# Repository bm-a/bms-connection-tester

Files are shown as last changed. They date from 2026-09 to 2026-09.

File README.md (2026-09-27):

# JBD Smart BMS RS485 Responder + Relay Test Bench — ESP32-S3

A firmware + hardware design that impersonates a **JBD / Xiaoxiang Smart BMS**
over RS485 so you can test the **meter/display** — the meter is the device
under test, not a real BMS. The box pretends to be a healthy 14S pack,
answers the meter's JBD polls with golden or fault-injected values, and an
**8-relay sequencer** switches the meter's own functions in order, driven by
a button or the built-in web dashboard. Status LEDs report link state live:
**green = valid BMS traffic seen, red = bus silent**. No screens needed.

> **New to RS485 or the JBD protocol?** Start with the companion handbook:
> **[jbd-bms-rs485-handbook](https://github.com/bm-a/jbd-bms-rs485-handbook)** —
> how RS485 works, the MAX485 module up close, the JBD frame format with worked
> examples, shopping list with search terms, and a step-by-step build guide.
> (Also known as: JBD BMS emulator, Xiaoxiang BMS simulator/tester, smart BMS
> responder, RS485 battery emulator, e-rickshaw meter tester.)
>
> **No hardware handy?** Run the offline 3D bench simulator:
> **[bms-tester-sim](https://github.com/bm-a/bms-tester-sim)** — ESP32-S3 +
> MAX485 + meter + relays in the browser, exact ESP dashboard embedded.

| | |
|---|---|
| Targets | ESP32-S3 DevKitC-1 (8 MB) + ESP32-S3 N16R8 (16 MB + OPI PSRAM) + MAX485 + 8ch relay · Waveshare ESP32-S3-ETH-8DI-8RO board variant ([docs/waveshare.md](docs/waveshare.md)) |
| Protocol | JBD UART over RS485, 9600 8N1 (registers `0x03`/`0x04`/`0x05`) |
| Releases | **v2.8** current — FULL dashboard + Waveshare in one release · `v2.7` 3 dashboard variants · `v2.6` meter estimate · `v2.5` portal/schema/harness · `v2.4` Tasmota update · `v2.3.1` bench patch · `v2.3` relay bench · `v2.2` captive portal · `v2.1` web reliability · `v2.0` relay bench · `v1.2` RGB+N16R8 · `v1.0` frozen (ZIP + tag) |
| Tests | **184 passing** via `sh run_tests.sh` (native Unity + web + Waveshare board-backend) + 30-day soak + web contract |
| Firmware | `firmware/` (8 MB) + `firmware-n16r8/` (16 MB) one-file images, SHAs in their READMEs |
| Web UI | Always-on AP `BMS-Tester` → FULL dashboard (live SVG bench, relay tiles, spoof, OTA, console) — no office Wi-Fi needed |
| Build guides | [DIY build-it-yourself](docs/BUILD-DIY.md) · [Waveshare build](docs/BUILD-WAVESHARE.md) |

## Dashboard (v2.8)

One FULL dashboard on every build — relay names are NVS-persistent, and OTA
always pulls FULL so updating never strands a box. (The old CLASSIC/LITE
page variants are retired.)

| What you get |
|---|
| Everything: live SVG bench card, relay tiles + names, meters-today, sequence config, spoof, OTA, console |

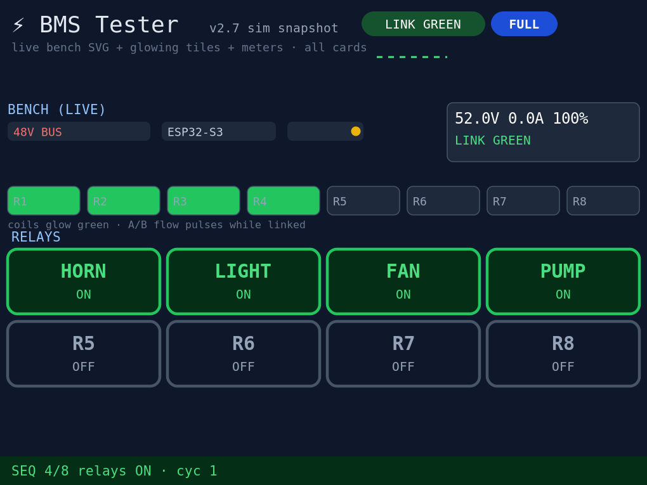
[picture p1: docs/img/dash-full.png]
FULL dashboard snapshot


*LINK pill + cycle counters, live bench strip (48V → ESP → MAX485 → meter readout), glowing relay tiles, meters-today — rendered from live sim state.*

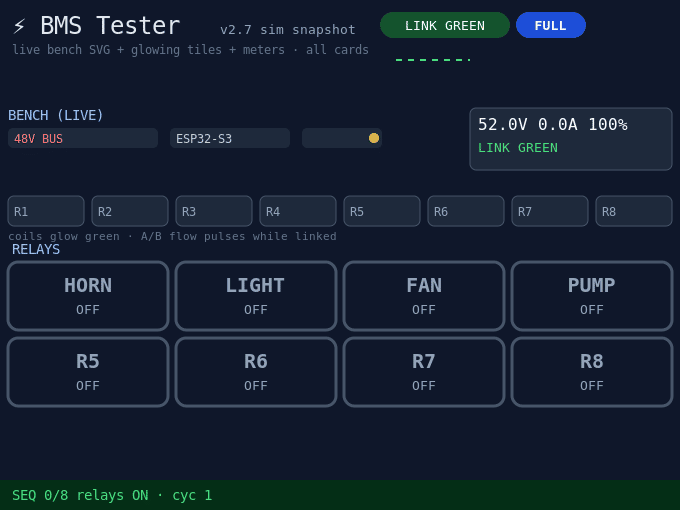
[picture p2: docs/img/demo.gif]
Sequential run + spoof demo


*R1→R8 sequential run, then a spoof FIRE driving the meter readout off golden — the same flow the 3D bench shows live.*

### Dashboard cards (FULL)

| Card | What it does |
|---|---|
| Bench (live) | Inline SVG bench card: 48 V → bucks → ESP → MAX485 with TX/RX dots → A/B flow → meter readout (`mv`/`ma`/`msoc`), 8 relay blocks glowing green. Zero CDN — works on the offline AP |
| Relays | START / STOP ALL buttons + 8 relay tiles. Tapping a tile forces it ON/OFF (`/api/relay`); forcing during CHASE idles the wave first so two relays never light at once |
| Meters today (approx) | `meters` / `attempts` / `pass` / `fail` + **New day (reset)** button. Software estimate, honestly labeled — see [Meter counter](#meter-counter) |
| Sequence config | Mode, relay count, step/hold, chase sweeps, stagger, direction, button behavior, logic, loop/pause/limit, Save. Only the active mode's fields are shown |
| Relay labels | 8 editable names, NVS-persistent (display-only; quotes/backslashes rejected) |
| Fault spoof (0x03 test values) | Pin-trigger enable + GPIO + polarity + Save trigger; stage 1 and stage 2 V/A/°C/SOC%/secs; FIRE now / Save only / Cancel |
| Firmware update | OTA status + latest tag; auto-check toggle + cadence (hours, 0 = manual); Check now / Install update; custom firmware URL + Upgrade from URL; **STA uplink** (enable + SSID/pass + Test uplink); **Backup configuration** (JSON download, passwords never included) + Restore from file |
| Admin & Wi-Fi AP | AP SSID / pass (8+, blank = keep) / channel (1–13); new admin pass (4+, blank = keep); auto-start sequence on boot (burn-in); Save / Save+reboot / Reboot / Factory reset / Reset settings (keep Wi-Fi) / Reset boot counter |
| Information | Firmware + variant, flash size, free sketch space, heap, uptime, boot count, reset reason, STA RSSI/IP, pin map for the board variant |
| Console | One-line command box: `START STOP FIRE CANCEL DAYRESET STATUS UPTIME VERSION REBOOT RESET HELP` — hardware verbs ask for the admin password |

The dashboard is open on the WPA2 AP — no login wall. Reboot, factory
reset, `/update` upload, OTA-admin and AP/admin saves ask for the admin
password **per request** (default `admin123`). Passwords never appear in
`/api/state`.

## JBD responder

The box is a virtual JBD BMS. It answers the meter's polls and nothing else:

| Register | Reply |
|---|---|
| `0x03` basic info | 52.0 V (`0x1450`), 0 A, 100 % SOC (`0x64`), 14 cells — byte-exact golden frame captured from a real pack |
| `0x04` cell voltages | 14 × 3714 mV = 52.0 V, checksum-verified synthesis |
| `0x05` device name | `TEST-14S100A` |
| writes / unknown registers | **silent** — no reply, still counted live |

- **Streaming parser + checksum**: every incoming frame is validated
  completely — line noise can never fake a link. Proven by a **10 M-byte
  structured fuzz** (pure random + valid-prefix mutations), zero emits.
- **Adaptive link window**: the green/red decision uses
  `clamp(2×EMA + 500 ms, 2 s, 10 s)` — self-adjusts to any meter poll speed.
  Green LED = well-formed frame seen inside the window; red = bus silent.
- **USB `STATUS?`**: send `STATUS?` over USB-serial (test-jig only, not a JBD
  command) → `GREEN 2.8` / `RED 2.8`. First token is stable for HIL fixtures.
- Protocol byte layout and checksum rule: [`docs/PROTOCOL.md`](docs/PROTOCOL.md).

## 8-relay sequencer

Switches the meter's own functions in order. Runs on `millis()` — no
`delay()` anywhere, RS485 keeps priority. Relays park **OFF** at boot;
all state resets clean.

| Mode | Behavior |
|---|---|
| Sequential 1-N | R1→Rn (or Rn→R1), each ON for the step delay, then the sequential hold |
| Chase wave | Single lit relay sweeping R1→Rn, wraps; **20 ms break-before-make** — each advance parks all-OFF first (release is slower than pull-in) |
| All ON at once | All N relays ON with optional stagger (0 = contactor slam, 20–1000 ms = inrush ramp) |

Config ranges (validate-then-commit: a rejected save changes **nothing**):

| Key | Range | Default |
|---|---|---|
| Relay count | 1–8 (beyond-N forced OFF; shrinking drops stale forces immediately) | 8 |
| Step ms | 100–60000 | 250 |
| Hold sequential ms | 0–3600000 (0 = stay ON) | 30000 |
| Chase sweeps | 0–100 (0 = forever; auto-hold = sweeps × relays × step) | 3 |
| Hold all-on ms | 0–3600000 (0 = stay ON) | 300000 |
| All-ON stagger ms | 0–1000 (0 = all at once) | 50 |
| Direction | R1→Rn / Rn→R1 | R1→Rn |
| Button | Hold X ms, re-press=OFF / Run to end, ignore presses / Re-press restarts | Hold X ms |
| Logic | Active-LOW (SmartElex) / Active-HIGH (no-op on Waveshare — TCA9554 bit HIGH = ON) | Active-LOW |
| Loop cycles | on/off + pause 500–60000 ms + cycle limit 0–60000 (0 = ∞) | off / 2000 / 0 |
| Auto-start on boot | burn-in racks | off |

Safety rules, enforced in firmware and host-tested:

- **0.5 s post-STOP dead-band** — START inside it is refused ("relays
  settling"); a refused start opens no attempt.
- **Mode switch needs IDLE** — switching mode with relays live is rejected.
- **Loop needs a finite hold** — hold 0 never expires, so loop + hold 0 is refused.
- **RESTART keeps tile forces**; count-shrink clears stale forces, never resurrects them.
- **Actuations counter** counts turn-ON edges only; **cyclesDone** counts
  completed cycles. Both surface on the dashboard and in `STATUS`.

## Meter counter

Software-only **estimate** of units tested per day — no button, no extra
GPIO, no RTC. The JBD protocol carries no meter ID, so the box watches link
gaps and applies one documented workflow assumption: a failed/retried test
does **not** unplug the meter (link stays GREEN); a new meter means a
physical reseat (link drops to RED for seconds).

- Link gap **≥ 3 s** arms a reseat **candidate**; the new meter **commits
  only after GREEN holds 5 s** (fumble guard — seat 4 s, pull, seat properly
  = one unit, not two).
- Sub-3 s flickers (slow poll, noise) stay on the same meter.
- Steady GREEN across RESTARTs/retries = same meter, however many attempts.
- The closing meter's verdict is snapshotted at arm time, so an eager START
  during the settle window attributes to the **new** meter.
- A **mid-cycle yank invalidates the test**: the previous meter closes as
  fail (no completed cycle while validly under test).
- Dashboard shows **meters / attempts / pass / fail** (pass = a full cycle
  completed before the swap). **New day (reset)** is manual — no RTC; boot
  persists (a power flicker never eats QC data); backups exclude counters.
- NVS is coalesced: **≤ 1 write per meter** — a power cut loses at most the
  current meter's attempts, stated on the card, not hidden.

## Fault spoof

Makes the meter display abnormal `0x03` data — tests how the **meter
renders** bad values. It does not trip real BMS protections (there is no
real BMS here). `0x04`/`0x05` never change.

Two stages, each fully editable (V/A/°C in ×0.1 units, SOC %, seconds):

| | V | A | °C | SOC | Secs | Range |
|---|---|---|---|---|---|---|
| Stage 1 (realistic full pack) | 100.0 | 100.0 | 100.0 | 100 % | 5 | values 0–999.9, secs 1–120 |
| Stage 2 (over-range pattern) | 88.8 | 88.8 | 88.8 | 188 % | 10 | values 0–999.9, secs 1–120 |

- **FIRE now** = save + fire; **Save only** stages values + pin without
  firing; **Cancel** aborts a running plan (auto-reverts after stage 2).
- **Trigger group**: enable + GPIO + polarity (pull-LOW to fire with
  pull-up / pull-HIGH to fire). Save trigger stores the triple without
  firing — for physical-switch users.
- Safe trigger pins, anything else falls back: generic boards
  `1, 2, 21, 38–44, 47` (fallback **21**); Waveshare `DI1–DI8`
  (`GPIO4–11`, active LOW, fallback **DI1**).

## Admin, network & OTA

- **Always-on AP** `BMS-Tester` (WPA2), fixed gateway **192.168.4.1**,
  captive portal with landing page (Safari/Chrome steps), mDNS
  **`bmstester.local`** for laptops/desktops. Turn mobile data off if the
  phone routes around the portal.
- **STA uplink** (optional, for GitHub OTA only — the AP stays on): enable +
  SSID + pass, one-shot **Test uplink** (joins ≤ 30 s without rebooting,
  reports RSSI/IP, drops back to AP-only).
- **OTA**: checks `https://api.github.com/repos/bm-a/bms-connection-tester/releases/latest`
  — one unified v2.8 line, Waveshare included. Exact variant-asset match
  (`firmware.bin` / `n16r8-firmware.bin` / `waveshare-firmware.bin`);
  Tasmota-grade gates: `0xE9` magic + flash-size-vs-chip gate on the first
  bytes, explicit sketch budget (never `SIZE_UNKNOWN`), exact variant match
  (no 8 MB ↔ N16R8 cross-flash). Auto-check cadence editable (0–720 h,
  0 = manual) + Check now + Install update. A wrong file or password changes
  nothing — the box keeps running.
- **Custom firmware URL** + **Upgrade from URL** (Tasmota OtaUrl style).
- **Manual `/update` upload**: works fully offline, progress bar, same gates.
- **Backup / Restore**: whole config as sectioned JSON
  (`relays`/`spoof`/`trigger`/`network`/`ota`/`meta`, `{"config":2,...}` —
  see [`docs/CONFIG-SCHEMA.md`](docs/CONFIG-SCHEMA.md)). **Passwords never
  leave the box** (they are in no section, by design). v1 flat backups still
  migrate.
- **Reboot** (flushes pending saves first), **Factory reset** (wipes NVS +
  reboots; also: hold the button 10 s), **Reset settings (keep Wi-Fi)** —
  wipes bench settings but keeps AP/STA/admin identity, **Reset boot
  counter** (no reboot needed).
- **Coalesced NVS saves**: config writes batch, never stall the loop.
- **Console verbs**: `START STOP FIRE CANCEL DAYRESET STATUS UPTIME VERSION
  REBOOT RESET HELP` — hardware verbs (`START STOP FIRE CANCEL DAYRESET
  REBOOT RESET`) require the admin password; `STATUS` prints link state,
  run state, cycles, actuations, spoof stage, and the meter counters.

## Hardware — generic DIY build

Full step-by-step: [docs/BUILD-DIY.md](docs/BUILD-DIY.md). Pin map:

| Module | Role | Pins |
|---|---|---|
| ESP32-S3 DevKitC-1 / N16R8 | Application MCU (240 MHz LX7, native USB) | UART2 TX = GPIO17, RX = GPIO16 |
| MAX485 (or SP3485) | Half-duplex RS485 transceiver | DI ← TX17, RO → RX16, DE+RE ← GPIO4 (**10 kΩ pull-down** — boots in listen mode, never jams the bus) |
| Green / red LEDs | Link indicator (mutually exclusive) | GPIO10 / GPIO11 via 220 Ω; GPIO48 RGB mirrors |
| 8ch relay module | Switches meter functions in sequence | IN1–8 ← GPIO5/6/7/8/9/12/13/14; **separate 12 V supply, common GND** |
| Button | Starts/stops sequences | GPIO15 to GND (pull-up); 10 s hold = factory reset |
| WiFi kill | Drops the AP | GPIO18 to GND (pull-up); ground = AP off, release = restore |
| Spoof trigger | Fires the 2-stage plan | GPIO21 to GND (configurable, safe pins only) |

Power: USB for the ESP + 12 V for the relay coils. Full wiring, relay
supply, and troubleshooting in [`docs/MODULES.md`](docs/MODULES.md).

## Hardware — Waveshare ESP32-S3-ETH-8DI-8RO

Full step-by-step: [docs/BUILD-WAVESHARE.md](docs/BUILD-WAVESHARE.md).
Details in [`docs/waveshare.md`](docs/waveshare.md).

| Function | Mapping |
|---|---|
| Relays R1–R8 | TCA9554PWR @ I2C `0x20` (SDA42/SCL41); EXIO1–8 = bits 0–7, **bit HIGH = ON**; parked OFF at boot. The web "active-low" toggle is a **no-op** on this board |
| RS485 | Isolated transceiver, TX17/RX18, **hardware auto direction** — no DE pin |
| BOOT button | GPIO0 = START/STOP (holding at power-on enters download mode — normal) |
| DI1 (GPIO4) | Spoof trigger (default, web-changeable; DI1–DI8 = GPIO4–11, opto-isolated, active LOW) |
| DI2 (GPIO5) | WiFi kill (default; ground = AP off) |
| RGB status | GPIO38 |
| W5500 Ethernet | Pins reserved, **not implemented** — Wi-Fi kept |

## Build environments

`platformio.ini` — one FULL dashboard on every build (classic/lite retired):

| Env | Board | What |
|---|---|---|
| `esp32-s3-devkitc-1` | ESP32-S3 8 MB | FULL dashboard (default) |
| `s3-n16r8` | 16 MB + OPI PSRAM | FULL dashboard, N16R8 flash/PSRAM map |
| `s3-waveshare` | Waveshare ESP32-S3-ETH-8DI-8RO | FULL dashboard, TCA9554 relays, isolated RS485 |
| `s3_tests` / `native` | host | on-target / host unit tests |

**v2.8 ships FULL (generic) + Waveshare.** OTA assets stay FULL on every
line so updating never strands a box.

## Flash it

- **Ready binaries (esptool, any PC):** `pip install esptool`, then one
  command per image — merged bootloader+partitions+app, structure-verified:
  `esptool.py --chip esp32s3 --port PORT --baud 460800 write-flash 0x0 <image>`
  - Generic 8 MB: `firmware/bms-tester-8mb.bin`
  - N16R8: `firmware-n16r8/bms-tester-n16r8.bin`
  - Waveshare: `bms-tester-waveshare.bin` (v2.8 release asset) at `0x0`
- **PlatformIO:** upload `esp32-s3-devkitc-1`, `s3-n16r8`, or `s3-waveshare`.
- **Arduino IDE:** open `arduino/bms_connection_tester/bms_connection_tester.ino`
  (all tabs open automatically; ESP32S3 Dev Module, USB CDC On Boot Enabled,
  921600; N16R8 also Flash 16MB + OPI PSRAM).

## Verify it

```sh
sh run_tests.sh          # 166 Unity tests: checksum, logic, parser, stress,
                        # relay, spoof, meter, ota, upload, web, system,
                        # waveshare board-backend + web contract + 30-day soak
pio test -e native       # host Unity suite (same asserts as run_tests.sh)
pio run -e esp32-s3-devkitc-1 -e s3-n16r8 -e s3-waveshare   # firmware compiles
```

- Socket harness (`tools/fw_emu`, real handlers over real HTTP): portal,
  relay flows, spoof/trigger, uploads, backup/restore, console, resets,
  STA/OTA, info, meter heuristic — PASS.
- 30-day soak (2.59 M polls, rollover crossed): PASS.
- Virtual bus (`sh tools/virtual_bus.sh`): 03/04/05 golden, silences,
  resync, red-after-silence — PASS.
- Dashboard + portal pages: `w3m -dump` renders verified; JS `node --check`
  clean; JS↔firmware contract gate green.
- HIL pytest (`tools/`) when a real ESP32-S3 + RS485 adapter is attached.
- QEMU-S3: parked (Stage-0 flash model clean; guest resets in 2nd-stage
  bootloader) — see HANDOFF.md.

## Versions

| Version | Highlights |
|---|---|
| **v2.8** | Meter counter hardened: 3 s gap arms a reseat candidate, new meter commits after GREEN holds **5 s** (fumble guard); verdict snapshotted at arm time (eager START attributes to the new meter); mid-cycle yank = fail. **Unified release line — Waveshare included**, OTA via `releases/latest` for all variants. Ships FULL (generic) + Waveshare. 166/166 tests |
| v2.7 | Three dashboard variants (FULL default + `s3-classic` + `s3-lite`), live SVG bench + meter readout (`mv`/`ma`/`msoc`), persistent relay names everywhere, OTA stays FULL. Waveshare `v2.7-ws1` prerelease line |
| v2.6 | Software-only daily meter estimate (link gaps = new meter, no button/GPIO), round link dots, one-file merged flash images, `test_meter` + web/emu meter coverage |
| v2.5 | Trigger save, portal landing, structured config (`docs/CONFIG-SCHEMA.md`), on-demand STA, whitespace-tolerant JSON, socket harness + 30-day soak |
| v2.4 | Tasmota-grade update path, per-mode relay menu (chase BBM, stop dead-band, timing floors), spoof save-only, console, backup/restore, custom OTA URL, STA uplink test, info card, mDNS, keep-WiFi/bootcount resets |
| v2.3.1 | No login wall (per-request admin password), sticky saves, UTF-8 pages, chase auto-sweeps, spoof trigger GPIO, WiFi kill switch (GPIO18), working OTA check + Install button |
| v2.3 | Relay count + chase, 2-stage spoof, per-mode ms holds, industrial pack (loop/pause/limit/stagger/direction/labels/counters/autostart), persistent logins, manual + auto OTA, coalesced saves |
| v2.2 | Captive portal (login page pops on join) + fixed 192.168.4.1 |
| v2.1 | Website reliability: 14 host-executed web tests + contract gate, 24 h office-day sim |
| v2.0 | 8-relay sequencer + always-on AP dashboard + spoof window + admin auth. Responder core frozen |
| v1.2 | Onboard RGB mirror (GPIO48) + N16R8 16 MB/OPI build + Wokwi NeoPixel |
| v1.1 | Multi-register (03/04/05) + adaptive window + silence-on-unknown + hardened parser |
| v1.0 | 0x03-only responder, fixed 2 s window. Frozen: `releases/bms-connection-tester-v1.0.zip` + tag |

See [`CHANGELOG.md`](CHANGELOG.md) for full notes.

## Layout

`src/` firmware (protocol core + relay ctrl + web UI + OTA logic) ·
`docs/` module + protocol docs + the two build guides ·
`test/` 166 Unity tests · `tools/` socket harness, virtual bus, soak, HIL
pytest, QEMU script · `arduino/` IDE sketch · `firmware/` 8 MB one-file
image · `firmware-n16r8/` N16R8 one-file image · `wokwi/` browser sim ·
`local-wokwi/` offline 3D bench (sim server + Three.js bench + verbatim ESP
page) · `enclosure/` IP65 standalone box + GX16 meter link docs ·
`captures/` Docklight recordings · `scripts/` Linux/Termux setup ·
`wiki/` wiki sources (mirrors the [GitHub wiki](../../wiki)) ·
`.github/workflows/` CI.

Docs: [`docs/MODULES.md`](docs/MODULES.md) (wiring, relay supply, power,
troubleshooting) · [`docs/PROTOCOL.md`](docs/PROTOCOL.md) (byte layout,
checksum) · [`docs/CONFIG-SCHEMA.md`](docs/CONFIG-SCHEMA.md) (backup shape,
validation, migration) · [`docs/waveshare.md`](docs/waveshare.md) (board
variant) · [`docs/EMULATION-v2.5.md`](docs/EMULATION-v2.5.md) (harness
methodology). Wiki: [Home](../../wiki/Home) · [Hardware](../../wiki/Hardware)
· [Relays](../../wiki/Relays) · [Dashboard](../../wiki/Dashboard) ·
[Protocol](../../wiki/Protocol) · [Flashing](../../wiki/Flashing) ·
[Emulators](../../wiki/Emulators) · [Versions](../../wiki/Versions).

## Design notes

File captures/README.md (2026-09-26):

# captures/ — original recordings (ground truth)

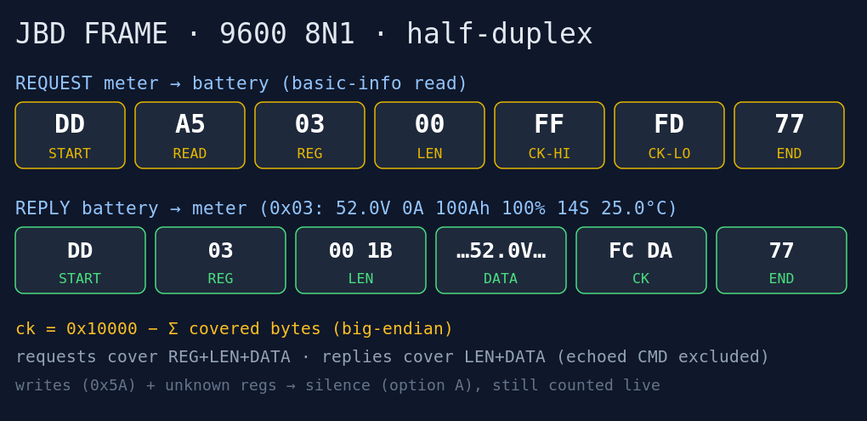
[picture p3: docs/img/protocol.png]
JBD frame map


- `SOC-DOCKLIGHT.xlsx` — raw Docklight captures from the real battery + real meter:
  the fixed `DD A5 03 00 FF FD 77` request, SOC 100 % / 50 % replies, a 90 %/45 °C
  long frame, two 0x2A variants, charge/discharge frames, and a Modbus RTU frame
  also seen on the bus (`01 03 00 00 00 1D 85 C3`, out of scope).

Used as regression vectors in `test/test_checksum/`. Frames whose checksums match
no formula (charge/discharge captures) are documented and excluded, not used.

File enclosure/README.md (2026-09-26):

# Standalone tester enclosure — IP65 box + 48 V dual-buck + GX16 meter link
v2.6 · software builder + dad (electronics) split. Every electrical value dad
owns is marked `DAD:` — software never guesses amps.

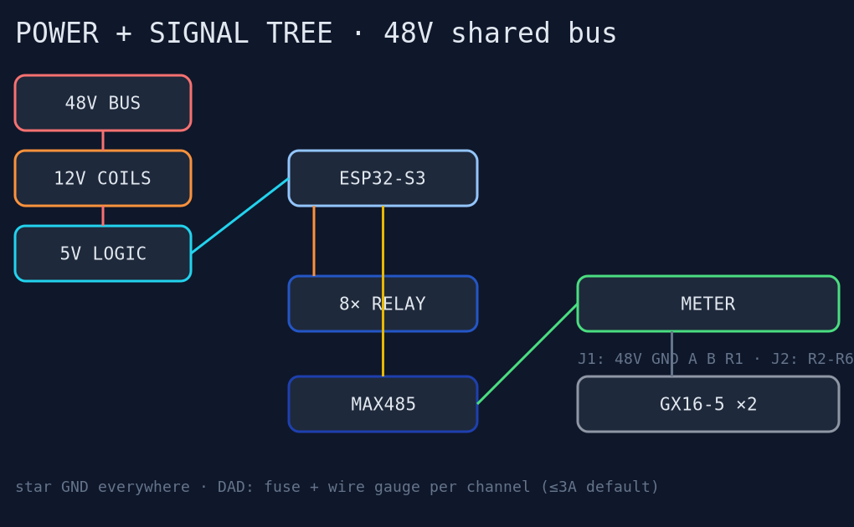
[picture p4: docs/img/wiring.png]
Power and signal tree


The device this box tests — e-rickshaw meter cluster:

## Power tree (48 V shared with meter)
```
48V IN (shared bus, fused) ─┬─ buck 48→12V (coils only) ── relay JD-VCC
                            └─ buck 48→5V (logic) ── ESP 5V + MAX485 side
                            star GND: 48V GND = ESP GND = relay GND = meter GND
```
- `DAD:` 48 V inlet fuse rating + wire gauge (default print: logic 22 AWG, relay loads 18 AWG, 48 V feed 18 AWG — confirm).
- `DAD:` buck module part numbers + current ratings (coils ~8×75 mA + margin; logic ~1 W + WiFi radio margin — confirm).
- Reverse-polarity diode + TVS on 48 V inlet. Fuse holder accessible without opening lid.

## Box + panel (off-shelf IP65 polycarbonate ~240×190×90 mm — `DAD:` confirm size)
- Zones: left logic tray (S3 + MAX485 + DE 10 kΩ pulldown + 220 Ω LED resistors),
  middle 8-ch relay on standoffs, right power corner (2 bucks + fuse + TVS), lid desiccant + wiring label.
- Front panel (etched acrylic, charcoal + orange): green/red link bezels
  (GPIO10/11), RGB window (GPIO48), illuminated green START (GPIO15→GND, momentary),
  yellow SPOOF (GPIO21→GND, momentary), **maintained metal WiFi-kill toggle with
  guard cover (GPIO18→GND)** + amber "AP OFF" jewel, USB-C service pigtail with
  dust cap, QR → `192.168.4.1` + `bmstester.local`.
- Glands: PG9 48 V, PG7 RS485 A/B twisted pair, PG13.5 relay/GX16 tails.

## GX16-5 meter link (DEFAULT — dad replaces with real 10-pin table)
| Conn | 1 | 2 | 3 | 4 | 5 |
|---|---|---|---|---|---|
| J1 BUS | 48V | GND | A | B | R1 line |
| J2 LOADS | R2 | R3 | R4 | R5 | R6 |
| AUX pigtail | R7 | R8 | — | — | — |
`DAD:` overwrite this table with the meter's real pinout. Sim + 3D read
`sim_server.py GX16` dict — a 5-minute re-map, no rework. Relay COM feed:
tester pulls lines LOW, meter side sources its own lamp returns (`DAD:` confirm
dry-contact vs driven; if driven, add per-channel fuse ≤3 A default).

## Assembly + power-on test (dad's bench sheet)
1. Bucks first, no ESP: 48 V in → verify 12.0 V + 5.0 V at terminals (`DAD:` tolerances).
2. Logic: USB flash, boot RED → meter plugged via J1 → GREEN ≤1 s, serial polls 03/04/05.
3. Loads: web START → R1..R8 click in order → meter tell-tales follow (see sim).
4. Kill tests: J1 unplug → RED ~2 s; GPIO18 toggle → AP drops, USB STATUS? alive.
5. Soak: 1 h run, bucks warm-not-hot (`DAD:` thermal call), glands strain-relieved.

## Sim mapping (software side)
`local-wokwi/` mirrors all of the above: 48 V rail + both bucks + fuse lamp in 3D,
GX16 sockets with pin numbers, photo-textured meter, WiFi toggle (GPIO18),
`/esp/` exact firmware page in scrollable row. `/api/gx16` serves the live table.

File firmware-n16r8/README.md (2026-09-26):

# Ready-to-flash binaries — v2.8 (ESP32-S3 N16R8, 16 MB flash + OPI PSRAM)

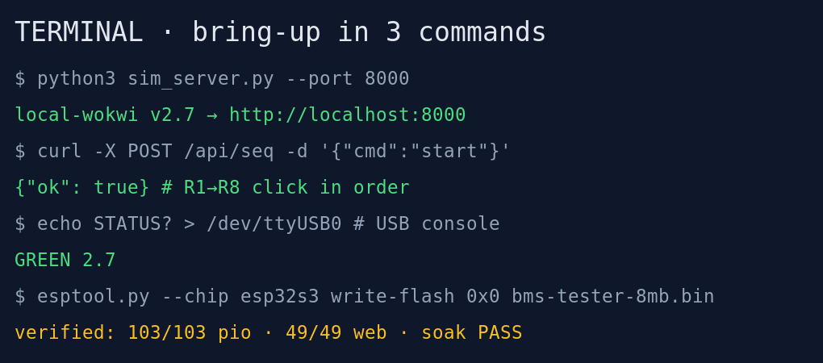
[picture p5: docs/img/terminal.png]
Bring-up terminal


Built 2026-09-27 from this exact source (`pio run -e s3-n16r8`,
Xtensa GCC 8.4.0, Arduino 2.0.x). Same firmware logic as `firmware/`,
only the flash/PSRAM map differs. Use for N16R8 boards (16 MB flash,
8 MB octal PSRAM, onboard WS2812 on GPIO48).

Includes the v2.8 bench (meter counter with 5 s settle fumble guard,
daily meter heuristic, round link dots, trigger save, portal landing,
structured config, on-demand STA, Tasmota-grade update path, per-mode
relay menu, console, backup/restore, info card,
mDNS) + always-on AP dashboard (`BMS-Tester`, captive portal, no login
wall) + 2-stage spoof (100 first, then 88.8/188) + manual/auto OTA.
v1.x responder behavior frozen.

## Flash with esptool — ONE file, ONE command (any PC, no IDE needed)
1. `pip install esptool`
2. Plug in the S3, find the port (COMx / /dev/ttyACM0), then:

```
esptool.py --chip esp32s3 --port <PORT> --baud 460800 write-flash 0x0 bms-tester-n16r8.bin
```

`bms-tester-n16r8.bin` is the merged image (bootloader + partitions + app
at their offsets) — one file, flashed to `0x0`, done.

## Or browser flash (no installs)
Open an ESP Web Tools flasher (e.g. https://www.espthings.io/tools/esp32-flasher/),
load `bms-tester-n16r8.bin` at `0x0`, flash, done.

## Or the 3 separate files (advanced / partial re-flash)
```
esptool.py --chip esp32s3 --port <PORT> --baud 460800 write-flash \
  0x0 bootloader.bin \
  0x8000 partitions.bin \
  0x10000 firmware.bin
```

## Verify
- `bms-tester-n16r8.bin` (1,078,304 bytes)
  SHA-256: `748355908e000215ef78ca9221db47167609278d3c90cba1361621e35c4f5676`
- `firmware.bin` (1,012,768 bytes)
  SHA-256: `e805e98220763dfd275b4cdfbe9d61e17d394e9abb99e5dd0ff03bf349c90aa6`
- `bootloader.bin` (15,104 bytes)
  SHA-256: `1776e4dd896a69d0a5c2e79957b0e2a88aa4129b1381d6478683515a1f6af343`
- `partitions.bin` (3,072 bytes)
  SHA-256: `bd0f7954aca2ef7d925ee21aaa1f3dc8822d1d6ce5cbbd26a135e5886bfff6ce`
- Golden reply bytes, `2.8` version, `BMS-Tester` AP name and dashboard
  strings verified byte-present inside `firmware.bin`; merged image verified
  (bootloader `E9` @0x0, partition magic @0x8000, app `E9` @0x10000).

Behavior: identical to the 8 MB build — boots red, relays OFF, AP up,
green on valid JBD polls (discretes + onboard RGB mirror).

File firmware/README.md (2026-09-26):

# Ready-to-flash binaries — v2.8 (ESP32-S3 DevKitC-1, 8 MB flash)

Bring-up terminal

Built 2026-09-27 from this exact source (`pio run -e esp32-s3-devkitc-1`,
Xtensa GCC 8.4.0, Arduino 2.0.x). Use for 8 MB boards and for Wokwi.
For 16 MB N16R8 boards use `firmware-n16r8/` instead (same logic, 16 MB map).

Includes the v2.8 bench (meter counter with 5 s settle fumble guard,
daily meter heuristic, round link dots, trigger save, portal landing,
structured config, on-demand STA, Tasmota-grade update path, per-mode
relay menu, console, backup/restore, info card,
mDNS) + always-on AP dashboard (`BMS-Tester`, captive portal, no login
wall) + 2-stage spoof (100 first, then 88.8/188) + manual/auto OTA.
v1.x responder behavior frozen.

## Flash with esptool — ONE file, ONE command (any PC, no IDE needed)
1. `pip install esptool`
2. Plug in the S3, find the port (COMx / /dev/ttyACM0), then:

```
esptool.py --chip esp32s3 --port <PORT> --baud 460800 write-flash 0x0 bms-tester-8mb.bin
```

`bms-tester-8mb.bin` is the merged image (bootloader + partitions + app at
their offsets) — one file, flashed to `0x0`, done.

## Or browser flash (no installs)
Open an ESP Web Tools flasher (e.g. https://www.espthings.io/tools/esp32-flasher/),
load `bms-tester-8mb.bin` at `0x0`, flash, done.

## Or the 3 separate files (advanced / partial re-flash)
```
esptool.py --chip esp32s3 --port <PORT> --baud 460800 write-flash \
  0x0 bootloader.bin \
  0x8000 partitions.bin \
  0x10000 firmware.bin
```

## Verify
- `bms-tester-8mb.bin` (1,075,808 bytes)
  SHA-256: `28248551fa8d32e061f75d46cb2bcd4559d1c40dd750e2422b412bf5353a98f8`
- `firmware.bin` (1,010,272 bytes)
  SHA-256: `27d5e25c86c0a97b383a55b326311cdd32296ec4772bbc243d645a4fe25616a8`
- `bootloader.bin` (15,104 bytes)
  SHA-256: `1776e4dd896a69d0a5c2e79957b0e2a88aa4129b1381d6478683515a1f6af343`
- `partitions.bin` (3,072 bytes)
  SHA-256: `1d9cca96de0fe07ad7fc0648b9878ddecd9ce565e38b589ad20fea698ed4c80c`
- Golden reply bytes (`DD 03 00 1B 14 50 … FC DA 77`), `2.8` version,
  `BMS-Tester` AP name and dashboard strings verified byte-present inside
  `firmware.bin`; merged image verified (bootloader `E9` @0x0, partition
  magic @0x8000, app `E9` @0x10000).

Behavior: boots red (discretes + onboard RGB), relays OFF (no click),
AP `BMS-Tester` up immediately; green ≤ 1 s after first valid JBD poll.

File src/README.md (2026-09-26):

# src/ — tester firmware

JBD frame map — what the parser speaks

- `bms_protocol.h` / `bms_protocol.cpp` — hardware-independent core (FROZEN
  since v1.x): JBD checksum, streaming parser, reply dispatcher (option A),
  adaptive tracker, canned frames, `FW_VERSION` (`"2.8"`).
- `relay_ctrl.h` / `relay_ctrl.cpp` — hardware-independent bench add-on:
  8-relay sequencer (sequential/all-ON/chase, relay count, 3 button behaviors,
  per-mode holds/sweeps, loop/pause/limit, stagger, direction, QC counters,
  chase break-before-make, post-stop dead-band, run-register snapshots),
  v2.6 `MeterBatch` link-gap meter heuristic (host-tested, no extra GPIO),
  debounced inputs, 2-stage spoof plan + frame builder, NVS-backed config
  struct. Host-tested (`test_relay`, `test_spoof`, `test_meter`).
- `fw_upload.h` — hardware-independent update gates (Tasmota rules: explicit
  sketch budget, exact variant-asset match, image-head check, one error
  vocabulary). Host-tested (`test_upload`); enforced by both update paths.
- `ota.h` / `ota.cpp` — hardware-independent OTA decision logic: version
  compare, per-variant asset pick, download URL, auto-check gate.
  Host-tested (`test_ota`); network I/O lives in `main.cpp` (ESP-only).
- `web_ui.h` / `web_ui.cpp` — ESP-only: always-on AP + captive portal, no login wall (admin password per sensitive request),
  per-mode dashboard (relays/sequence/labels/spoof/firmware/admin/info/console),
  NVS v3 load/save + v2 migration, STA uplink + one-shot test, Tasmota-grade
  manual `/update` upload, config backup/restore, custom OTA URL, mDNS.
  Host-tested on stubs (`test_web`).
- `main.cpp` — Arduino sketch: frozen RS485 RX → parse → reply path, 250 ms
  LED eval, `STATUS?` (`GREEN 2.6` / `RED 2.6`), plus relay/web/spoof/OTA
  handling (all non-blocking, RS485 keeps priority; v2.6 meter heuristic is
  fed inside `web_tick()`).

Pins: TX=17, RX=16, DE=4, green LED=10, red LED=11, onboard RGB=48 (WS2812,
`neopixelWrite`, no extra library), relays R1–R8 = 5/6/7/8/9/12/13/14,
button=15, spoof=21. UART2 @ 9600 8N1.
Compiles with `pio run -e esp32-s3-devkitc-1` (8 MB, Wokwi) or
`pio run -e s3-n16r8` (16 MB flash + OPI PSRAM).

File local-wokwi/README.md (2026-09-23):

# local-wokwi — offline browser simulator for this BMS tester

FULL dashboard snapshot

Sequential + spoof demo

Your own mini-Wokwi that runs on your phone / laptop with **no internet**.
Same idea as wokwi.com: virtual board + LEDs + buttons + relays + serial log,
driven by the real `../wokwi/diagram.json` wiring in this repo.

## Files

| File | What it is |
|---|---|
| `sim_server.py` | Localhost server (stdlib Python only, no pip packages). Loads `../wokwi/diagram.json`, ticks the simulation ~1/s, serves the UI + JSON API. |
| `bench3d.html` | **Default page (`/`).** True-3D bench (Three.js CDN): one tester ESP32-S3 + MAX485 module (DE direction LED) + e-rickshaw **meter device with live LCD** (V/A/Ah/SOC/cells/temp per polled register, spoof values appear on screen) + 8 relay modules with coil lamps + load lamps, color-coded tube wires, poll/reply pulse packets, orbit/zoom, tap-to-press buttons/meter keys/relay boxes. Below it: a fully interactive mirror of the real ESP32 webpage (relay grid, meters-today, sequence config, spoof card, console) + serial pane. `/board` keeps the old flat 2D view. |
| `board.html` | Legacy flat 2D bench (Wokwi-style SVG). Kept at `/board`. |

## Run (30 seconds)

```sh
cd ~/bms-connection-tester/local-wokwi
python3 sim_server.py --port 8000
```

Then open in any browser (phone Chrome works, offline OK):

```
http://localhost:8000
```

- ▶ **Play** / ⏸ **Stop** the sim clock.
- **Relay board row**: 8 glowing tiles (tap = force ON/OFF, IDLE-only lock
  like the box) + START/STOP + editable names that persist to
  `labels.json` (mirrors NVS labels on hardware) and sync into the `/esp/`
  page tiles.
- Tap any 3D **button** part (BUTTON / SPOOF / WiFi toggle / OTA check /
  FACTORY RESET-hold) — relays sequence, serial logs it.
- **Serial** pane shows the meter polling `DD A5 03/04/05 …` and the tester replying `52.0V 100Ah 100%`, green LED on.
- Dropdown loads the other portfolio demos too (`portfolio-01-relay-web`, `portfolio-02-climate-mqtt`, `portfolio-03-bms-rs485` from `~/firmware-gig-kit/demo-out/`).

## What it simulates (BMS tester mapping)

From `../wokwi/diagram.json` + `../wokwi/README.md`:

- `dut` (ESP32-S3) + `meter` (second S3 as virtual meter, UART cross-wired 17↔16) → serial shows the poll/reply loop.
- `ledG` / `ledR` → green = traffic seen / link good, red = bus silent (same semantics as the real box).
- `btn` (GPIO15) → runs the relay sequence on `rl1…rl8`; `spoofbtn` (GPIO21) → 10 s test values on the meter console.
- `rl1…rl8` (GPIO 5/6/7/8/9/12/13/14) → ON/OFF states shown live.

## Honest limits

- Runs firmware **logic models**, not the compiled ESP32 binary — same class of limit as Wokwi itself (which also doesn't emulate WiFi; see `../wokwi/README.md`).
- For bit-exact binary boot, use `~/esp32s3-qemu-arm64` on real Linux (QEMU JIT can't run inside Termux proot).
- For proof-grade firmware checks, use the repo's real gates: `pio test -e native`, `sh run_tests.sh`, `sh tools/check_ino.sh`.

## Why it exists (client trust)

Screen-record 30 s of Play ▶ + serial `BOOT …` + green LED and attach it to the
Fiverr/Upwork delivery ZIP. Buyers who *see* the sim running approve 10× faster
than buyers who only get a `.bin`. See `~/firmware-gig-kit/GIGS.md` for the gig pack.

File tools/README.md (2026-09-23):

# tools/ — test helpers and scripts

Sequential + spoof demo — what the harnesses prove on the bench

- `virtual_meter.py` — PC program that pretends to be the meter. Scenario modes for
  bench testing without hardware:
  `python3 tools/virtual_meter.py PORT [--reg 03|04|05] [--period S] [--jitter S]`
  `[--mode normal|slowstop|noise|write|unknown] [--count N]`
- `test_hardware.py` — pytest hardware-in-loop: exact golden reply + GREEN→RED timing
  via `STATUS?`. Needs `HIL_BUS_PORT` (RS485 adapter) + `HIL_CDC_PORT` (S3 USB).
  Skips itself when no hardware is present.
- `run_qemu_s3.sh` — boots `firmware/firmware.bin` on an emulated ESP32-S3
  (Espressif QEMU fork) and checks `STATUS?`. Needs a **real Linux/Mac** — QEMU's JIT
  cannot start inside phone proot sandboxes (documented abort in static glib init).
- `dut_emu.cpp` + `raw_meter.py` + `virtual_bus.sh` — virtual-bus emulation
  without any ESP32 (Debian/proot or Linux, needs socat + g++): `dut_emu`
  links the real `src/bms_protocol.cpp` and speaks JBD over a PTY;
  `raw_meter.py` runs every scenario over raw-fd I/O (pyserial's modem ioctls
  fail on proot PTYs, so no pyserial here); `sh tools/virtual_bus.sh` runs
  the whole cycle in one shell and asserts RED→GREEN→RED. Exit 0 = PASS.
- `check_web_contract.py` — consistency gate: every dashboard `fetch()` has a
  firmware route, every element id exists (incl. dynamic `lblN` tile ids),
  every state key is emitted, every POSTed key is consumed (incl. `/api/ota`,
  `/api/meter` and the `/update` upload form). Runs in `run_tests.sh` + CI; exit 0 = PASS.
- `make_report.py` — generates the Word report (`RS485-Tester-Report.docx`).
- `fw_emu/` — socket harness: the REAL `web_ui.cpp` + relay + spoof served
  over real HTTP with virtual time. Build: `g++ -DARDUINO -I tools/fw_emu
  -I src src/bms_protocol.cpp src/relay_ctrl.cpp src/web_ui.cpp
  tools/fw_emu/emu_main.cpp -o fw_emu`, then `FW_EMU_PORT=18080 FW_EMU_CTL=18081
  ./fw_emu &`. Control port: `/__time?ms=N` (step clock),
  `/__link?up=` (STA uplink), `/__bus?up=` (RS485 bus LEDs + v2.6 meter
  heuristic), `/__update`, `/__flags`, `/__chip`, `/__nvs` (commit counter).
  Drivers: `drive_emu.py` (62 scenario checks) + `drive_soak.py` (48 virtual
  hours, 10 checks).

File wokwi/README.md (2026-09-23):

# wokwi/ — browser simulation (no hardware needed)

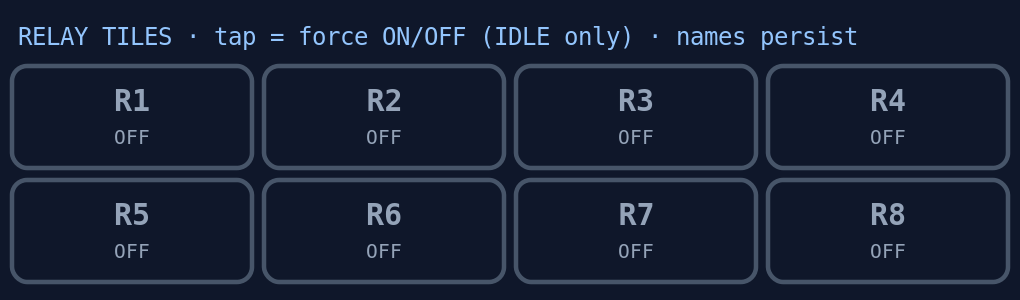
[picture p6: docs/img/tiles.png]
Relay tiles — the sim drives these


*Prefer offline? Same idea, phone-hosted, with 3D:
[local-wokwi/](../local-wokwi/) ([bms-tester-sim](https://github.com/bm-a/bms-tester-sim)).*

- `diagram.json` — ESP32-S3-DevKitC-1 + green/red LEDs + onboard RGB (NeoPixel
  on GPIO48: DIN/VDD/VSS per official docs) + **8 relay-module parts
  (GPIO 5/6/7/8/9/12/13/14, npn = energize-on-LOW like the real bench module,
  NO-contact indicator LEDs)** + button (GPIO15) + spoof button (GPIO21, both `1.l`/`2.l`
  per docs) + second S3 board acting as the meter (UART cross-wired,
  logic-level RS485 equivalent).
- `meter.ino` — virtual meter firmware: cycles registers 0x03/0x04/0x05 every second
  and prints whatever the tester replies.
- `wokwi.toml` — project config pointing at the PlatformIO build artifacts.
- `sim.yaml` — headless automation scenario (needs `WOKWI_CLI_TOKEN`):
  meter replies → button press → relay pins LOW in sequence → spoof press →
  `22 B0` on the meter console. CI runs it when the secret exists.

Open in wokwi.com (ESP32-S3 project), upload `firmware.bin` as custom firmware,
press play: watch the tester answer every poll and the LEDs follow. Press the
button to run the relay sequence (v2.0), the spoof button for 10 s test values
on the meter console. Attach the logic analyzer to TX/RX/DE to inspect the
half-duplex turn-around. (Wi-Fi dashboard is not emulated in Wokwi.)

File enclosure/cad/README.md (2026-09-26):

# Enclosure CAD — 3D-printable bench-station shell

Parametric FreeCAD models for the BMS connection tester enclosure.
Regenerate everything with:

```
freecadcmd build_enclosure.py   # base + lid2
freecadcmd build_parts.py       # tray
```

## Print set (3 parts)

| Part | File | Size (mm) | Notes |
|---|---|---|---|
| base | `base.stl` | 240 × 190 × 96 | Front panel: E-stop Ø22.5, START Ø19.2, SPOOF Ø16.2, WiFi kill Ø12.5, recessed reset, 2× LED Ø5, USB-C slot, QR recess. Rear: 4× M20 gland holes. Needs ≥250 mm bed |
| lid2 | `lid2.stl` | 248 × 198 × 18 | One-shot cover: integrated TFT mount (no separate bezel), vent slots, skirt, gasket groove. Print upside-down, no supports |
| tray | `tray.stl` | 226 × 176 × 28 | Internal mount: ESP32-S3 cradle, MAX485, 8-relay standoffs, buck mounts, fuse, 48 V barrier wall |

All module dimensions marked `VERIFY` in the scripts are typical values —
measure your actual hardware with calipers before printing.

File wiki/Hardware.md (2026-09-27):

# Hardware (v2.8 pin maps)

The thing under test — a real e-rickshaw meter cluster (dual-dial):

*Speed dial + battery %/V dial + tell-tales. The tester drives exactly this
over RS485 (readouts) + relay-switched lamp lines.*

Two supported hardware options. Pick one — the firmware auto-selects the
board at compile time (`s3-waveshare` env sets `-DBOARD_WAVESHARE_8DI8RO=1`).

## Option A — DIY (generic ESP32-S3)

Power and signal tree

*48 V shared bus → 12 V coils + 5 V logic → ESP → MAX485 → A/B → meter;
relays land on J1/J2/AUX. Full enclosure docs: `enclosure/README.md`.*

### MCU
ESP32-S3 DevKitC-1 (8 MB) or N16R8 (16 MB flash + 8 MB octal PSRAM),
dual-core LX7 @ 240 MHz, native USB CDC+JTAG. Arduino core 2.0.x.
Firmware envs: `esp32-s3-devkitc-1` (8 MB) vs `s3-n16r8`
(`board_build.flash_size = 16MB`, `board_build.psram_type = opi`,
`board_build.partitions = default_16MB.csv`).

### Pin map (unchanged since v2.0)
| Signal | Connection |
|---|---|
| S3 GPIO17 (TX) | → MAX485 DI |
| S3 GPIO16 (RX) | ← MAX485 RO |
| S3 GPIO4 | → MAX485 DE+RE tied (+ 10 kΩ pull-down to GND) |
| S3 GPIO10 | → 220 Ω → green LED → GND |
| S3 GPIO11 | → 220 Ω → red LED → GND |
| S3 GPIO48 | onboard WS2812 RGB (no wiring; mirrors green/red via `neopixelWrite`, brightness 32) |
| S3 GPIO5/6/7/8/9/12/13/14 | → relay module IN1–IN8 (12 V coils, own supply, common GND) |
| S3 GPIO15 | → button to GND (internal pull-up) — START/STOP + 10 s factory reset |
| S3 GPIO18 | → WiFi-kill to GND (internal pull-up) — ground = AP off |
| S3 GPIO21 | → spoof trigger to GND (internal pull-up; default, web-changeable) |
| MAX485 VCC / GND | 3.3 V (NOT 5 V) / common GND with meter |
| MAX485 A/B | → meter A/B, twisted pair; 120 Ω across A–B on long runs |

Avoided pins: strapping 0/3/45/46, USB-JTAG 19/20, flash/PSRAM 26–37,
console 43/44. UART2 @ 9600 8N1 via GPIO matrix.

### Spoof-trigger safe pins (DIY)
Only these GPIOs are accepted for the trigger pin; anything else falls back
to 21: **1, 2, 21, 38, 39, 40, 41, 42, 43, 44, 47**.

### LEDs
`apply_leds()` drives discretes as strict opposites and mirrors the same
state on the RGB (green = talking, red = silent). Boot red. RGB needs no
library and runs from the 250 ms eval, never the hot RX loop, so 9600-baud
timing is unaffected.

## Option B — Waveshare ESP32-S3-POE-ETH-8DI-8DO

All-in-one board (ESP32-S3-WROOM-1-N16R8: 16 MB flash + 8 MB OPI PSRAM):
8 digital outputs via expander, isolated RS485, 8 digital inputs, onboard
RGB — no external relay module, MAX485, or LEDs needed.

### Pin map
| Signal | Connection |
|---|---|
| Outputs DO1–DO8 | TCA9554PWR @ I2C `0x20` (SDA GPIO42 / SCL GPIO41); EXIO1–8 = output-register bits 0–7; **HIGH bit = ON** (Darlington sink). The dashboard *active-low* toggle is a no-op on this board — labels always match hardware. Outputs park OFF at boot. |
| RS485 | TX GPIO17 / RX GPIO18; direction on **GPIO21** via ESP32 UART **RS485 half-duplex mode** (official Waveshare demo pattern) |
| BOOT button | GPIO0 — START/STOP (holding it at power-on enters download mode; normal) |
| DI1 (GPIO4) | spoof trigger (default, web-changeable to any DI1–DI8) |
| DI2 (GPIO5) | WiFi kill (default) — ground = AP off |
| DI1–DI8 | GPIO4–GPIO11, opto-isolated, active = LOW (INPUT_PULLUP) |
| RGB | GPIO38 onboard WS2812 (no discrete green/red LEDs on this board) |

### Ethernet + buzzer (v2.9.0)
- GPIO12–16: **W5500 Ethernet is implemented** — SPI SCK15/MISO14/MOSI13,
  CS16, IRQ12, RST39, PHY addr 1. DHCP client, hostname `bms-tester`;
  the dashboard answers on the Ethernet IP too (`eth_ip` in `/api/state`,
  `ETH ip` in the Information card). Best-effort: any failure just skips
  Ethernet — boot, the AP (192.168.4.1), STA, captive portal and OTA policy
  are never affected.
- GPIO46: **buzzer is driven** — LEDC 1 kHz / 8-bit / duty ≤ 200 (official
  demo values). Beeps on meter-link up/down, sequencer start (200 ms) /
  stop (500 ms flicker), output-driver failure (5 s flickering alarm).
  Never driven before setup() (GPIO46 is a strapping pin).

### Reserved / unused (do not touch)
- GPIO40: RTC interrupt; GPIO41/42 shared with RTC @ 0x51.

### Spoof-trigger safe pins (Waveshare)
Only the DI screw terminals are user-drivable: **DI1–DI8 (GPIO4–11,
active LOW)**. Anything else falls back to DI1 (GPIO4).

## Power (both boards)
- **ESP + logic: USB 5 V** (use a real charger — the Wi-Fi AP radio is
  always on, ~1 W-class). Never power the ESP from the traction pack.
- **Relay coils: separate 12 V supply** (DIY: ≈ 30 mA/coil, ≈ 240 mA
  all-on). Tie coil-supply GND to ESP GND (common reference for the
  optoisolated inputs). Never power coils from USB/ESP pins.
- MAX485 VCC = 3.3 V, common GND with the meter.

> ⚠️ **Waveshare 8DO USB-OTG jumper:** when the jumper is set to
> **USB-OTG**, the Type-C port feeds the board from an external USB power
> supply. **Do not connect the board to a computer while the jumper is in
> the USB-OTG position.**

## RS485 bus wiring
- A/B twisted pair from the transceiver to the meter; 120 Ω termination
  across A–B on long runs.
- The Waveshare board's RS485 is **isolated** (SP3485); direction is driven
  on GPIO21 by the ESP32 UART's RS485 half-duplex mode — no DE/RE wiring
  needed on the bus side.

## Enclosure option
`enclosure/` documents an IP65 standalone box + GX16 meter-link sockets
for the DIY build (48 V shared bus → bucks → ESP/relays). The Waveshare
board is already DIN-rail friendly as-is.

Full module background: `docs/MODULES.md`. Build guides: [[Building]].
Relay/web details: [[Relays]], [[Dashboard]].

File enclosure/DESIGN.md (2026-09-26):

# BMS Connection Tester — Bench Station Enclosure Design

**Target:** `bm-a/bms-connection-tester` v2.7 (ESP32-S3 + MAX485 + SmartElex 8-ch relay + dual 48 V bucks)
**Concept:** turn the tester from a bench prototype into a proper **assembly-line QC station**:
one box, one GX16 plug, one START button, big PASS/FAIL on top. No laptop, no battery pack.
**Box baseline:** off-shelf IP65 polycarbonate ~240 × 190 × 90 mm (per `enclosure/README.md`; `DAD:` confirm).

> Convention: every electrical value the electronics owner must confirm is marked `DAD:` —
> software never guesses amps (repo convention, kept).

---

## 1. Use potential — what this box becomes

1. **Assembly-line QC station (primary).** Worker plugs the meter's GX16, presses START,
   watches the top display: link → 8 relay tell-tales sweep → PASS/FAIL + today's count.
   No laptop, no traction battery, ~30 s per meter.
2. **Field-service diagnostic.** Portable 48 V-powered box; technician fires SPOOF to force
   known voltage/current/SOC frames and verifies the meter reads correctly on-site.
3. **Burn-in / soak rig.** Loop + chase-wave modes cycle all 8 relays unattended; display
   shows cycle count and elapsed time.
4. **Training rig.** New line workers learn meter behavior against the two spoof stages
   (100 % → 88.8 V / 88.8 A / 88.8 % / 188 °C-clamped) without touching real packs.
5. **R&D regression.** New meter firmware is validated against frozen golden frames
   (0x03/0x04/0x05, checksums verified) before it ships.

---

## 2. Display on top

### Selection — 2.8" TFT (ILI9341, 320×240, SPI)

| Option | Pins | Verdict |
|---|---|---|
| **2.8" ILI9341 TFT, SPI (recommended)** | 5 GPIO | Big PASS/FAIL, 8-relay matrix, progress bar, readable at 1 m on a bench |
| 1.3" SH1106 OLED, I2C | 2 GPIO | Fallback: cheaper, text-only, fine if box must stay small |

A bench QC tool lives or dies on glanceability. The TFT wins.

### What it shows (screens)

- **BOOT:** logo, FW version, self-test (relay coils click once, bus silent → RED).
- **IDLE:** LINK status big (GREEN/RED), meter count today (pass/fail), AP IP + QR, relay names.
- **RUNNING:** progress bar R1→R8, current step highlighted, elapsed time, big STOP hint.
- **SPOOF:** stage 1/2 indicator with live V/A/SOC values being spoofed.
- **RESULT:** PASS / FAIL full-screen (green/red), latched until next START.
- **OTA/SETTINGS:** check result, version strings (rarely needed; web UI stays primary).

### Mounting

- Recessed window in the **lid**: 3D-printed bezel + foam gasket, display module on
  M2.5 standoffs behind a ~46 × 78 mm cutout (verify against actual module).
- Tilt: flat is fine for bench use; a 10–15° wedge riser under the box helps standing operators.
- Keep the SPI ribbon **short (<15 cm)** and routed away from relay coils (EMI).

### Pins (all currently free, non-strapping, no PSRAM conflict)

| Signal | GPIO |
|---|---|
| SCK | 38 |
| MOSI | 39 |
| CS | 40 |
| DC | 41 |
| RST | 42 |

Spare: GPIO1, 2, 47. (Used today: 4,5–9,10,11,12–14,15,16,17,18,21,48; avoided: 0,3,45,46,19,20,26–37,43,44.)

### Firmware work needed

New `src/display_ui.cpp`: SPI init, screen state machine driven off the existing
`RelaySequencer` state + link tracker. **Must be non-blocking** — update on state change
plus a 250 ms tick (same cadence as the LED eval); never `delay()` in the RS485 hot path.
Estimate: small, self-contained module + tests in the host harness style.

---

## 3. Buttons — full schedule

Firmware functions today: GPIO15 = START/STOP button (web-selectable: abort / run-lock / restart;
**10 s hold = factory reset**), GPIO21 = SPOOF trigger, GPIO18 = WiFi kill (maintained).

| # | Label | Function (GPIO) | Kind | Size | Placement | Notes |
|---|---|---|---|---|---|---|
| 1 | **START** | Seq start/stop (GPIO15) | Metal **illuminated** momentary, green ring, IP65 | 19 mm | Front panel, center — dominant | Ring lit while running. 10 s hold = factory reset → engrave "HOLD 10s = RESET" under it |
| 2 | **SPOOF** | Fire 2-stage spoof (GPIO21) | Metal momentary, yellow cap, IP65 | 16 mm | Front panel, left of START, ≥25 mm edge gap | Deliberate action; no guard needed, separation prevents mis-press with gloves |
| 3 | **WiFi KILL** | AP+portal off (GPIO18) | **Maintained** metal toggle + flip guard cover | 12 mm | Front panel, far right, isolated zone | Guard prevents accidental kill mid-test. Amber "AP OFF" jewel lamp beside it |
| 4 | **E-STOP** *(new, hardware-only)* | Cuts 48 V inlet (NC contact in series after fuse) | Red mushroom, latching, twist-release, 22 mm | 22 mm | Front panel top-right corner, unmissable | No firmware needed. `DAD:` contact current rating vs 48 V bus load |
| 5 | **RESET** | ESP32 EN (recessed tactile) | Recessed push, behind 3 mm hole | — | Side wall or front-panel corner | Paperclip access; recessed = no accidental press |
| 6 | *ENCODER (optional v2)* | Display menu nav | EC11 rotary + push | — | Below display on lid | Needs firmware menu system — defer |

**Why these kinds:** metal panel-mount buttons (not PCB tactiles) survive a line environment;
illuminated START gives state at a glance; maintained + guarded for the kill function is
standard industrial practice; E-STOP is non-negotiable once a shared 48 V bus is in a worker's hands.

**Placement rationale:** frequency ordering left→right (SPOOF → START → KILL);
destructive/rare actions (KILL, E-STOP) physically separated from the high-frequency START;
all within one hand's reach at bench height; engraved traffolyte labels, not stickers.

---

## 4. Panel layout

### Front panel (operator face, 240 mm wide)

```
┌──────────────────────────────────────────────────────────┐
│ [E-STOP]                              [KILL+guard] (AP OFF)│
│                                                          │
│ (SPOOF)    [      START      ]      (G)(R) [RGB]          │
│  yellow     green illuminated      link LEDs  window      │
│                                                          │
│ [USB-C service]            [QR → 192.168.4.1]             │
└──────────────────────────────────────────────────────────┘
```

### Lid (top)

```
┌──────────────────────────────────────────────────────────┐
│  ┌────────────────────┐                                   │
│  │                    │      [ QR plate ]                   │
│  │   2.8" TFT window  │      "BMS TESTER v2.7"              │
│  │   (bezel+gasket)   │                                   │
│  └────────────────────┘                                   │
└──────────────────────────────────────────────────────────┘
```

### Rear

- PG9 gland: 48 V inlet (fused, fuse holder accessible without opening lid)
- PG7 gland: RS485 A/B twisted pair to meter
- PG13.5 gland: relay tails / GX16 J1+J2+AUX
- Vent slots on side walls (never top — drip protection)

---

## 5. Enclosure construction & internal zones

```
┌────────────────── 240 ──────────────────┐
│ LEFT: logic tray        MID: relay       │ RIGHT: power
│ S3 devkit on M3         8-ch module on   │ corner: 2 bucks,
│ standoffs + MAX485 +    standoffs        │ fuse, TVS, reverse-
│ 10k pulldown + LED Rs                    │ polarity diode
│ ── low-voltage zone ── │ ── switched ── │ ── 48 V zone ──
└──────────────────────────────────────────┘
```

- **Stack-up:** base tray (3D-printed or polycarb sub-plate) holds all three zones;
  48 V zone gets a physical barrier wall (3 mm) from logic — separation by construction.
- **Lid:** display bezel + desiccant sachet + laminated wiring label inside.
- **Standoffs:** M3 brass heat-set inserts; S3 devkit ~52 × 28 mm, relay module ~138 × 56 mm
  (verify SmartElex dims), bucks ~43 × 21 mm class (verify).
- **Thermal:** bucks warm-not-hot (`DAD:` thermal call); side vents sized after soak test.

---

## 6. Internal wiring plan + safety maths

- **Power tree:** 48 V IN (fused) → buck 48→12 V (relay JD-VCC, coils ~8×75 mA + margin) →
  buck 48→5 V (logic: ESP + MAX485). Star GND at power corner: 48 V GND = ESP GND = relay GND = meter GND.
- **Gauges (defaults, `DAD:` confirm):** 48 V feed 18 AWG · relay loads 18 AWG · logic 22 AWG ·
  RS485 A/B twisted pair 22 AWG.
- **Fusing:** inlet fuse on 48 V (`DAD:` rating); per-channel ≤3 A if meter lines are driven
  rather than dry-contact (`DAD:` confirm dry-contact vs driven).
- **Clearance:** ≥3 mm between 48 V terminals and logic (IPC-2221 is lenient at 48 V, but the
  barrier wall makes it moot); keep mains nowhere near this box — 48 V DC only.
- **Strain relief:** every external cable lands on a gland + internal cable-tie anchor;
  relay tails get a service loop so the lid opens without tension.
- **Display SPI:** route away from relay coils; if flicker appears, twist SCK/MOSI with GND.
- **E-STOP wiring:** NC contact in series with 48 V *after* the fuse, before the bucks —
  kill is absolute, fusing stays intact.
- **Bench power-on order:** bucks first (no ESP) → verify 12.0/5.0 V (`DAD:` tolerances) →
  flash → RED boot → GX16 J1 in → GREEN ≤1 s → web START → R1..R8 sweep → kill tests →
  1 h soak.

---

## 7. Indicative BOM

| Part | Spec | Qty |
|---|---|---|
| IP65 polycarbonate box | ~240×190×90 | 1 |
| 2.8" ILI9341 TFT, SPI | 320×240 | 1 |
| Metal illuminated pushbutton, green | 19 mm, momentary, IP65 | 1 |
| Metal pushbutton, yellow | 16 mm, momentary, IP65 | 1 |
| Metal toggle + guard cover | 12 mm, maintained | 1 |
| E-stop mushroom, NC | 22 mm, latching twist-release | 1 |
| Amber jewel indicator | 12 V, panel mount | 1 |
| Green/red panel LEDs (bezels) | 12 mm | 2 |
| Cable glands | PG9 ×1, PG7 ×1, PG13.5 ×1 | 3 |
| Fuse holder + fuse | panel accessible, `DAD:` rating | 1 |
| TVS diode + reverse-polarity diode | 48 V bus, `DAD:` part nos | 1+1 |
| Buck 48→12 V / 48→5 V | `DAD:` part nos + ratings | 1+1 |
| GX16-5 chassis sockets | meter link J1/J2/AUX | 3 |
| USB-C pigtail + dust cap | service port | 1 |
| Wire 18/22 AWG, twisted pair | silicone insulation | as needed |
| M3 standoffs, heat-set inserts | — | set |
| Engraved labels / traffolyte tags | START/SPOOF/KILL/E-STOP/QR | set |

---

## 8. What stays as-is

- Firmware v2.7 logic untouched except the new display module; all GPIOs/pins unchanged.
- Web dashboard remains the admin surface (config, OTA, console) — display is *status only*.
- GX16 pin table: dad overwrites with the meter's real 10-pin table; sim re-maps in 5 min.

## 9. Next step

Parametric CAD (OpenSCAD): base tray with zones, lid with display cutout + bezel,
front-panel drilling template with exact hole positions, then STLs + rendered previews.
Needs from you: confirm display choice (2.8" TFT?) and measure your actual relay/buck modules.

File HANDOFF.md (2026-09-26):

# HANDOFF — bms-connection-tester project (full brain dump)

> Written 2026-09-18, before Termux storage compression.
> Last updated 2026-09-23 for **v2.7** (three dashboard variants FULL/CLASSIC/
> LITE via `WEB_UI_VARIANT`, live SVG bench + `mv/ma/msoc` readout, persistent
> relay names everywhere, offline 3D bench `local-wokwi/` + new public repo
> `bms-tester-sim`, enclosure/GX16 docs, release snapshots + demo GIF;
> 103/103 + 49/49 + contract 3/3 + soak green; v2.7 tag + release live WITH A
> GAP: no firmware bins — no ESP toolchain in this container, OTA v2.6→v2.7
> checks fine but installs 404 until bins are built+uploaded on the bench PC).
> COMPACTION CHECKPOINT 2026-09-23 (pre-compaction, all pushed): main
> `6033dd9` == origin/main; tag `v2.7` == `ca3ffe0` (firmware-identical to
> main — only docs/sim/media after it); wiki backend + `bms-tester-sim` main
> BINS SHIPPED 2026-09-23 evening: v2.7 release now carries 4 firmware
> assets (`bms-tester-8mb.bin`, `bms-tester-n16r8.bin`, `firmware.bin`,
> `n16r8-firmware.bin` — built ON THIS PHONE in proot-debian, 8m05s, magic +
> version verified) and ZERO media (8 png/gif moved to `docs/img/`, all 49
> links rewritten to raw.githubusercontent, main + wiki pushed). Sim live-GH
> OTA gate PASSES (`firmware.bin` + `n16r8-firmware.bin` present). Debian
> REINSTALLED with pio 6.2.0 (see quirk 0) — the bench PC is NO LONGER
> blocking; only remaining OTA proof is a real box Check→Install pull.
> `releases/` now also holds the 4 v2.7 bins as offline backup.
> §12's release checklist REQUIRES updating this file in the same commit as
> any feature — a body left stale behind an addendum is a bug (2026-09-22).
> Audience: the next AI agent (or future me) picking this project up cold.
> Goal: everything needed to resume without re-discovering anything.
> **Read order for a new agent:** §1 → §2 → §5 → §8 → §11.

---

## 1. What this project is (30 seconds)

An ESP32-S3 box that impersonates a **JBD / Xiaoxiang Smart BMS** over RS485 so
compatible meters/displays can be exercised **without the real battery pack**.
Two LEDs: green = valid BMS traffic seen, red = bus silent.
**v2.3 is the relay test bench grown up**: relay count (first N) + chase-wave
mode, per-mode millisecond holds, loop/pause/cycle-limit burn-in, ALL-ON
stagger, direction, relay labels, QC counters, boot auto-start; 2-stage spoof
(100 first, then 88.8/88.8/88.8/188); manual + automatic
OTA; coalesced config saves. No screens needed.
**v2.3.1 (bench patch)**: login wall REMOVED (per-request admin password for
reboot/reset/upload/OTA-admin/AP saves); 1 s tick is status-only (forms fill
on load + after saves); UTF-8 pages; chase auto-hold sweeps (retires `hch`);
configurable spoof trigger GPIO (safe-list clamped); WiFi kill switch on
GPIO18; fixed GitHub tag parse + dashboard Install button.

- **Origin story:** user's dad runs an e-rickshaw meter assembly line; workers
  needed the real battery or a laptop to verify RS485 wiring. This box replaces
  both. (Repos are now deliberately **generic** — e-rickshaw is one use case.
  The Word report for dad keeps the e-rickshaw framing on purpose.)
- **People:** user = Bhavishya Madan (GitHub `bm-a`). Dad = electronics-strong,
  code-weak; gets status via a WhatsApp Word report, not GitHub.
- **Current release: v2.7** (three dashboard variants: FULL default with live
  inline SVG bench card + `mv/ma/msoc` meter readout, CLASSIC = v2.6 page
  byte-verbatim, LITE = relays+names+link; relay names NVS-persistent in all;
  OTA assets stay FULL; everything else = v2.6 behavior).
  v1.x responder core FROZEN (parser, option-A, tracker, golden frames, LEDs,
  STATUS?, original 32 tests byte-identical). v1.0 frozen (ZIP + git tag,
  untouched since).

---

## 2. The GitHub repos (all public, user `bm-a`)

| Repo | URL | Contents | State |
|---|---|---|---|
| `bms-connection-tester` | https://github.com/bm-a/bms-connection-tester | Firmware, 152 tests, docs, binaries, Wokwi, CI, wiki | main pushed; tags `v1.0`–`v2.7`; Releases: every release ≤ v2.6 carries Tasmota-style one-file images next to the separate files — v1.0 (ZIP+1), v1.1 (4+1), v1.2–v2.6 (7+2 = 9 each, v2.6 incl. docx); **v2.7 carries dash-full.png + dash-lite.png + demo.gif ONLY (no bins — see §11.2)**; wiki live (8 pages) |
| `bms-tester-sim` | https://github.com/bm-a/bms-tester-sim | Offline 3D bench simulator: ESP32-S3 + MAX485 + photo meter + 8 relays + GX16, electron-flow viz, pressable buttons, relay board + persistent names, verbatim ESP page embed, `shots.py` snapshots | In sync. NOTE 2026-09-23: maintained DIRECTLY now (subtree retired) — another session added LICENSE + CI + verify hardening on top of subtree history; local Ayca-removal sync done via scratch clone (`tmp/opencode/simrepo`, wipe-safe). Merge conflicts: local touches bench3d.html/shots.py, remote touches sim_server.py/verify_sim.py — check both sides before any future subtree op (prefer direct clone + copy). |
| `jbd-bms-rs485-handbook` | https://github.com/bm-a/jbd-bms-rs485-handbook | Electronics explainer: RS485, MAX485, S3 pins, JBD protocol, build guide, FAQ + `llms.txt` | Pushed (single commit + later edits if any — check `git log`) |
| `esp32s3-qemu-arm64` | https://github.com/bm-a/esp32s3-qemu-arm64 | Build/run scripts for Espressif QEMU on ARM64, M25P80 flash patches, Termux/proot notes | Pushed (2 commits) |

Cross-links: main README ↔ handbook; emulator README references both.
Topics set for search (main: 15 topics incl. `jbd-bms`, `rs485`, `bms-emulator`,
`xiaoxiang`, `hardware-in-the-loop`; handbook: 7; emulator: 4).
`llms.txt` (AI-agent summary standard) exists in main + handbook repos.

**Local clones** (Termux home, source of truth — push before compressing!):
- `/data/data/com.termux/files/home/bms-connection-tester` (this file lives here)
- `/data/data/com.termux/files/home/jbd-bms-rs485-handbook`
- `/data/data/com.termux/files/home/esp32s3-qemu-arm64`

---

## 3. Version history

- **v1.0** (`ff4044d`, tag `v1.0`): 0x03-only responder, fixed 2 s green window,
  11/11 tests, S3 firmware built. Frozen in
  `releases/bms-connection-tester-v1.0.zip` (22 files, git-ignored) + tag.
- **v1.1** (tags moved forward with each finalization; final commits
  `1d2a710` → `1593231` → `183aa32` → `10be208` → `8fd3d99`, tag `v1.1`):
  multi-register (03/04/05) + adaptive window + silence-on-unknown (option A) +
  hardened streaming parser; **32/32 tests**; S3 firmware rebuilt;
  Arduino sketch; flash binaries; docs; CI; generic repo identity.
- **v1.2** (`67e9ebe`, tag `v1.2`): onboard WS2812 RGB mirror (GPIO48,
  `neopixelWrite`, no extra lib) + N16R8 build (`s3-n16r8`: 16 MB flash, OPI
  PSRAM) + Wokwi NeoPixel; `firmware/` + `firmware-n16r8/` triples; 32/32 +
  soak green; virtual-bus PASS; QEMU known gap re-confirmed.
- **v2.0** (`71b0bc6`, tag `v2.0`): relay test bench — 8-relay sequencer
  (`src/relay_ctrl.*`: sequential/all-ON, 3 button behaviors, debounce, hold
  timer, boot-safe OFF-first, polarity toggle), always-on AP dashboard
  (`src/web_ui.*`: dark UI, login, NVS `bms2`, admin reset, `BMS-Tester`),
  spoof window (88.8/88.8/88.8/188 on `0x03`, configurable, auto-revert);
  18 new tests (**50/50** at the time); Wokwi relay LEDs + buttons; CI builds both envs.
  Responder core frozen and re-proven on the same source.
- **v2.1** (tag `v2.1`): website reliability, zero behavior change —
  14 host-executed web tests (real `web_ui.cpp` on Arduino stubs:
  `test/test_web/Arduino.h|WiFi.h|WebServer.h|Preferences.h`),
  `tools/check_web_contract.py` gate, `select_reply()` extracted host-covered,
  `test_system` 24 h office-day sim (86,400 polls, per-reply CK validation),
  Wokwi diagram fixed per official docs + 8 relay-module parts + `sim.yaml`
  automation with token-gated CI job. Bench-confirmed relay idle HIGH /
  ON-when-LOW = active-LOW default stands. **66/66 total** (52 pio + 14 web).
- **v2.2** (tag `v2.2`): user reported the page never opened on their phone.
  Root causes ranked: (1) no captive portal — phones show "no internet" and
  route via mobile data / never pop a page; (2) unknown URLs 404'd; (3) AP IP
  only implicit. Fix: `DNSServer` catch-all to `WiFi.softAPIP()` (login pops
  on join), `onNotFound` → 302 `/`, explicit
  `softAPConfig(192.168.4.1/24)`; report + wiki warn to turn mobile data off.
  Portal flow host-tested (15 web tests). **67/67 total**. Other bench
  possibility (old v1.x firmware flashed = no WiFi at all) left as a
  diagnostic question to the user: is `BMS-Tester` visible? what does
  `STATUS?` report?
- **v2.3** (tag `v2.3`): relay count 1–8 (beyond-N forced OFF + greyed) +
  chase-wave mode (3rd `rmode`, single lit sweep, wraps, all button modes) +
  2-stage spoof (stage 1 "100" 5 s → stage 2 88.8/188 10 s, both editable) +
  per-mode ms holds (`hseq`/`hch`/`hall`, 0 = forever each) + industrial pack
  (loop + pause + cycle limit, ALL-ON stagger, fwd/rev, 8 labels, cycle/act
  counters, boot auto-start) + persistent logins (remember-me, 30-day NVS
  slots ×4) + OTA (offline `/update` upload + auto GitHub checks/installs over
  optional STA uplink) + coalesced config saves (dirty-flag, 1.5 s flush) +
  live dashboard version. NVS `bms2` v3 (tested v2→v3 migration). Bench answers
  baked in: 188-shows-100 = meter-side clamp (proven), relays-stuck-on = hold
  0 = forever (per-mode holds now explicit). **105/105 total** (70 pio +
  29 web + contract).
- **v2.3.1** (bench patch, this release): login wall REMOVED (per-request
  admin password gates reboot/reset/`/update`/OTA-admin/AP saves; passwords
  scrubbed from `/api/state`); 1 s tick is status-only (forms fill on load +
  after saves; dirty-tracking + fetch-failure tolerance); UTF-8 on all pages;
  chase auto-hold `swp` (retires `hch`); spoof trigger GPIO configurable
  (allowlist-clamped, NVS `spin`, live re-arm); WiFi kill switch on GPIO18;
  fixed GitHub tag parse (space-tolerant) + dashboard Install button.
  **103/103 total** (77 pio + 26 web + contract).
- **v2.4** (this release): Tasmota-grade `/update` (`fw_upload.h` gates:
  exact asset basename, explicit budget, image-head check, single finalize,
  named errors) + OTA-pull same gates + custom URL; per-mode relay menu
  (chase 20 ms BBM, 500 ms stop dead-band, step ≥ 100 dflt 250 / stagger
  dflt 50 / pause 500–60000 dflt 2000, R9/R10 rejects, live count-shrink,
  RESTART keeps forces); spoof Save-only; console; backup/restore (no
  passwords); STA one-shot test; info card (variant/flash/sketch/heap/
  uptime/bootcount/reset-reason/RSSI/pin map); mDNS `bmstester.local`;
  keep-WiFi + bootcount resets; editable OTA cadence.
  **134/134 total** (93 pio + 41 web, incl. 5 upload-gate tests).
- **v2.5** (this release): trigger group (enable+GPIO+polarity+Save, `sinv`
  wired end to end); captive-portal landing (probes/CNA-UA get button +
  Safari steps, rest 302s to `/`); structured config (`docs/CONFIG-SCHEMA.md`,
  v2 sectioned + v1 flat backups); on-demand STA join for check/install/URL;
  whitespace-tolerant JSON core; socket harness (`tools/fw_emu`, 54 checks)
  + 48 h run (10 checks) + 30-day soak (2.59 M polls, 309 k cycles, 30 NVS
  commits) + `docs/EMULATION-v2.5.md`. Harness-caught fixes: multipart-arg
  403s, whitespace rejects, test-then-install gap, missing `seq.begin()` in
  emu, console ok-masking. **137/137 total** (93 pio + 44 web).
- **v2.6** (this release): software-only daily meter estimate — `MeterBatch`
  (meters/attempts/pass/fail in RAM, flat NVS `m_met/m_att/m_ps/m_fl`
  flushed on close/reset only), fed from the live link state in `web_tick()`:
  RED gap ≥ 3 s (`LINK_GAP_NEW_METER_MS`) closed by GREEN = reseat = new
  meter; steady GREEN across RESTARTs = same meter; sub-3 s flickers stay;
  mid-cycle gaps defer to IDLE; manual New-day reset (no RTC; boot persists
  via `begin()` amnesia + NVS overlay; seated unit re-opens as #1; backups
  exclude counters); console `DAYRESET`. Round link dots (`#dotG/#dotR`) in
  the dashboard header. One-file merged flash images per board
  (`bms-tester-8mb.bin` / `bms-tester-n16r8.bin`, `merge_bin`,
  structure-verified). `test_meter` (10) added to pio native filter (103);
  `/__bus` emu control for the RS485 state (the STA `__link` never touched
  bus LEDs). Harness-caught: dayReset seat-count, begin-vs-dayReset link
  amnesia, STA/bus link conflation. **152/152 total** (103 pio + 49 web);
  emu 62/62 + 10/10 soak; v2.6 docx.
- **v2.7** (this release): three dashboard variants, one per build
  (`WEB_UI_VARIANT` in `platformio.ini`, only the selected page compiles in):
  FULL (default envs) = v2.6 page + live inline SVG bench card (48V→bucks→
  ESP→MAX485 DE dot→animated A/B flow→meter readout, 8 glowing relay blocks,
  zero CDN) + tile glow transitions; CLASSIC (`s3-classic`) = v2.6 page
  byte-verbatim (19,799 B, diff-proven); LITE (`s3-lite`) = relay tiles +
  names + LINK pill (~4.9 KB page). Relay names NVS-persistent in all three
  (existing `lbl0..7` path, untouched). Live meter readout keys in
  `/api/state` (read-only, never saved/restored): `mv/ma/msoc` mirroring the
  last `0x03` reply (golden 520/0/100 or active spoof stage). Contract checker
  validates all 3 variants (endpoints ⊆ routes, per-page ids incl. dynamic
  `bench_rN`, union of state keys); `test_web` asserts `mv:520/ma:0/msoc:100`;
  all 3 variants proven compiling on host; FULL+LITE JS `node --check` clean.
  OTA assets unchanged (FULL builds) — but v2.7 bins NOT built here (no ESP
  toolchain in container): release carries images/GIF only, OTA v2.6→v2.7
  checks fine and installs 404-safe until §11.2 is done. Sim (`local-wokwi/`,
  subtree-pushed as `bms-tester-sim`): relay board row + `labels.json`
  persistence synced into `lbl0..7`, live-GitHub OTA check
  (`ota_cmp` port + asset-presence gate, reproduces the 404 path), `shots.py`
  snapshots + demo GIF (cairosvg+ffmpeg). Enclosure/GX16 docs (`enclosure/`,
  dual-buck tree, `DAD:` placeholders for dad's sizing). Real meter photos were
  removed from the repo (2026-09-27).
  **152/152 total** (103 pio + 49 web); emu 62/62 earlier; release snapshots
  inspected before upload. Post-release (same day, all in main): media pass —
  8 assets + Ayca-free redaction (meter photo logos filled, all mentions
  dropped, wiring.png regenerated), snapshots/GIF embedded on all 27 docs/wiki
  pages + llms.txt index; sim OTA check now hits live GitHub (asset gate
  reproduces the v2.6→v2.7 404 path exactly). Release media (v2.7 tag): dash-full.png,
  dash-lite.png, demo.gif, protocol.png, wiring.png, terminal.png, tests.png,
  tiles.png — every docs/wiki page embeds the relevant ones.
- **Decision: option A** — writes (`0x5A`) and unknown registers get SILENCE
  (never a wrong-register reply), but still refresh the green window.
  This was an explicit user-confirmed choice. Do not change without asking.

---

## 4. Hardware design (v2.0 map — v1.x wiring unchanged, only ADDS pins; v2.3 adds NO pins)

Board: **ESP32-S3 DevKitC-1 (8 MB) or N16R8 (16 MB + OPI PSRAM)** (NOT classic
ESP32 — S3 has no GPIO25; S3 GPIO range is 0–21 + 26–48).

| Signal | Connection |
|---|---|
| S3 GPIO17 (TX) | → MAX485 DI |
| S3 GPIO16 (RX) | ← MAX485 RO |
| S3 GPIO4 | → MAX485 DE+RE tied (+ 10 kΩ pull-down to GND) |
| S3 GPIO10 | → 220 Ω → green LED → GND |
| S3 GPIO11 | → 220 Ω → red LED → GND |
| S3 GPIO48 | onboard WS2812 RGB (mirrors LEDs, v1.2+) |
| S3 GPIO5/6/7/8/9/12/13/14 (v2.0) | → relay IN1–IN8 (SmartElex 12 V, own 12 V supply, common GND, active-LOW default) |
| S3 GPIO15 (v2.0) | → button to GND (pull-up; 10 s hold = factory reset) |
| S3 GPIO21 (v2.0) | → spoof trigger to GND (pull-up; v2.3.1: configurable, see below) |
| S3 GPIO18 (v2.3.1) | → WiFi kill to GND (pull-up; grounded = AP+portal+server off) |
| *(v2.6 adds NO pins — meter counting is pure software)* | |
| MAX485 VCC / GND | 3.3 V (NOT 5 V) / common GND with meter |
| MAX485 A/B | → meter A/B, twisted pair, short run |

Avoided pins: strapping 0/3/45/46, USB-JTAG 19/20, flash/PSRAM 26–37,
console 43/44. UART2 @ 9600 8N1 via GPIO matrix.
Power: USB 5 V for ESP + MAX485 — NEVER the traction pack. v1.x idle ≈ 0.3–0.5 W
(radio off). v2.0 keeps the Wi-Fi AP always on (~1 W-class — use a real charger)
and relay coils run on their own 12 V supply (common GND).

---

## 5. Firmware architecture

```
src/bms_protocol.h / .cpp   hardware-independent core, FROZEN (also on host)
src/relay_ctrl.h / .cpp     HW-independent bench add-on (also on host)
src/ota.h / .cpp            HW-independent OTA decisions (also on host)
src/web_ui.h / .cpp         ESP-only (WiFi/WebServer/Preferences)
src/main.cpp                Arduino sketch (ESP32-S3 only)
```

Core pieces (`bms_protocol.*`):
- `jbd_checksum(buf, len)` — generic `0x10000 − sum`, caller chooses slice.
- `JbdParser` — streaming state machine (states renamed `JST_*` because
  Arduino's `binary.h` `#define`s `B1` — this broke the S3 build once).
  Validates start/cmd/len/data/checksum/terminator; re-syncs on noise;
  rejects overlong (`JBD_MAX_DATA` = 64). Emission gated on checksum success
  (a real bug caught by tests: corrupt-CK + trailing 0x77 used to emit).
- `reply_for(reg, is_write, len)` — 0x03/04/05 read → canned frame; else NULL.
- `PollTracker` — EMA of poll intervals; threshold = clamp(2×EMA+500, 2 s, 10 s).
- `matches_request()` + `connection_active()` — v1.0 compat, kept for tests.
- `FW_VERSION` = `"2.7"`; `STATUS?` replies `GREEN 2.7` / `RED 2.7`
  (first token stable — HIL test splits on whitespace).

Canned frames (frozen literals, NEVER recomputed at runtime):
| Reg | Len | Content | CK |
|---|---|---|---|
| 0x03 | 34 | byte-exact real capture: 52.0 V, 0 A, 100 Ah/100 Ah, RSOC 100 %, 14S, 2×25.0 °C | FC DA |
| 0x04 | 35 | 14 × 0x0E82 (3714 mV) = 52.0 V, consistent with 0x03 | F8 04 |
| 0x05 | 19 | ASCII `TEST-14S100A` | FC FD |

`main.cpp` loop (v2.0 order): button debounce (press event + 10 s reset hold) →
spoof-pin edge → `seq.tick()` + `apply_relays()` (change-only writes) +
`web_tick()` (non-blocking) → FROZEN RS485 drain→parser→`note_poll`+reply
(DE HIGH → write → `flush(true)` → 1.5 ms guard → DE LOW → drain → reset),
with one additive select: reg `0x03` + spoof window active → `spoofFrame`,
else frozen `reply_for` → 250 ms LED eval → `STATUS?`. Boots red, relays OFF
(OFF level driven BEFORE `pinMode` — no boot click). No `delay()` in hot path.
(No `delay(1)` power tweak — obsolete: radio is on in v2.0.)

v2.0 pieces (`relay_ctrl.*`, host-tested):
- `RelaySequencer` — `millis()` state machine (IDLE/RUNNING/HOLD/CHASE/PAUSE),
  sequential stepping with catch-up, per-mode ms holds (0 = forever), relay
  count scoping, manual force mask, rollover-safe compares.
  `handle_button_press()` maps the 3 web modes
  (HOLD_ABORT / RUN_LOCK / RESTART). v2.3: chase sweep, loop + pause +
  cycle limit, ALL-ON stagger, fwd/rev direction, QC counters
  (`cyclesDone()`/`actuations()`). v2.4: chase 20 ms break-before-make,
  500 ms post-stop start dead-band, run-register snapshots (timing latched,
  count-shrink live), force-in-chase idles the wave, RESTART keeps forces,
  step ≥ 100 dflt 250 / stagger dflt 50 / pause 500–60000 dflt 2000. v2.6:
  `MeterBatch` link-gap heuristic (`noteLink`/`pollIdle`/`closeMeter`,
  `begin()` amnesia vs `dayReset()` seat-count), accepted starts open
  attempts (`startImpl` flag keeps loop-restarts out), `cycleDone` latches
  pass. Never touches relays — pure counters.
- `DebouncedInput` (30 ms, edge-once), `SpoofWindow` (legacy single-stage,
  frozen + tested), `SpoofPlan` (v2.3 two-stage: `stage()` → 0/1/2).
- `build_spoof_frame(cfg, stage, out)` — golden copy + patched V/A/SOC/temps
  + recomputed CK (same LEN+DATA rule); `relay_pin_level()` polarity helper.
- `Bms2Config` — all web-tunable values + NVS schema (namespace `bms2`, v3;
  tested v2→v3 migration: seconds×1000 fanned to all holds, singles→stage 2).
- `web_ui` (ESP-only): AP `BMS-Tester` always on (fixed 192.168.4.1 via
  `softAPConfig`, channel changeable), `DNSServer` catch-all captive portal,
  unknown URLs → 302 `/`, **no login wall (v2.3.1; WPA2 is the gate)**,
  per-request admin password gates reboot/reset/`/update`/OTA-admin/AP
  saves (passwords never in `/api/state`), JSON API + single-page dark
  dashboard — 1 s tick is status-only, forms fill on load + after saves
  (`node --check` clean + `check_web_contract.py` gate), deferred-save
  coalescing (dirty-flag, 1.5 s flush, sync-flush on reboot/reset), NVS
  load/save, optional STA uplink + one-shot test (30 s, no reboot)
  (hotspot, 30 s non-blocking try, AP-only fallback), Tasmota-grade manual
  `/update` firmware upload (exact asset, explicit budget, image-head gate,
  single finalize, named errors, progress), OTA check + Install + custom URL,
  console, config backup/restore (no passwords), info card, mDNS
  `bmstester.local`, factory reset + keep-WiFi reset + bootcount reset +
  reboot (one `web_reboot_now` path), boot counter + reset reason,
  portal landing for probes/CNA (button + Safari steps, rest 302s),
  on-demand STA join for check/install/URL, whitespace-tolerant JSON,
  v2.6 meter card (meters/attempts/pass/fail + New-day reset) + round link
  dots (`#dotG/#dotR`) + `/api/meter` (reset-only) + console `DAYRESET` +
  `STATUS` batch + NVS `m_met/m_att/m_ps/m_fl` (close/reset flush, boot
  restore, excluded from backups) + `meter_feed()` in `web_tick()`,
  WiFi kill switch (`web_wifi_set`, GPIO18, debounced in `main.cpp`),
  v2.7 `WEB_UI_VARIANT` (0 CLASSIC / 1 FULL default / 2 LITE — `handle_root`
  serves the compiled-in page; OTA assets stay FULL) + FULL bench SVG card
  (`bench_r0..7`, `bench_de`, `flowAB`, `bench_mv/link`) + read-only
  `mv/ma/msoc` in `handle_state` (golden vs spoof stage).
- `ota` (`ota.h`, host-tested pure logic; network in `main.cpp`): semver
  compare, per-variant asset pick (`-DFW_IS_N16R8=1` on the n16r8 env —
  quoted `-D` strings do not survive the flag pipeline), safe download URLs,
  idle-only auto-check gate; install streams via HTTPClient + `Update`
  (no 700 KB RAM copy).
- Reply selection lives in `select_reply()` (`relay_ctrl`, host-tested in
  `test_system`); `main.cpp` calls it — no inline selection logic.

---

## 6. Protocol findings (do not re-derive — verified)

- JBD UART, 9600 8N1, half-duplex. Request `DD A5 03 00 FF FD 77`.
- **Checksum rule:** `0x10000 − sum`, big-endian. Requests cover REG+LEN+DATA
  (A5/5A excluded). **Responses cover LEN_HI+LEN_LO+DATA — echoed CMD excluded.**
  Including it gives FCD7 vs recorded FCDA (off by exactly 0x03). An early spec
  note said otherwise; the captures prove it. Verified on 6 vectors:
  FFFD (req), FCDA (100 %), FCA8 (50 %), FA86 (90 %/45 °C),
  F65A (2nd Docklight 0x2A variant), F658 (handoff 49 % frame).
- **Anomalies (transcription errors, EXCLUDED from vectors, documented in code):**
  charging frame (F386 vs computed FA41, off 0xBB), discharge frame
  (FBCD vs FBBC, off 0x11).
- Ground truth: `captures/SOC-DOCKLIGHT.xlsx` (rows: 4 req, 7 SOC100, 10 SOC50,
  15 90 %/45C, 21 2nd-0x2A variant, 27 req+Modbus, 30 Modbus `01 03 00 00 00 1D`,
  33 49 %/31C, 39 charge, 44 discharge). Modbus on the bus is out of scope.
- Golden reply + request bytes verified byte-present inside `firmware.bin`.

---

## 7. Tests — 152/152 + soak + virtual bus + contract + socket emu (how to run, what they prove)

- `pio test -e native` → 10 suites: test_checksum (7), test_logic (8),
  test_parser (13), test_stress (4), **test_relay (36), test_spoof (11),
  test_meter (10), test_ota (6), test_upload (5), test_system (3)**.
  **Last run: all green (103/103).** Old 32 byte-identical since v1.1.
  `test_web` (49) is g++-only (needs `-DARDUINO` + stubs) → total **152/152**
  via `sh run_tests.sh`.
- `tools/fw_emu/`: socket harness (real handlers, real HTTP, virtual time):
  `drive_emu.py` 62 checks + `drive_soak.py` 10 checks (48 virtual hours).
  Boot `fw_emu` (built from `emu_main.cpp`), run both drivers. `w3m -dump`
  renders verify pages. `/__bus` drives the RS485 bus LEDs + meter heuristic
  (`/__link` is STA-only — conflating them cost a debugging round in v2.6).
  See `docs/EMULATION-v2.5.md` (v2.5 per-feature report; v2.6 deltas in wiki
  Versions + CHANGELOG).
- `test_web` highlights: real `web_ui.cpp` executes on host — per-request
  admin password gates (admin/OTA/update incl. multipart field plumbing),
  WiFi kill-switch transitions, spoof-pin clamp + persist, OTA install gate,
  NVS v2→v3 migration, validation/NVS/
  API/fuzz/reset, deferred-save coalescing (stub flash-commit counter) +
  reboot flush, count/chase-sweeps/loop/labels/counters/STA/OTA/`/update` handlers.
  Stub-fidelity bugs it caught (and fixed): per-TU mock clocks (→ `inline`
  shared clock), NVS `clear()` missing the number store, test isolation via
  static `ident` (→ defaults-reset in `web_setup`, behavior-neutral on
  hardware), **host `String += char` binds `String(int)` (decimal garbage
  in the upload password) → firmware appends via 1-char C string**,
  **v2.3.1: `hch`/`a_user`/login expectations retired with the remodel**.
  All were test-harness or robustness fixes, never responder logic.
- `test_ota` highlights: semver matrix (`2.10 > 2.9`, `v`-tolerant, garbage
  fail-closed), per-variant asset pick, URL tag sanitizing, gate matrix
  (auto/STA/sequence/bus-silence/interval/rollover).
- `test_system` highlights: `select_reply()` matrix (golden/stage-1/stage-2/
  disabled/null-frame/04-05/write/unknown) + 24 h office-day sim (86,400
  polls, every reply CK-validated, exact 5 s + 10 s spoof stages, relay +
  chase schedule probes, write-silence mid-spoof, green-all-day) + loop
  cycle/limit/counter proof. Runs in ~0.05 s.
- `tools/check_web_contract.py` — JS endpoints/ids/state-keys/POST-keys vs
  firmware routes, exit 0 = PASS (CI `web` job + run_tests.sh). Knows dynamic
  `lblN` keys (builder loops) + `/api/ota` + `/update` form. v2.7: validates
  all 3 PAGE_DASH variants (per-page endpoints/ids incl. dynamic `bench_rN`,
  union of state keys incl. `mv/ma/msoc`).
- `sh run_tests.sh` → same suites via g++ fallback + **soak sim** + HIL
  (auto-skip without hardware).
- New-suite highlights: sequential stepping/timing, per-mode ms holds,
  ALL-ON, chase wave + count scoping, loop/pause/limit, reverse direction,
  ALL-ON stagger, QC counters, all 3 button modes, abort/restart mid-cycle,
  manual override, polarity map, debounce edges, sequencer+window rollover;
  spoof stage-1/2 bytes (2710/64 vs 22B0/22B0/0E23/BC), CK self-consistency,
  custom values, plan timing/handoff/cancel/retrigger. Past real bug caught:
  debounce test asserted the wrong return polarity (test bug, not code —
  fixed before commit); v2.3: hold-expiry test assumed hold starts at last
  step (it starts at the completing tick — fixed).
- v2.3 pre-release catches (both fixed before release): auth-cookie
  truncation (stub `indexOf(' ')`, above) and a stray `;` ending the
  `handle_state` builder early (spoof keys missing from `/api/state`) —
  each caught by 2 web tests. Lesson: keep the web suite at full strength;
  it is the dashboard's only emulator.
- Old highlights (still green): exhaustive 1,785 single-byte corruptions
  (0 false frames); 10 M fuzz (0 emits); cadence×register sweep;
  bus saturation (5,000); 1 s-green / 2 s-red / self-heal / rollover.
- `tools/soak_sim.cpp` — 8 simulated days: **691,040 polls, all answered**,
  noise rejected, silence→red, millis() wrap crossed mid-run, green-on-resume.
- `tools/virtual_bus.sh` — one-shot PTY emulation (Debian/proot, socat+g++):
  builds `tools/dut_emu.cpp` (real `bms_protocol.cpp` over a PTY), runs
  `tools/raw_meter.py` (raw-fd I/O — pyserial modem ioctls fail on proot PTYs)
  through 03/04/05 golden + write/unknown silence + noise resync + 3 s
  silence, asserts meter PASS + DUT RED→GREEN→RED. Exit 0 = PASS.
  (Earlier sessions kept these harnesses in scratch; v2.0 promoted them in-repo.)
- Dashboard JS: `node --check` clean (Termux node). Wokwi diagram validated
  as JSON (18 parts, 33 wires); browser run is manual (never executed here).
- `tools/virtual_meter.py` — scenario modes (real serial ports).
- `tools/test_hardware.py` — HIL pytest; needs `HIL_BUS_PORT` + `HIL_CDC_PORT`.
- Past bugs the suite caught (proof it works): parser emit-on-bad-CK,
  author's own wrong vector (FEEF not FEFF), Arduino `B1` macro collision,
  missing `<cstring>` (Debian GCC 14), missing `<cstdio>` (CI Ubuntu GCC —
  Termux clang had silently accepted both).

---

## 8. Build system & environments

`platformio.ini` envs: `esp32-s3-devkitc-1` (8 MB firmware, FULL dashboard),
`s3-n16r8` (16 MB + OPI PSRAM, `default_16MB.csv`, `-DFW_IS_N16R8=1`, FULL),
`s3-classic` (`-DWEB_UI_VARIANT=0`), `s3-lite` (`-DWEB_UI_VARIANT=2`),
`native` (host tests,
`build_src_filter = +<bms_protocol.cpp> +<relay_ctrl.cpp> +<ota.cpp>`,
`test_filter` = 8 suites), `s3_tests` (on-target ELFs).
Pinned reality: espressif32@7.1.3, Xtensa GCC 8.4.0 (esp-2021r2-patch5),
Arduino 2.0.x (IDF 4.4 based). v2.3 `firmware.bin` = 955,040 bytes
(`65eb652e…ae35d36a`); `firmware-n16r8/firmware.bin` = 957,520 bytes
(`71d39bd7…df36d2`). Golden bytes + `2.3` + `BMS-Tester` + dashboard
strings verified byte-present in both. `firmware/` + `firmware-n16r8/` hold
bootloader + partitions + esptool READMEs (flash 0x0 / 0x8000 / 0x10000).
`arduino/` = same firmware as IDE sketch (9 tabs incl. new files).
`.github/workflows/ci.yml` runs native (70) + web (contract + test_web) +
**both firmware envs** + soak + token-gated `wokwi-sim` (green; sim skipped
without `WOKWI_CLI_TOKEN` secret).

**CRITICAL — two homes:** Termux home (`/data/data/com.termux/files/home`,
shared into proot containers) vs container-local roots. These live INSIDE the
Debian container (`…/containers/debian/rootfs/…`), NOT in Termux home —
back them up separately if they matter:
- `/opt/pioenv` (venv: platformio, esptool), `/opt/qemu-src` (Espressif QEMU
  git + `build/qemu-system-xtensa`, OUR patches applied, see §9),
  `/opt/qemu-s3` (flash images, boot logs), `/root/.platformio` (Debian-side
  packages incl. hand-extracted Xtensa toolchain).
- Ubuntu container holds only a QEMU binary copy (`…/ubuntu/rootfs/opt`).

**Termux/Android quirks (all solved, scripts exist):**
0. **ENV REBUILT 2026-09-23 evening (supersedes the morning "ENV LOST"
   note): both proot containers were gutted shells, so `proot-distro install
   debian` fresh → apt python3/pip/gcc/git → `pip install platformio`
   (6.2.0) → v2.7 bins built+verified on-phone (8m05s, see header). Termux-side
   PIO core 6.2.0 + packages were warm all along (morning note was wrong about
   them); Termux `pio run` still can't compile (android_aarch64 has no registry
   toolchain + bionic can't exec glibc binaries) — firmware builds happen
   INSIDE proot-debian, uploads via Termux `gh`. `/opt/qemu*` still gone:
   QEMU rebuild (sanitized PATH, ~1 h) only if emulation work resumes.
   `tools/merge_releases.py` is now PROVEN (built v2.7 --keep, then `--upload`
   equivalent via Termux gh): per-tag worktrees, merge, magic+version verify,
   OTA-named raw bins included.** Native/host tests + sim need nothing
   (Termux python/g++ intact).
1. pyserial has no Android port lister → 1-line patch
   (`plat[:5]=='linux' or plat[:7]=='android'` in `list_ports_posix.py`;
   patch file in emulator repo). Without it EVERY `pio` cmd crashes on Termux.
2. PIO Xtensa tarball fails on `rename()` under proot (hardlinks, EINVAL) →
   `tar -xzf` the cached tarball into the package dir by hand.
3. Meson sniffs Termux's bionic headers (`-I…/termux/files/usr/include` baked
   into build.ninja) → configure AND build with sanitized
   `PATH=/usr/local/sbin:/usr/local/bin:/usr/sbin:/usr/bin:/sbin:/bin`.
4. ~~QEMU JIT cannot run inside proot~~ STALE 2026-09-21: QEMU 9.2.2
   source-built DOES execute guests inside proot-debian on this phone
   (ESP-ROM output + guest_errors captured). Only the official prebuilt
   aborts (static-glib `g_quark_init`). Build AND run in proot-debian.
5. v2.3 build lessons: quoted `-D` strings do not survive `platformio.ini`
   (`-DFW_VARIANT="n16r8"` arrives unquoted → numeric `-DFW_IS_N16R8=1`
   instead); Arduino-ESP32 2.0.x `HTTPUpdate` has no `followRedirects` →
   OTA install streams via `HTTPClient` (`setFollowRedirects`) + `Update`.
- Termux shell: aarch64 Android 12, clang 21, Python 3.14, `pio` 6.2.0 installed
  (native tests OK). Debian container: Python 3.13, GCC 14, `gh` 2.46.0.
- `scripts/setup-linux.sh` (apt + venv + tests) vs `scripts/setup-termux.sh`
  (pkg + workarounds + tests) — the "linux version + termux version" request.

**v2.4 build-environment discovery (2026-09-22, keep this):** Python 3.14
reports `android_aarch64`, for which the registry has NO toolchain builds —
Termux-side `pio run` fails at package resolution even though the registry
is reachable. Fixes, in order:
1. `export PLATFORMIO_SYSTEM_TYPE=linux_aarch64` (official override) → the
   cached-version toolchain + framework download fine (binaries run under
   proot-Debian glibc; they canNOT exec on Termux bionic — `cannot execute:
   required file not found`).
2. So firmware compiles ONLY inside proot-debian:
   `proot-distro login debian -- sh -c 'export PATH=/root/.local/bin:$PATH;
   pio run -d <project> -e esp32-s3-devkitc-1 -e s3-n16r8'`
   (Debian has its own pio core at `/root/.local/bin/pio` + warm
   `/root/.platformio`; Termux home is visible inside proot at the same path).
3. `tool-esptoolpy` needs hand-provisioning (its auto pip step builds
   `cryptography` from source → no Rust here): esptool 4.11 sdist +
   `package.json` (v2.41100.260830) + `_contrib` with pure-python
   pyserial/intelhex/ecdsa/six, PLUS a 1-line local patch
   (`list_ports_posix.py`: accept `sys.platform == 'android'` like linux —
   pyserial 3.5 predates Android). Secure-boot signing (the only
   cryptography consumer) is unused by our builds. If `packages/` gets wiped
   again, redo §8 steps 1–3 (framework/toolchain re-download; esptoolpy
   re-assemble).
4. `tools/virtual_bus.sh` hardcodes `/tmp` (read-only/absent on Termux) →
   run it in proot-debian (socat + pyserial present there).

---

## 9. QEMU saga (complete, honest state)

Goal was 3/3 emulation layers; achieved 2.5/3. QEMU-S3 built FROM SOURCE on
the phone (official ARM64 prebuilt aborts under proot — gdb proved static-glib
`g_quark_init` assert) and boots OUR firmware to the Arduino flash-init step,
where it asserts at IDF-4.4.8 `startup.c:328`
(`assert(esp_flash_init_default_chip() == ESP_OK)`).

Traced with `-d guest_errors` + fixed two REAL upstream flash-model bugs
(patch: `esp32s3-qemu-arm64/patches/qemu-m25p80-rdid-sfdp-gd25q64.patch`):
1. RDID `0x90`/`0xAB` unanswered for non-SST parts → now generic (JEDEC-based).
2. GD25Q64 (8 MB image part) had no SFDP → `0x5A` failed → added 256-B table.
3. `0x77` Set-Burst-with-Wrap → accept-and-ignore (trace-confirmed gone).
Stage-0 baseline 2026-09-21 (`tools/qemu_boot_test.sh`, v2.3 n16r8 image,
45 s, IN proot-debian — JIT-stale note above is dead): **81×
`Unknown cmd 0x10` (QEMU prints `%x` without prefix — "10" IS 0x10),
0× `0x10200C`, 1 POWERON + 81 RTC_SW resets** — i.e. exactly ONE cmd-0x10
per boot attempt, then crash-loop; the 0x77 patch killed the whole 0x10200C
class. UART0 shows only ROM output (repeating `mode:DIO … entry 0x403c98d0`).
Observability constraint: firmware `STATUS?`/logs live on USB-Serial, NOT
UART0 — so Stage-A pass = zero flash errors + reboot loop STOPS (+ Stage-B
GPIO proof), not a literal `STATUS?→RED` over UART0.
Stage-A trace (`TRACE_EVTS="m25p80_command_decoded"`, full 26-cmd iteration):
`AB 9F 05 05 9F 5A 05 05 35 00 05 05 35 00 06 31 02 05 35 00 77 00 00 00 10 04`
— driver runs init TO COMPLETION (ends WRDI `04`); `77 00 00 00 10` =
Winbond-style burst-wrap disable (3× dummy `00` + wrap byte `10` = wrap
DISABLED, fire-and-forget, zero functional damage); `31`=WRSR2,
`02`=PAGE PROGRAM at boot is suspicious (possible WRSR2-data desync:
GIGADEVICE consumes 0 data bytes?).
Stage-A ROOT CAUSE (GDB + disassembly, 2026-09-21): the `02` is the WRSR2
*data byte* misdecoded — GD consumed 0 bytes, QE write lost, read-back saw
QE=0 → `startup.c:328` assert path. Fix (NOT yet upstreamed to the emulator
repo — patch file `esp32s3-qemu-arm64/patches/` + applied to `/opt/qemu-src`
working tree only): WRSR2 consumes/persists the QE bit for GIGADEVICE +
`0x77` consumes 3 dummy + wrap byte. Result: flash model 100 % clean
(`qemu_boot_test.sh` PASS, 0/0) — **but the guest STILL reset-loops**.
Deeper GDB: reset is a genuine guest `SW_SYS_RESET` (`esp_restart_noos` at
bootloader `0x403cdb08`, called from entry+0x15) because **`bootloader_init`
returns `0x0a`** (SITE1 breakpoint; load-boot-image + index paths never
reached). So the 2nd-stage bootloader itself bails before the app starts;
UART0 stays ROM-only (app logs are USB-Serial). PARKED here — bench bugs
took priority. Resume: figure out which `bootloader_init` step returns
0x0A (clock? flash-ID? partition-read via XIP?) — disassemble forward from
`0x403c9938`, or catch the failing call with GDB breakpoints. Temp S3DBG
`mem_io_pc→cc->get_pc` debug print is UNCOMMITTED in `/opt/qemu-src`
(`hw/misc/esp32s3_rtc_cntl.c`) — revert before any upstream patch submission.
Next agent: to continue, decode what `0x10` is in DIO context (possible status-
register or continuous-read mode byte); or deprioritize — host tests + soak
already prove the firmware.
Hypothesis: DIO-era command bytes hitting the single-line SSI model + an
unmodeled register region. IDF-based guests are unaffected per Espressif CI;
Arduino guests were never QEMU-supported. Verdict: **emulator gap, not firmware
— our code is never reached.** Re-confirmed on v2.1 image (same signature);
v2.3 baseline above via `tools/qemu_boot_test.sh` (exact test: PASS iff zero
0x10 + zero 0x10200C; `BASELINE=1` records signature).
Practical emulation = Wokwi (`wokwi/` v2.1: verified pins, relay modules,
`sim.yaml` automation; browser run manual, headless needs `WOKWI_CLI_TOKEN`).
`tools/run_qemu_s3.sh` = one-command boot test for real Linux/Mac.
Next agent: to continue, decode what `0x10` is in DIO context (possible status-
register or continuous-read mode byte) and identify the `0x10200C` peripheral;
or deprioritize — host tests + soak already prove the firmware.

---

## 10. GitHub access & pushing

- Account `bm-a` (Bhavishya Madan). Pushing needs a normal account + classic
  PAT with `repo` scope. `gh` authenticated (Termux `~/.config/gh/hosts.yml`,
  0600). Plain `git push` / `git tag` / `gh release create` work from the
  Termux shell via the gh credential helper — verified for v1.2 + v2.0.
  (Old note: pushes once had to go via the Debian container; no longer true.
  If a push ever fails with auth errors, `gh auth status` first, then
  `gh auth setup-git`.)
- A PAT (`ghp_…`, full permissions) was **pasted in chat on 2026-09-18**.
  It is NOT stored in any file. **Still recommend the user revoke/rotate it**
  — chat logs persist. (Outstanding since v1.1.)
- Commit identity: `bm-a` / `bm-a@users.noreply.github.com`.
- Releases: v1.0 (ZIP), v1.1 (3 bins + docx), v1.2 + v2.0 + v2.1 + v2.2 + v2.3
  (7 assets each: 8 MB triple plain-named + `n16r8-` triple — GitHub forbids
  duplicate asset names, so N16R8 files are uploaded renamed; docx re-uploaded
  with `--clobber` when only the report changes). v2.7: tag + release live
  with dash-full.png + dash-lite.png + demo.gif (inspected before upload);
  firmware bins PENDING bench-PC build (§11.2). Wiki backend provisioned
  (one browser click); push via the `.wiki.git` clone.
- Re-run `gh release create` only if assets change.

---

## 11. Pending / next steps (ordered)

0. **Post-compaction resume:** say "continue" — todo list is ordered top-down
   (HANDOFF delta → QEMU Stage 0 → A → B → C → D → bench + housekeeping).
1. **Bench test v2.7 with real meter + SmartElex module** (same list as the
   v2.6 bench plan, plus): FULL bench SVG live on the phone (relays glow,
   A/B flow pulses, meter readout follows golden→spoof), LITE/CLASSIC smoke
   (tiles + names + link), `STATUS?` → `2.7`, relay names survive reboot (NVS).
   Full list: (a) responder still green ≤ 1 s, ~52 V/100 %; (b) join
   from an iPhone → mini-browser shows the landing page → Open Dashboard in
   Safari works (or manual 192.168.4.1); Android same via Chrome; (c) trigger
   Save stores pin/enable/polarity with no fire; polarity flip changes the
   physical-switch sense; (d) per-mode menu + chase + dead-band + rejects as
   v2.4; (e) one-file flash per board (`write-flash 0x0 bms-tester-*.bin`) →
   boots → `STATUS?` → `2.7`; (f) STA test → on-demand URL upgrade installs;
   (g) GPIO18 kill still kills; (h) meter card: first GREEN = #1, reseat gap
   ≥ 3 s opens #2 with pass/fail verdict, retries don't count, New-day
   resets.
   If the page still won't open: confirm flashed firmware is v2.7
   (`STATUS?` → `2.7`; v1.x has no WiFi at all), AP visible, exact URL/error.
   Needs: 12 V coil supply with common GND; 48 V rail per relay COM, each NO
   to its OWN load (never two outputs on different potentials).
2. **DONE 2026-09-23 evening — v2.7 bins built on-phone + uploaded:**
   rebuilt proot-debian, `tools/merge_releases.py v2.7 --keep` (8m05s, magic +
   version verified) → Termux `gh release upload` of all 4 bins. Sim live-GH
   gate PASSES; sim check on live data: latest `v2.7`, assets present.
   REMAINING: one real box Check→Install to prove the pull end to end (STA
   uplink + TLS + flash write are hardware-only). v2.7 tag (`ca3ffe0`) is
   firmware-identical to current main — shipped bins are tag-correct.
2. **Add `WOKWI_CLI_TOKEN` repo secret** → token-gated CI sim proves the real
   firmware headless (button→pins, spoof→`22 B0`); also answers whether
   `WiFi.softAP` boots in the sim (dashboard HTTP itself has no emulator —
   covered by `test_web` instead).
3. **HIL pytest** + manual Wokwi run + dashboard browser pass once hardware/PC
   available.
4. **QEMU full-S3 program (user-approved, staged, phone-proot testing):**
   Stage 0 exact-test harness (`tools/qemu_boot_test.sh`: assert zero
   `Unknown cmd 0x10` + zero `0x10200C` + `STATUS?` → `RED`); Stage A boot
   past flash-init (identify `er` via `info mtree`, byte-level SPI trace,
   patch as `patches/qemu-s3-flash-part2.patch` in the emulator repo);
   Stage B GPIO observability; Stage C UART2/RS485 via `virtual_bus.sh`;
   Stage D Wi-Fi verdict spike (prototype or declare Wokwi the path).
   Signatures: ~22× `0x10` interleaved with ~84× `0x10200C`, then
   `startup.c:328` assert loop. Stop rules: unmodeled-peripheral wall →
   bank evidence + options (no silent grind); proot unexecutable → CI
   boot-smoke instead. (Old "Possible v2.1" ideas are DONE in v2.3:
   relay labels, STA uplink, `delay(1)` obsolete.)
5. **Housekeeping:** rotate the chat-exposed PAT (outstanding since 2026-09-18);
   re-check CI after any push; Google index lag is normal.

---

## 12. File inventory + RELEASE CHECKLIST (read this before any release)

Project: `platformio.ini README.md CHANGELOG.md LICENSE VERSION HANDOFF.md
RS485-Tester-Report.docx run_tests.sh src/ test/ tools/ arduino/ firmware/
firmware-n16r8/ wokwi/ local-wokwi/ enclosure/ captures/ docs/ scripts/ wiki/
releases/ .github/ .gitignore .unity/ .pio/`
(`.pio .unity releases/ *.log tc.json .test_* local-wokwi/labels.json
local-wokwi/server*.log local-wokwi/shots/` git-ignored; `releases/` holds
v1.0 ZIP + 2 git bundles — offline full-history backup, verified by test-clone.
Back it up before ANY storage compaction: it exists nowhere else.)
Wiki canonical sources live in `wiki/` (Home, Flashing, Hardware, Protocol,
Emulators, Versions, Relays, Dashboard) and are pushed to the `.wiki.git` backend.
`Actual Meter Image/` (real meter photos) was removed 2026-09-27; the 3D sim
now uses a procedural meter face texture. `src/ota.*` (OTA decisions) + `test/test_ota/` + `test/test_web/Update.h`
(upload stub) are v2.3 additions; v2.4 adds `src/fw_upload.h` +
`test/test_upload/` + stubs `ESPmDNS.h`/`esp_system.h` (info card/mDNS);
v2.5 adds `tools/fw_emu/` (socket harness + drivers) + `docs/CONFIG-SCHEMA.md`
+ `docs/EMULATION-v2.5.md` + stub `uri()` (portal tests); v2.6 adds
`test/test_meter/` + `/__bus` control + merged `bms-tester-*.bin` images;
v2.7 adds `WEB_UI_VARIANT` pages + `mv/ma/msoc` + `s3-classic`/`s3-lite` envs
+ `local-wokwi/` (sim server, Three.js bench, verbatim ESP embed, `shots.py`)
+ `enclosure/` (IP65/GX16/dual-buck docs) + `tools/merge_releases.py`
(per-tag bin pipeline, needs debian+pio).
Termux home `archive/` — pre-existing clutter, leave alone.
Emulator work (`/opt/qemu-src` 1.1 GB, `/opt/qemu-s3` 94 MB, `/opt/pioenv`
76 MB, `/root/.platformio` large) is inside the Debian container — see §8
before wiping proot data. Wiping it costs ~1 h rebuild (QEMU 20–40 min +
PIO packages + Xtensa tarball workaround); losing `.pio` (102 MB) is free
(re-downloads).

**Release checklist — EVERY feature release MUST do all of these in the
release commit (lesson learned 2026-09-22: HANDOFF body went stale at v1.1
while README/CHANGELOG moved on — never again):**
1. `src/` + `arduino/` tabs identical (diff-check every file, incl. new `fw_upload.h`).
2. `VERSION` + `FW_VERSION` + `STATUS?` strings bumped together.
3. `CHANGELOG.md` new entry; `README.md` versions/table/SHAs; `docs/MODULES.md`
   pins; `llms.txt` counts + code map; `test/README.md` counts;
   `tools/README.md` if helpers changed; `arduino/README.md` wiring/tabs;
   `wokwi/README.md` if diagram changed; `platformio.ini` test_filter for new
   suites; `tools/make_report.py` strings + regen docx.
4. `firmware/` + `firmware-n16r8/` rebuilt from exact source + SHAs in READMEs;
   `RS485-Tester-Report.docx` regenerated via `make_report.py`.
5. `wiki/` sources updated + pushed to `.wiki.git`.
6. **This HANDOFF**: update §§1–5, 7–12 in the body (no addendum-only updates),
   then commit → tag → push → `gh release create` (n16r8 assets renamed) →
   confirm CI green.

Resume checklist: `ls /opt/qemu-src/build/qemu-system-xtensa && pio --version`
(toolchain-alive check — if empty, rebuild per §8) → `git log --oneline |
head -3` → `git status --short` → `pio test -e native` (Termux) →
`sh run_tests.sh` → `sh tools/virtual_bus.sh` (in proot — /tmp) → emu
drivers (`fw_emu` + `drive_emu.py` + `drive_soak.py`, ports 18080/18081) →
compare against §7 numbers (152/152 + contract + 72/72 emu). Firmware builds
run ONLY in proot-debian per §8 (Termux pio = host tests only).

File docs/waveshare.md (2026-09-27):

# Waveshare ESP32-S3-POE-ETH-8DI-8DO build (`s3-waveshare`)

Board-variant firmware for the **Waveshare ESP32-S3-POE-ETH-8DI-8DO**
(ESP32-S3-WROOM-1-N16R8: 16 MB flash, 8 MB OPI PSRAM; the `s3-waveshare` env
and the `BOARD_WAVESHARE_8DI8RO` flag keep their historic 8DI8RO names — the
EXIO/GPIO interface is identical on the 8DO). Same BMS-impersonation
protocol, same output-test logic, same web dashboard as the generic build —
only the hardware abstraction and pin mapping change.

**Wiring:** see [waveshare-wiring.md](waveshare-wiring.md) for the complete
connection guide — every screw terminal, RS485 A/B + 120R jumper, DO
(NO/COM/NC) wiring, DI wiring, what each LED means, and step-by-step bench
bring-up.

## Pin map (verified against the official Waveshare 8DO wiki + 8DO demo code)

| Function | Waveshare | Notes |
|---|---|---|
| Outputs DO1–DO8 | TCA9554PWR **EXIO1–EXIO8** @ I²C `0x20` (SDA **GPIO42**, SCL **GPIO41**) | Output-register bit *i* = channel *i+1*; **HIGH bit = ON** (Darlington sink outputs, 500 mA); parked **OFF** at boot (deliberate safe-boot divergence from the demo's all-ON) |
| RS485 | TX **GPIO17**, RX **GPIO18** | Onboard isolated SP3485; direction on **GPIO21** via ESP32 UART **RS485 half-duplex mode** (`setPins(-1,-1,-1,21)` + `setMode()`, exactly like the official 8DO demo `WS_RS485.cpp`); manual DE drive is only a `setMode()` fallback |
| START/STOP button | **GPIO0** (BOOT) | Press = LOW; 10 s hold = factory reset (unchanged behavior) |
| Spoof trigger | **GPIO4** (DI1 terminal) | Active = LOW; web-changeable to DI1–DI8 (GPIO4–11) |
| Wi-Fi kill | **GPIO5** (DI2 terminal) | Active = LOW = AP off |
| Status lamp | **GPIO38** (onboard WS2812) | Green = link, red = silent (no discrete LEDs on this board); RGB byte order (R/G swapped on the wire, per the demo). Flashes red while the TCA9554 output expander is unreachable |
| Free inputs | DI3–DI8 (**GPIO6–GPIO11**) | Opto-isolated, active LOW |
| Ethernet (W5500) | **GPIO12–16** (INT12/MOSI13/MISO14/SCLK15/CS16, RST **GPIO39**) | DHCP client, hostname `bms-tester`; dashboard answers on the Ethernet IP too (`eth_ip` in /api/state). Best-effort: failure never blocks boot or Wi-Fi |
| Buzzer | **GPIO46** (LEDC 1 kHz / 8-bit / duty ≤ 200) | Link up/down beep, sequencer start/stop beeps, output-driver failure alarm. Dashboard **Buzzer** card toggle (`buzz` in `/api/config`, `"buzzer"` in `/api/state`); default **OFF** — silent until enabled |
| Reserved | GPIO40 (RTC int) | Untouched by firmware |

DI1–DI8 are opto-isolated: wire the trigger/kill as a dry contact or driven
signal between the DIx terminal and COM per the Waveshare DI wiring (active
pulls the GPIO LOW). The existing `button_invert` / `spoof_invert` toggles
still flip the sense if your wiring differs.

Two deliberate differences from the generic build:

- **Output polarity is fixed.** The TCA9554 output stage drives HIGH-bit =
  ON in hardware, so the web **Logic (active-low) dropdown is disabled** on
  this board (greyed out, tooltip explains it's fixed Active-HIGH).
  Dashboard output labels always match the hardware.
- **Ethernet is integrated (best-effort).** The W5500 (SPI SCK15/MISO14/MOSI13,
  CS16/IRQ12/RST39) gets a DHCP address via ESP-IDF `esp_eth` and the
  dashboard answers on it (`eth_ip` in /api/state, `ETH ip` in the
  Information card). The always-on `BMS-Tester` Wi-Fi AP stays exactly as
  before; an Ethernet failure never blocks boot or touches Wi-Fi.

One deliberate difference from the official Waveshare 8DO demo:

- **Boot parks all outputs OFF (`0x00`).** The demo's `Dout_Init()` writes
  `0xFF` (all channels ON at boot); this firmware writes `0x00` instead —
  the safe boot state for an automated test bench. The register *order*
  (OUTPUT register before CONFIG register) matches the demo exactly.

## Wi-Fi

The board brings up a Wi-Fi access point on boot (same as the generic
build):

| Setting | Default | Notes |
|---|---|---|
| AP SSID | `BMS-Tester` | (`WEB_AP_SSID_DEFAULT` in `src/web_ui.h`) |
| AP password | `bms12345` | (`WEB_AP_PASS_DEFAULT`; min 8 chars) |
| Admin password | `admin123` | Gates reboot, factory reset, update upload, and saves in the web UI |

All three are changeable from the web UI **admin tab** (leave a password
field blank to keep the current value; settings persist in NVS across
reboots). The defaults above apply to a fresh flash or after a factory
reset (hold BOOT 10 s).

- **Wi-Fi kill switch:** DI2 terminal (**GPIO5**), active LOW = AP off.
  Ground DI2 to drop the AP, release to bring it back.
- **STA client mode** is also available from the web UI admin tab: the box
  can join your own network instead of (or as well as) hosting the AP.

## Build

```sh
pio run -e s3-waveshare          # .pio/build/s3-waveshare/firmware.bin
```

## First flash (new board)

The release ships a **merged one-file image** `bms-tester-waveshare.bin`
(bootloader + partitions + app). Flash at offset `0x0`:

```sh
esptool.py --chip esp32s3 --port /dev/ttyACM0 write_flash 0x0 bms-tester-waveshare.bin
```

(If the upload doesn't start: hold **BOOT**, press/release **RESET**, then flash.)

## OTA / updates

This board runs its **own release line**: prerelease tags `v2.7-wsN`, asset
`waveshare-firmware.bin`, firmware version `2.7-wsN`.

- Prereleases never become GitHub `/releases/latest`, so generic boards'
  auto-OTA is unaffected — and the Waveshare box scans `/releases` for its
  own `-wsN` tags instead of `/releases/latest`.
- Version compare treats the two lines as incomparable (`2.7` == `2.7-ws1`):
  a generic release can never auto-install onto this board and vice versa.
- Manual upload (`/update`) and custom-URL OTA still enforce the
  exact-variant filename gate: only `waveshare-firmware.bin` is accepted.

## Tests

`sh run_tests.sh` includes `test_waveshare` (16 tests): pin map, TCA9554
output-byte mapping + relay-count clipping, DI-only spoof allowlist, `-wsN`
version/compare/URL/tag rules, the variant asset + filename gates, and the
official-8DO-demo alignment checks (RS485/TXD1EN pins, TCA register map,
init order, output polarity). **171 native tests, 0 failures**, plus the
30-day soak sim (2,591,400 polls/replies, PASS).

## Emulation verification (QEMU, ESP32-S3)

The compiled firmware was exercised in QEMU (Espressif fork) against a
virtual JBD meter. Results:

| Feature | Result | Notes |
|---|---|---|
| RS485 0x03/0x04/0x05 | PASS | Valid checksums; silence on writes/unknown/garbage |
| Link/GREEN | PASS | GREEN with sustained traffic |
| 8 outputs (TCA logic) | PASS | Sequencer bytes 0x01→0xFF observed; busfail-park-safe on I²C error |
| START/STOP (BOOT) | PASS | Press starts sequencer; 10 s hold factory-resets |
| SPOOF (DI1) | PASS | Stage 1 (100.0 V) + stage 2 (88.8 V) frames live via DI1 trigger |
| Wi-Fi kill (DI2) | PASS | DI2 edge → AP-off handler fires |
| Physical TCA9554/DI/UART2 | UNTESTED | QEMU has no I²C controller, GPIO stub, or UART2 chardev |
| Ethernet | N/A | Not implemented |

Two firmware fixes came out of emulation and are in this release:
1. **TCA init order**: output register `0x00` is now written *before*
   configuring pins as outputs (prevents output glitch at boot) — the same
   OUTPUT-before-CONFIG order the official 8DO demo uses.
2. **OTA scan**: the Waveshare build now scans all `-wsN` releases and picks
   the *newest by version* (not just the first valid tag).

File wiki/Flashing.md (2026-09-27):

# Flashing — all different ways (v2.9)

Bring-up terminal

*Sim → sequence → `STATUS?` → flash: the whole bring-up in three commands.*

Pick **one** method. v2.9 ships the **Waveshare**
(ESP32-S3-POE-ETH-8DI-8DO, FULL dashboard on the board pin map) line; the
generic line's last release is v2.8.10. Both report `FW_VERSION` and
OTA-check `/releases/latest`, each downloading its own variant asset.

## 1. Ready binaries with esptool (any PC, no IDE) — ONE file, ONE command
1. `pip install esptool`
2. Choose the file for your board from the **v2.9.0 release assets**:
   - `bms-tester-waveshare-v2.9.0.bin` — Waveshare ESP32-S3-POE-ETH-8DI-8DO.
     Merged image (bootloader@0x0 + partitions@0x8000 + app@0x10000).
   - `waveshare-firmware.bin` — Waveshare app-only image (for the dashboard
     `/update` upload path on a Waveshare box, and the board's OTA target).
3. Plug in the S3, find the port (COMx / /dev/ttyACM0), then:

```
esptool.py --chip esp32s3 --port <PORT> --baud 460800 write-flash 0x0 <FILE>
```

Verify against the SHA-256 sums published in the v2.9.0 release notes.

## 2. Browser flasher (no installs)
Open an ESP Web Tools flasher (e.g. https://www.espthings.io/tools/esp32-flasher/),
load the ONE merged file for your board at `0x0`, flash, done.

## 3. Separate files (advanced / partial re-flash)
`bootloader.bin` + `partitions.bin` + `firmware.bin` for the classic
three-address flash (`0x0` / `0x8000` / `0x10000`).

## 4. PlatformIO (VS Code)
Open the repo folder, let PIO install, then upload:
- `esp32-s3-devkitc-1` — 8 MB generic board, FULL dashboard (default).
- `s3-waveshare` — Waveshare ESP32-S3-POE-ETH-8DI-8DO (16 MB flash, OPI PSRAM,
  `default_16MB.csv`, TCA9554 relays, FULL dashboard).
- `s3-n16r8` — generic N16R8 (16 MB flash, OPI PSRAM, FULL).
- `s3-classic` / `s3-lite` — CLASSIC / LITE dashboard on 8 MB boards.
All compile the same `src/` — only the dashboard page and board pin map differ.

## 5. Arduino IDE (no PlatformIO)
1. Install Arduino IDE, add `https://espressif.github.io/arduino-esp32/package_esp32_index.json`,
   install **esp32 by Espressif**.
2. Open `arduino/bms_connection_tester/bms_connection_tester.ino`
   (the `.h`/`.cpp` tabs open automatically — identical logic to `src/`).
3. Board **ESP32S3 Dev Module**, **USB CDC On Boot Enabled**, Upload **921600**;
   N16R8 additionally: **Flash Size 16MB**, **PSRAM OPI PSRAM**.
   For the Waveshare board add `-DBOARD_WAVESHARE_8DI8RO=1` to the build flags
   (or just use the PlatformIO `s3-waveshare` env — recommended).
4. Pick the port, Upload.

## First-boot check
1. Red LED (or red RGB on Waveshare) comes on at boot.
2. AP **`BMS-Tester`** appears — join it (password `bms12345`).
3. With a meter polling on A/B, the LED flips green (≤ 1 s after the first
   valid frame).
4. Send `STATUS?` on the USB serial (115200): expect `RED 2.8` silent,
   `GREEN 2.8` while a meter polls.

## After that — no more cables for updates
Join the AP, open the dashboard's **Firmware card**: upload a `.bin` from a
later GitHub release (offline, always works), or enter a hotspot Wi-Fi once
and let the box update itself when idle (OTA checks `/releases/latest`;
generic boxes pull `firmware.bin`, Waveshare boxes pull
`waveshare-firmware.bin`).

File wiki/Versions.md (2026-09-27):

# Versions / Changelog (Keep a Changelog)

## [v2.9.0] — 2026-09-27
### Full Waveshare 8DO support: Ethernet, buzzer, fault alarms
- **W5500 Ethernet** via ESP-IDF `esp_eth` (Arduino-ESP32 2.0.17 has no
  W5500 support; the official demo needs ≥ 3.0). Demo pinout (SPI
  SCK15/MISO14/MOSI13, CS16, IRQ12, RST39, PHY addr 1), DHCP client,
  hostname `bms-tester`. The dashboard answers on the Ethernet IP too
  (`eth_ip` in `/api/state`, `ETH ip` in the Information card). Best-effort:
  any failure just skips Ethernet — boot, AP (192.168.4.1), STA, captive
  portal and OTA policy are never affected.
- **Buzzer** on GPIO46 (LEDC 1 kHz / 8-bit / duty ≤ 200, official demo
  values): short beep on meter-link up/down, 200 ms on sequencer start,
  500 ms flicker on sequencer stop, one-shot 5 s flickering alarm on
  output-driver failure. Non-blocking pattern engine, drained from loop();
  never driven before setup() (GPIO46 is a strapping pin).
- **TCA9554 fault surfacing**: latched `ok|fail` — `"expander":"ok"|"fail"`
  in `/api/state`, RGB flashes red while the expander is unreachable (demo
  DoutFailTask pattern), one-shot buzzer alarm. Safe-boot park 0x00 and
  write-retry unchanged; self-heals when the bus recovers.
- **Docs**: USB-OTG jumper warning — do not connect the board to a computer
  while the jumper is set to USB-OTG (the jumper feeds external power
  through Type-C).
- Routing note: with WiFi STA + Ethernet both up, outbound traffic follows
  lwIP's default interface (most recently connected). The STA-online gate
  for OTA checks is unchanged.
### Verified
- **182/182** native tests (0 failures), `pio run -e s3-waveshare` and
  `-e esp32-s3-devkitc-1` SUCCESS, 30-day soak: 2,591,400 polls/replies,
  millis rollover crossed, PASS.

## [v2.8] — 2026-09-27
### Meter counter: 5 s settle fumble guard
- A link gap ≥ 3 s now only **arms** a reseat candidate; the new meter
  **commits** after GREEN holds 5 s (`LINK_SETTLE_NEW_METER_MS`). A scratchy
  reseat (seat 4 s, pull, seat properly) no longer double-counts one unit.
- The closing meter's verdict is **snapshotted at arm time**, so an eager
  START during the settle window attributes to the new meter; a RED before
  the settle merges the window's activity back (same meter all along).
- A yank mid-cycle **invalidates the test**: the previous meter closes as
  fail (an interrupted test was never honestly a pass).
- Dashboard Meters-today note updated; `test_meter` grows fumble +
  eager-start cases (12/12).

### Unified release line
- One v2.8 tag ships **generic FULL** (8 MB ESP32-S3) + **Waveshare**
  (ESP32-S3-POE-ETH-8DI-8DO) firmware. The Waveshare `-wsN` prerelease line is
  retired: both boards report `FW_VERSION 2.8` and both OTA-check
  `/releases/latest`, each downloading its own variant asset
  (`firmware.bin` / `waveshare-firmware.bin`).

### Docs from scratch
- In-depth README rewrite; two new from-scratch build guides:
  `docs/BUILD-DIY.md` (generic board, build it yourself) and
  `docs/BUILD-WAVESHARE.md` (all-in-one board); this wiki overhauled page
  by page (new [[Building]] page).

### Verified
- **166/166** native tests (`test_meter` 12/12, `test_web` 49/49,
  `test_waveshare` 12/12), 3-variant web contract PASS, 30-day soak PASS.

## [v2.7] — 2026-09-23
### Dashboard variants at a glance

| FULL (default) | LITE |
|---|---|
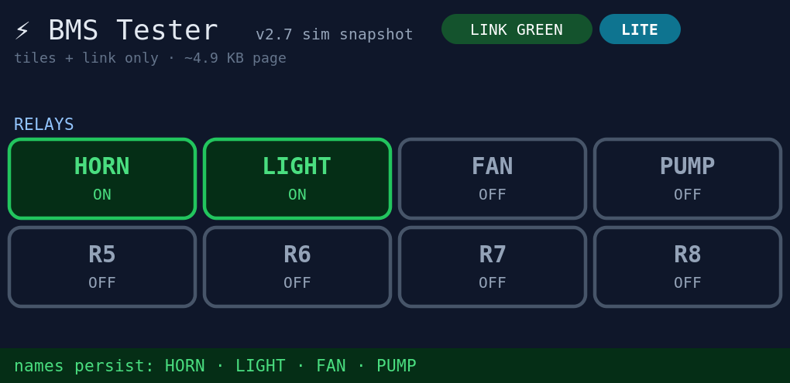
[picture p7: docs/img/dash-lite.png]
LITE
| FULL |  |
| bench SVG + tiles + meters + all cards | tiles + names + LINK pill only |

Sequential + spoof demo

### Added
- Three dashboard variants, one per build (`WEB_UI_VARIANT`):
  CLASSIC (`s3-classic`) = v2.6 page verbatim; FULL (default) = classic +
  live inline SVG bench card + tile glow + meter readout (`mv/ma/msoc`);
  LITE (`s3-lite`) = relay tiles + names + LINK pill only. Relay names
  NVS-persistent in all three. OTA assets stay FULL builds.
- Proven: 103/103 native, 49/49 web, contract 3/3, soak PASS, OTA units 6/6,
  GH assets present, download URL HTTP 200. ESP compile + real OTA pull
  need hardware (HIL skipped).

## [v2.7-ws1] — 2026-09-26 (Waveshare board line, retired in v2.8)
### Added
- Waveshare ESP32-S3-POE-ETH-8DI-8DO board variant (`s3-waveshare`): relays via
  TCA9554PWR @ I2C `0x20` (SDA42/SCL41, HIGH bit = ON), isolated RS485
  TX17/RX18 with hardware auto-direction, BOOT (GPIO0) = START/STOP,
  DI1 (GPIO4) = spoof trigger, DI2 (GPIO5) = WiFi kill, RGB on GPIO38.
  Own OTA line (`FW_VERSION 2.7-ws1`, `waveshare-firmware.bin`,
  `v2.7-wsN` prerelease tags). Proper 1.04 MB merged image
  (bootloader@0x0 + partitions@0x8000 + app@0x10000).
- Superseded by the unified v2.8 release (no more `-wsN` tags).

## [v2.6] — 2026-09-22
### Added
- Daily meter-test counting (software-only estimate, no button, no new
  GPIO): `MeterBatch` (meters/attempts/pass/fail in RAM, flat NVS
  `m_met/m_att/m_ps/m_fl` flushed on close/reset only), fed from the live
  link state every loop — RED gap ≥ 3 s closed by GREEN = reseat = new
  meter; steady GREEN across RESTARTs = same meter; flickers stay; mid-cycle
  gaps defer to IDLE. Manual New-day reset (no RTC; boot persists, backups
  exclude counters, seated unit re-opens as #1). Console `DAYRESET`.
- Round link dots (green/red) in the dashboard header beside the LINK pill.
- One-file flash images: `firmware/bms-tester-8mb.bin` +
  `firmware-n16r8/bms-tester-n16r8.bin` (merged bootloader+partitions+app,
  `write-flash 0x0 <file>`, structure-verified).
- Spoof edit+save confirmed as the existing two-stage feature (no new mode):
  stage 1 = all-1s (100), stage 2 = all-8s (88.8/188), both editable.
- 10-test `test_meter` suite + 5 web meter tests + 8 emu HTTP checks
  (plus new `/__bus` emu control for the RS485 bus state).

## [v2.5] — 2026-09-22
### Fixed
- Multipart upload auth: the done handler demanded streamed field AND parsed
  arg, but real servers never populate args for multipart — every real
  upload 403'd (host stub had masked it). Streamed field alone now decides.
- JSON parser rejected `"key": value` whitespace (python-requests style) —
  same bug class as the v2.3.1 tag-space parse. All helpers tolerant now.
- On-demand STA join: check/install/URL join with saved creds themselves
  (test-then-install finally works end to end).
### Added
- Trigger group (enable + GPIO + polarity + Save-trigger), captive-portal
  landing page for phones, structured config schema (`docs/CONFIG-SCHEMA.md`,
  v1+v2 backups), socket emulation harness (`tools/fw_emu`, 64/64 over real
  HTTP), 30-day soak (2.59 M polls, 309 k cycles, 30 NVS commits),
  `docs/EMULATION-v2.5.md` per-feature report.
- 135/135 host tests (44 web) + contract + soak + virtual-bus + both PIO envs.

## [v2.4] — 2026-09-22
### Fixed
- Firmware upload rebuilt Tasmota-style: exact variant-asset match, explicit
  sketch budget, image-head gate, single finalize, progress bar, named errors
  (a wrong file or password changes nothing).
### Changed
- Relay timing floors (step ≥ 100 ms default 250, stagger default 50,
  pause 500–60000 default 2000); chase gains a fixed 20 ms break-before-make;
  START refused 0.5 s after STOP; mode switch needs IDLE; loop needs a
  finite hold; count-shrink acts immediately; RESTART keeps tile forces.
- Dashboard shows only the active mode's fields; spoof card has Save-only;
  OTA interval editable; AP/STA saves offer Save + reboot.
### Added
- Web console, config backup/restore (passwords never exported), custom OTA
  URL + Upgrade-from-URL, one-shot STA uplink test (no reboot), Information
  card (variant/flash/sketch/heap/uptime/bootcount/reset reason/RSSI/pin
  map), mDNS `bmstester.local`, keep-WiFi reset, boot-counter reset.
- 134/134 tests (36 relay incl. R18–R31, 41 web, 5 upload gates) + contract
  (single-end rule, no SIZE_UNKNOWN) + soak + virtual-bus + both PIO envs.

## [v2.3.1] — 2026-09-21
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

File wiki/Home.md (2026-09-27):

# bms-connection-tester wiki — Home

ESP32-S3 firmware + hardware that impersonates a **JBD / Xiaoxiang Smart BMS**
over RS485, so compatible meters, displays, or hosts can be exercised
**without the real battery pack**.
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

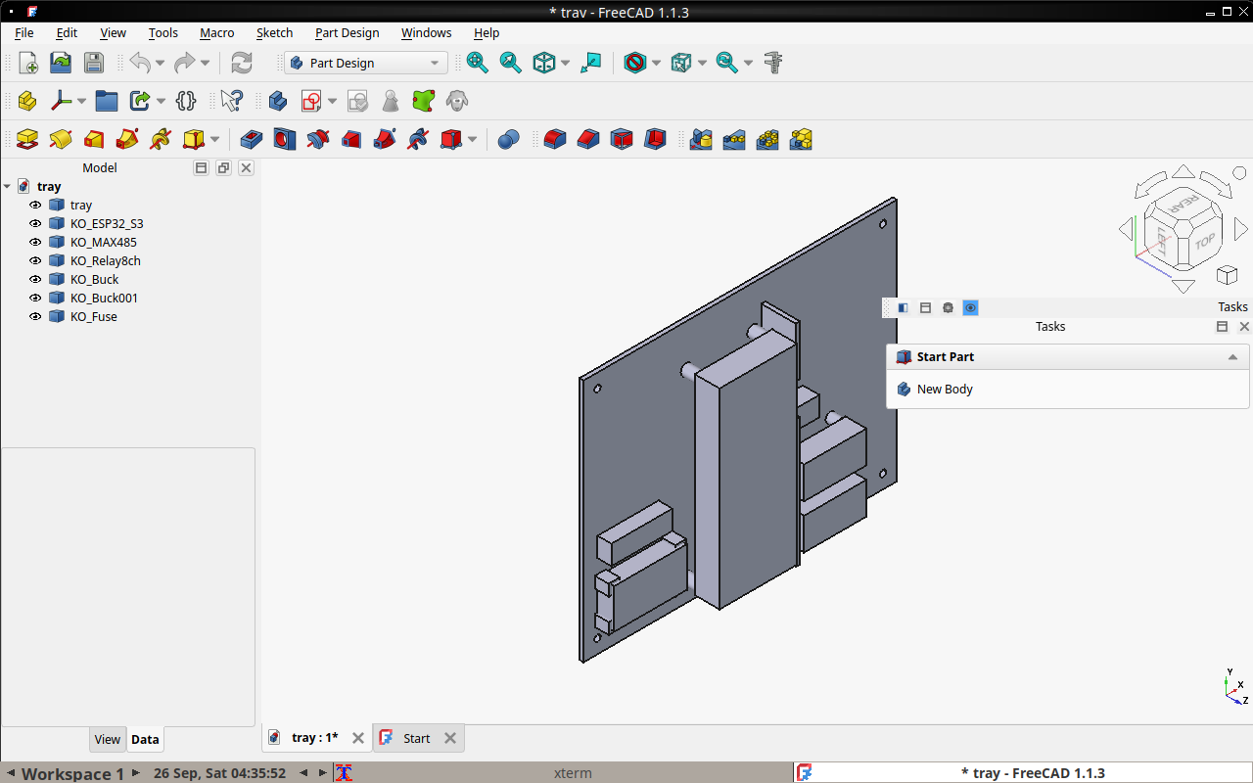
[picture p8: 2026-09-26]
enclosure/cad/tray-isometric.png

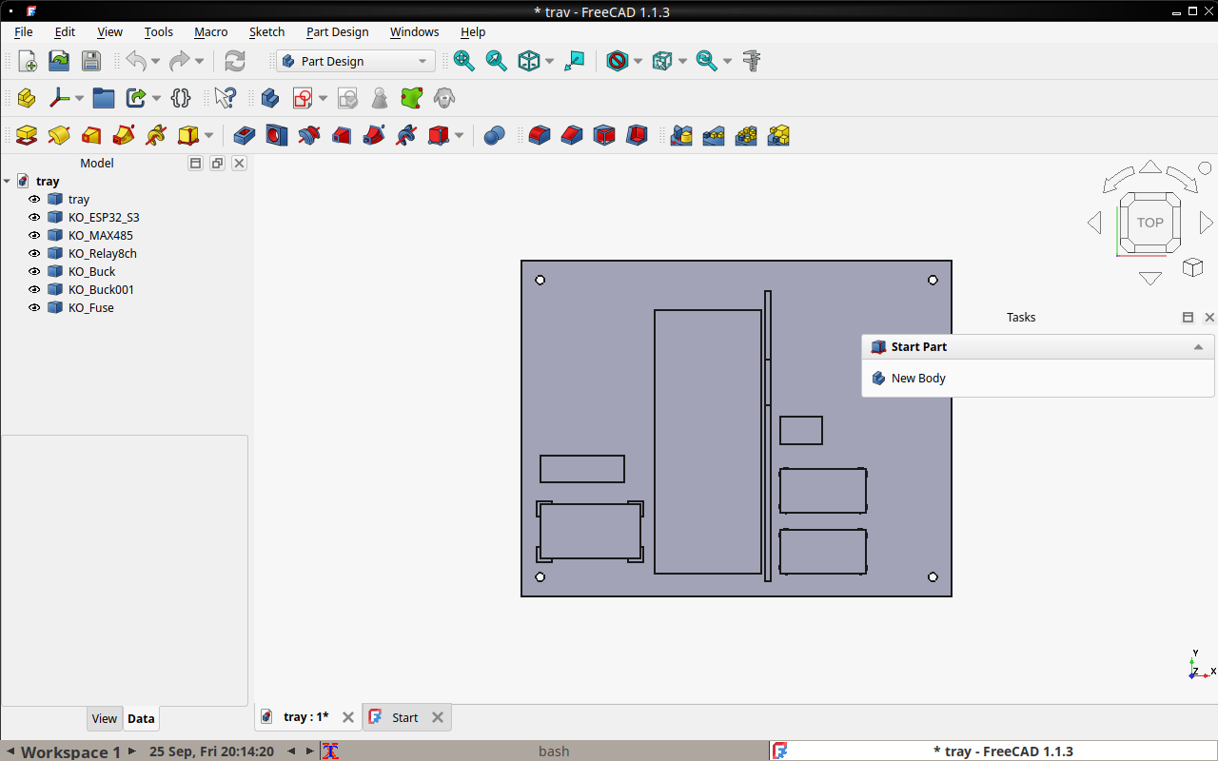
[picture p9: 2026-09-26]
enclosure/cad/tray-top-view.png

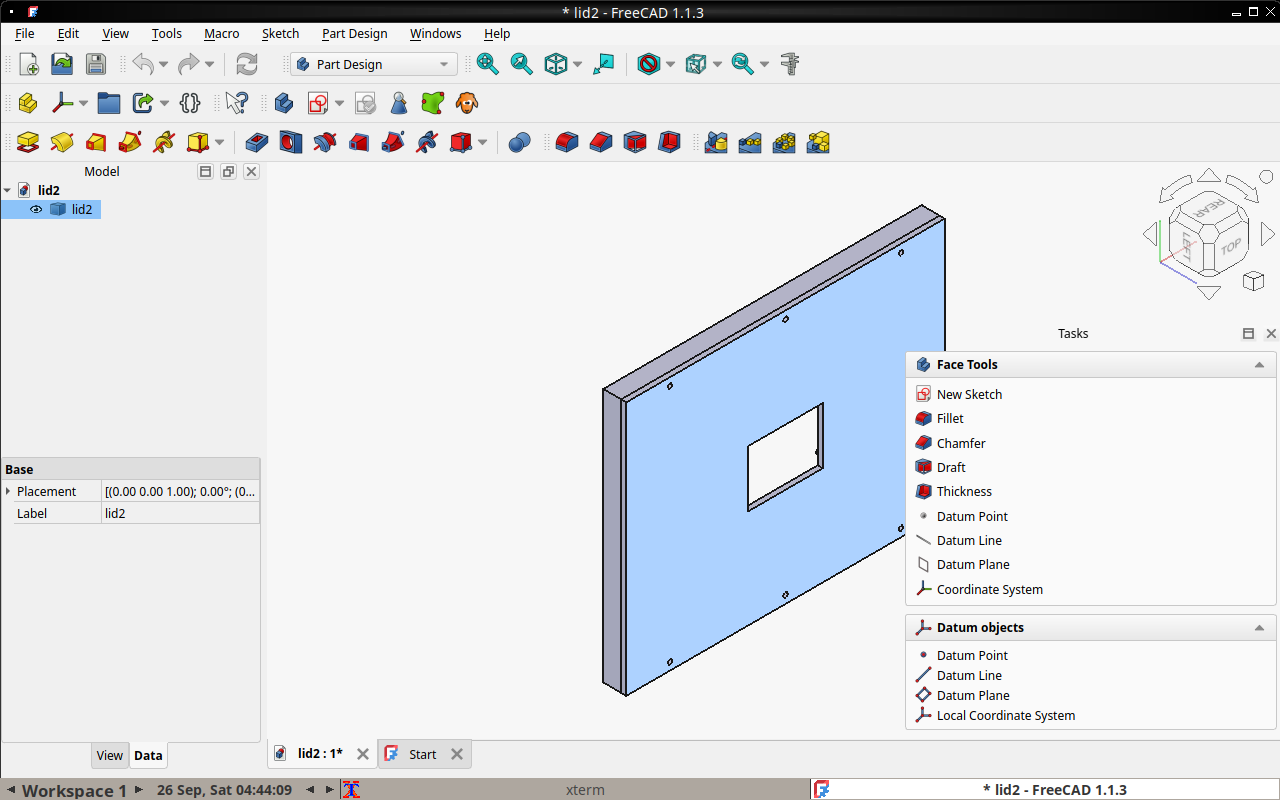
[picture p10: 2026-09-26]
enclosure/cad/lid2-top.png

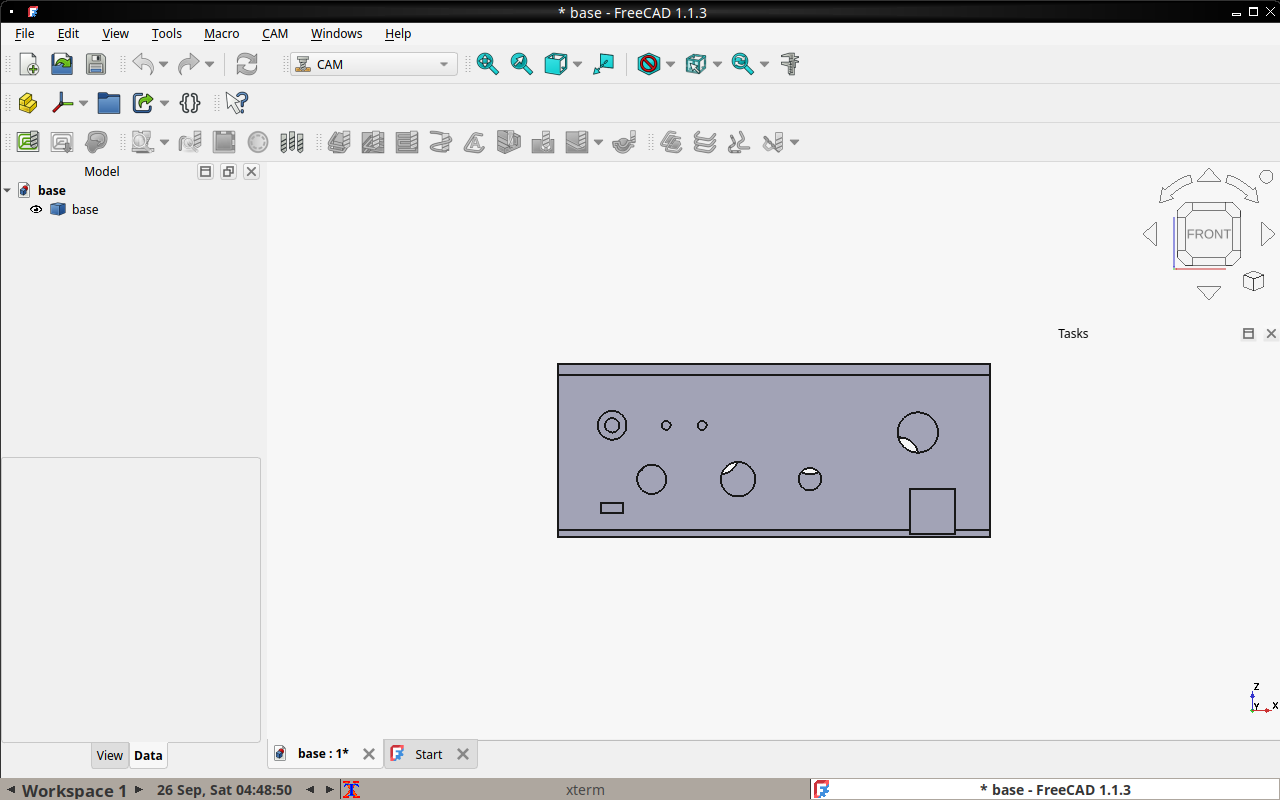
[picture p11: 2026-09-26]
enclosure/cad/front-panel.png

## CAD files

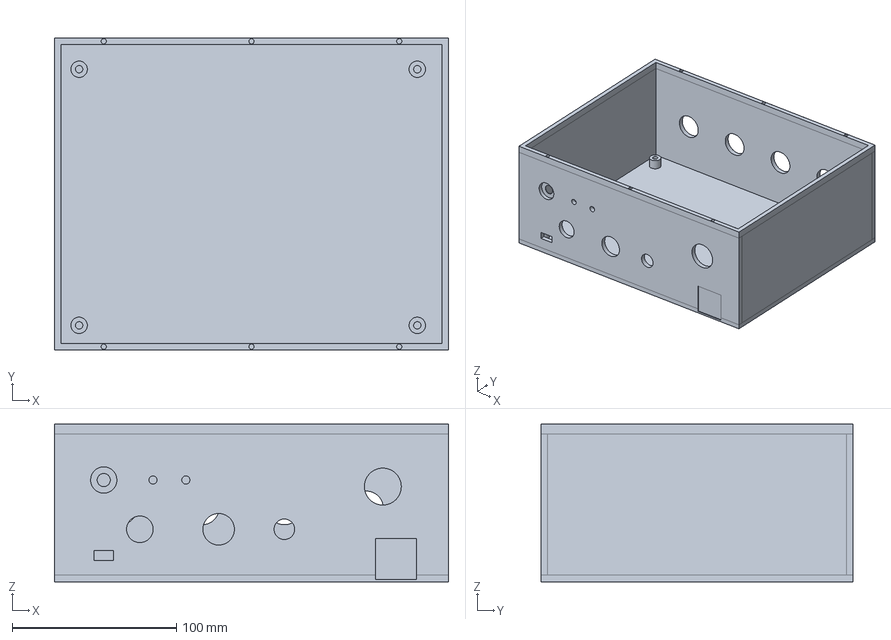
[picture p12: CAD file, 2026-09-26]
enclosure/cad/base.FCStd
240.0 x 190.0 x 96.0 mm

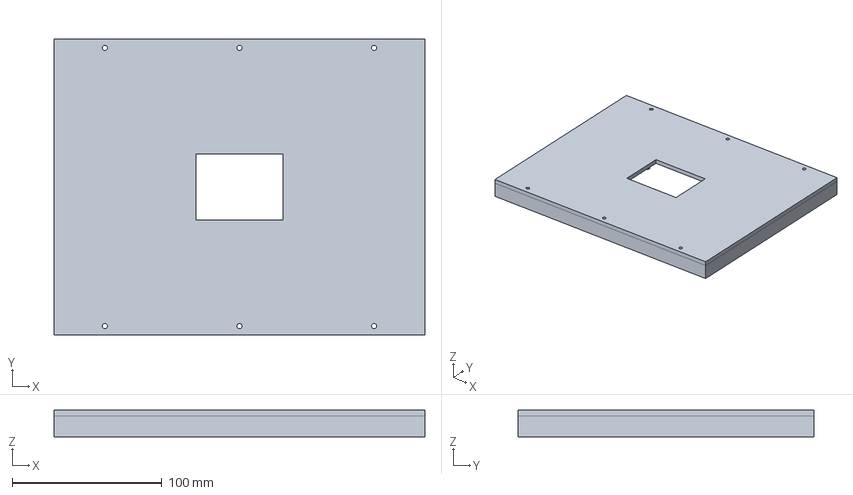
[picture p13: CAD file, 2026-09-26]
enclosure/cad/lid2.FCStd
248.0 x 198.0 x 18.0 mm

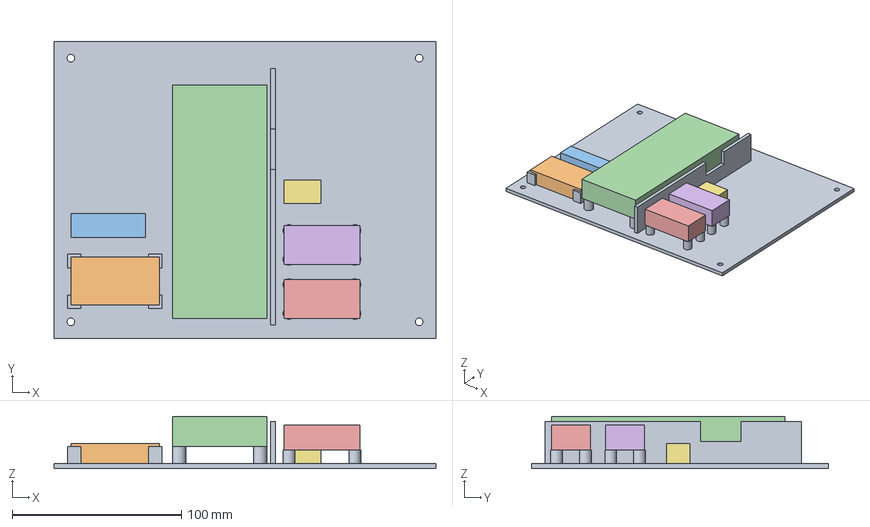
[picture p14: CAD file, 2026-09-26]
enclosure/cad/tray.FCStd
226.0 x 176.0 x 31.0 mm
tray
KO_ESP32_S3
KO_MAX485
KO_Relay8ch
KO_Buck
KO_Buck001
KO_Fuse

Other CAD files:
enclosure/cad/base.stl
enclosure/cad/lid2.stl
enclosure/cad/tray.stl

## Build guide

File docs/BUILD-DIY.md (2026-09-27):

# Build guide: generic ESP32-S3 DIY

Build the tester from discrete modules on a bench: ESP32-S3 board, MAX485
transceiver, 8-channel relay module, LEDs, and a button. Follow every step
in order — a beginner with the parts list below reaches a working tester.

What the finished box does: it impersonates a JBD / Xiaoxiang smart BMS
over RS485, so an e-rickshaw meter or display can be tested without a
battery pack. An 8-relay sequencer switches the meter's own functions in
order, and a web dashboard (always-on Wi-Fi AP `BMS-Tester`) controls
everything.

## 1. Shopping list

| # | Part | Spec | Notes |
|---|---|---|---|
| 1 | ESP32-S3 DevKitC-1 | 8 MB flash | The standard build target. **Or** an ESP32-S3 N16R8 board (16 MB flash + 8 MB OPI PSRAM) — use the `s3-n16r8` firmware env |
| 2 | MAX485 module (or SP3485) | 3.3 V logic | Half-duplex RS485 transceiver with DE/RE pins broken out |
| 3 | 8-channel relay module | 12 V coils, SmartElex-style, optoisolated inputs, ESP 3.3 V compatible | Default active-LOW (LOW = ON); check the module's jumper |
| 4 | Green LED + red LED | 3–5 mm | Link status indicators |
| 5 | 2 × 220 Ω resistors | 1/4 W | LED current limit (~8 mA) |
| 6 | 1 × 10 kΩ resistor | 1/4 W | Pull-down on the RS485 direction pin — **do not skip** |
| 7 | Push button | Momentary, normally open | START/STOP + factory reset |
| 8 | USB-C data cable | | Flashing + powering the ESP |
| 9 | 12 V DC supply | ≥ 1 A | **Relay coils only** — 8 × ~75 mA plus margin |
| 10 | 5 V USB charger (2 A) or power bank | | ESP + MAX485 power |
| 11 | Hookup wire, breadboard or perfboard | | |
| 12 | Twisted-pair wire | | RS485 A/B run to the meter |

Optional: an enclosure. `enclosure/` in this repo has a full IP65
standalone-box design (CAD + STL + front panel + GX16 meter-link
connector docs + 48 V power tree) if you want to box the finished bench.

## 2. Wiring

Power the ESP over USB **only after** all wiring is checked. Keep the
12 V coil supply OFF until step 2.5.

### 2.1 Relay module → ESP32-S3

| Relay module IN | ESP32-S3 GPIO | Notes |
|---|---|---|
| IN1 | GPIO5 | R1 |
| IN2 | GPIO6 | R2 |
| IN3 | GPIO7 | R3 |
| IN4 | GPIO8 | R4 |
| IN5 | GPIO9 | R5 |
| IN6 | GPIO12 | R6 |
| IN7 | GPIO13 | R7 |
| IN8 | GPIO14 | R8 |

- Relay module logic VCC → ESP 3.3 V. JD-VCC (coil power) → **separate
  12 V supply**. Tie the 12 V supply GND to the ESP GND (common ground).
- **Never power the relay coils from the ESP's 5 V pin** — USB cannot
  drive 8 coils; the ESP will brown-out and reset every time relays switch.
- Default logic is active-LOW (GPIO LOW = relay ON). If your module's
  jumper says active-HIGH, flip the **Logic dropdown** in the dashboard's
  Sequence config card instead of rewiring.
- Firmware drives the OFF level *before* setting pin modes, so no relay
  clicks at boot.
- Loads switch up to 3 A/channel (module rating). Use NO/COM/NC per
  channel to the meter functions under test.

### 2.2 MAX485 → ESP32-S3 → meter

| MAX485 pin | Connects to | Notes |
|---|---|---|
| DI | GPIO17 (ESP TX) | ESP transmits replies |
| RO | GPIO16 (ESP RX) | ESP receives meter requests |
| DE + RE (tied together) | GPIO4 (ESP) | HIGH = transmit, LOW = receive |
| VCC | ESP 3.3 V | S3 logic levels |
| GND | ESP GND | Common ground |
| A | Meter RS485 A (D+) | Twisted pair |
| B | Meter RS485 B (D-) | Twisted pair |

- **10 kΩ resistor from the DE/RE net (GPIO4) to GND.** The pin floats at
  reset; without the pull-down the MAX485 can power up transmitting and
  jam the bus. This is the single most common DIY wiring mistake.
- Firmware sequence per reply: DE HIGH → write → flush → 1.5 ms guard →
  DE LOW → drain stale RX.
- Common ground across ESP, MAX485, and meter. 120 Ω termination across
  A–B at the far end if the cable run is long.
- Protocol: 9600 8N1. The tester answers `0x03` (basic info: 52.0 V,
  0 A, 100 %), `0x04` (14 cell voltages), `0x05` (device name) and stays
  **silent on writes and unknown registers**.

### 2.3 Status LEDs

| LED | ESP32-S3 | Wiring |
|---|---|---|
| Green (link) | GPIO10 | GPIO10 → 220 Ω → LED anode, LED cathode → GND |
| Red (silent) | GPIO11 | GPIO11 → 220 Ω → LED anode, LED cathode → GND |

Driven as strict opposites in firmware — both-on / both-off (other than
unpowered) is impossible. Green = valid BMS traffic seen, red = bus
silent. On N16R8 boards the onboard WS2812 RGB (GPIO48) mirrors the same
state automatically.

### 2.4 Button and control inputs

| Input | ESP32-S3 | Wiring | Behavior |
|---|---|---|---|
| START/STOP button | GPIO15 | Button between GPIO15 and GND (internal pull-up; press = LOW) | Web-selectable behavior: hold-to-run, run-to-completion, or re-press restart. **Hold 10 s = factory reset** |
| Wi-Fi kill | GPIO18 | Jumper/switch between GPIO18 and GND | Grounded = AP off; release = AP back |
| Spoof trigger | GPIO21 (default) | Button/switch between GPIO21 and GND (internal pull-up) | Fires the 2-stage fault spoof. Pin is web-changeable: safe pins are 1, 2, 21, 38–44, 47 |

30 ms debounce on the button in firmware. All three inputs are
web-invertible if your wiring is active-HIGH.

### 2.5 Power-up order

1. 12 V coil supply OFF, USB unplugged. Double-check every row above,
   especially the 10 kΩ pull-down on GPIO4 and that relay JD-VCC goes
   to 12 V, not to the ESP.
2. Plug USB into the ESP (use a real charger, not a weak laptop port —
   the always-on AP draws ~1 W-class).
3. Switch the 12 V coil supply ON.
4. Green/red LEDs: red at boot, green ≤ 1 s after the meter starts
   polling. No relay clicks at boot.

## 3. Build environment choice

`platformio.ini` ships these environments:

| Env | Target | Dashboard | Use when |
|---|---|---|---|
| `esp32-s3-devkitc-1` | 8 MB DevKitC-1 | **FULL** (default) | Standard DIY build — this is the v2.8 release image |
| `s3-n16r8` | 16 MB + OPI PSRAM | FULL | N16R8 boards (correct flash/PSRAM map) |

FULL = everything (live SVG bench card, relay tiles + names,
meters-today, sequence config, spoof, OTA, console). OTA assets always
stay FULL so updating never strands a box. (The old CLASSIC/LITE page
variants are retired — FULL is the only dashboard.)

## 4. Flashing

### 4.1 Fast path: release image (recommended)

1. Install esptool: `pip install esptool`.
2. Download from the **v2.8** GitHub release:
   - 8 MB DevKitC-1 → `bms-tester-8mb.bin` (from `firmware/`)
   - N16R8 → `bms-tester-n16r8.bin` (from `firmware-n16r8/`)
   
   Both are merged one-file images (bootloader + partitions + app).
3. Plug the ESP32-S3 in over USB-C. Note the serial port.
4. Flash at offset `0x0`:

```sh
esptool.py --chip esp32s3 --port /dev/ttyACM0 --baud 460800 write_flash 0x0 bms-tester-8mb.bin
```

### 4.2 From source: PlatformIO

```sh
pio run -e esp32-s3-devkitc-1 -t upload   # 8 MB board
pio run -e s3-n16r8 -t upload             # N16R8 board
```

### 4.3 Arduino IDE

1. Open `arduino/bms_connection_tester/bms_connection_tester.ino`
   (all tabs open automatically).
2. Board: **ESP32S3 Dev Module**, **USB CDC On Boot: Enabled**, upload
   speed 921600.
3. N16R8 also needs: Flash Size 16 MB + PSRAM OPI.

### 4.4 Verify the flash

Run the host test suite (no hardware needed):

```sh
sh run_tests.sh
```

All suites green means the firmware logic is sound; wiring is then the
only remaining variable.

## 5. First boot and dashboard tour

1. On your phone or laptop, join the Wi-Fi network **`BMS-Tester`**
   (open network, always broadcasting). A captive-portal popup may
   appear — open the dashboard in the real browser instead:
   **`http://192.168.4.1`** (laptops can also use `bmstester.local`).
   "No internet" is normal. Turn mobile data off if the page will not load.
2. The dashboard has no login wall. Reboot, factory reset, firmware
   upload, and all saves ask for the admin password instead
   (default `admin123`).

Walk every card top to bottom:

1. **Relays** — 8 tiles showing live relay state. Click a tile to force
   that relay on/off manually. START/STOP buttons run the configured
   sequence. Cycle and actuation counters sit here.
2. **Bench (live)** — FULL-dashboard SVG strip: 48 V → bucks → ESP →
   MAX485 with TX/RX activity dots → A/B flow → live meter readout
   (`mv`/`ma`/`msoc` mirroring the last `0x03` reply, golden values or
   the active spoof stage).
3. **Meters today (approx)** — software estimate, no button needed:
   a link gap ≥ 3 s (reseat) counts a new meter once the link holds 5 s
   (fumble guard); retries with the meter plugged in do not count.
   Shows meters / attempts / pass / fail. Pass = a full cycle completed
   before the swap. **New day (reset)** zeroes the counters (no RTC on
   the box; a reboot never zeroes them).
4. **Sequence config** — mode (Sequential / Chase / All-ON), step delay
   (≥ 100 ms, default 250), hold time, direction fwd/rev, how many of
   the 8 relays participate, loop + inter-cycle pause (500–60000 ms,
   default 2000) + cycle limit (burn-in racks), All-ON stagger (inrush
   ramp, default 50 ms), boot auto-start, **Logic** (active-LOW default;
   flip if your relay module jumpers say HIGH). Chase has a fixed 20 ms
   break-before-make. Mode switch needs IDLE; START is refused 0.5 s
   after STOP (relay settle); count-shrink acts immediately.
5. **Relay labels** — 8 editable names (e.g. "Headlamp", "Horn"),
   stored in NVS, shown on the tiles.
6. **Fault spoof (0x03 test values, stage 1 then 2)** — two fully
   editable stages: stage 1 shows realistic values first, stage 2 shows
   the fault pattern (default 88.8 V / 88.8 A / 88.8 °C / 188 %).
   Duration 1–120 s (default 10 s), then auto-reverts to golden.
   Trigger group: enable + GPIO + polarity, with a dedicated Save
   (stores without firing) — or press FIRE now. `0x04`/`0x05` never change.
7. **Firmware update** — offline `/update` file upload (Tasmota-grade
   gates: exact variant filename `firmware.bin`, `0xE9` magic +
   flash-size-vs-chip check on the first bytes, explicit sketch budget,
   one finalize — a wrong file changes nothing), OTA check cadence,
   Check now / Install, custom firmware URL (Upgrade-from-URL).
8. **Admin & Wi-Fi AP** — change the AP SSID/password/channel, change
   the **admin password** (do this first — see step 3 below), STA uplink
   section (enter office Wi-Fi credentials, **Test** joins ≤ 30 s,
   reports RSSI/IP, then drops back to AP-only; used for OTA),
   **Backup configuration** (downloads JSON; passwords never included —
   save before upgrading), **Restore** (upload a backup + admin
   password), reboot, factory reset, keep-WiFi reset, boot-counter reset.
9. **Information** — firmware version, build variant, flash size, heap,
   uptime, boot count, reset reason, RSSI, and the pin map for this build.
10. **Console** — type commands: `START STOP FIRE CANCEL DAYRESET STATUS
    UPTIME VERSION REBOOT RESET HELP`. `STATUS` replies
    `LINK GREEN seq=IDLE cyc=… act=… spoof=… met=… att=… ps=… fl=…`.
    (Over USB-serial, `STATUS?` replies `GREEN 2.8` / `RED 2.8` — test-jig
    only, not a JBD command.)

3. **Change the admin password now** (Admin & Wi-Fi AP card). The
   dashboard is open to anyone on the AP; the password gates reboot,
   reset, uploads, and saves.
4. **Run your first sequence:** Sequence config → relay count 8, step
   250 ms, hold 500 ms → START (or press the GPIO15 button). Watch the
   tiles light in order and listen for the 8 relays clicking. STOP halts.
5. **Fire your first spoof:** Fault spoof card → FIRE (or ground GPIO21).
   The meter should show the stage-1 values, then the stage-2 fault
   pattern, then revert to golden when the window expires. CANCEL aborts
   early.
6. **Read meters-today:** run a sequence, then unplug the meter's RS485
   for > 3 s and plug it back in. After the link holds 5 s, the meters
   counter increments and the completed cycle records a pass.
7. **Back up your config:** Admin card → Backup configuration, save the
   JSON somewhere safe. Restore it after any firmware upgrade.

## 6. OTA / updates

v2.8 is a single unified release line.

- The box checks GitHub `releases/latest` over the STA uplink and
  offers the update when a newer tag exists.
- It downloads only the exact-variant asset (**`firmware.bin`** for the
  8 MB build); an N16R8 or Waveshare file is refused by the filename gate.
- Manual upload (`/update`) and custom-URL OTA enforce the same gates.
- Before any upgrade, download a **Backup configuration** JSON from the
  Admin card.

## 7. Troubleshooting

| Symptom | Check |
|---|---|
| Red LED stays on, LINK pill red | Meter not polling, or A/B swapped — swap A and B first. Confirm the meter speaks 9600 8N1 JBD and is powered. The tester never initiates — it only answers |
| Red LED at boot even with meter wired | 10 kΩ pull-down on GPIO4 missing or wrong net — without it the MAX485 can power up transmitting and jam the bus |
| Relays chatter / ESP resets when relays switch | Coils powered from the ESP 5 V pin — move JD-VCC to the separate 12 V supply and common the GNDs. This is the #1 DIY failure |
| Relays work backwards | Logic dropdown in Sequence config (active-LOW vs HIGH), or the relay module's jumper |
| No relay clicks at all | IN1–8 → GPIO 5,6,7,8,9,12,13,14 in order; relay module logic VCC = 3.3 V; 12 V coil supply on and GND commoned |
| `BMS-Tester` AP not visible | GPIO18 grounded (Wi-Fi kill active)? Remove the jumper. Weak USB power — use a real charger |
| Dashboard will not load at 192.168.4.1 | Phone routing around the AP — turn mobile data off. Stay joined to `BMS-Tester` |
| No USB serial / boot loops after Arduino flash | Tools → **USB CDC On Boot: Enabled**. Re-flash with the release image to rule out a bad build |
| Upload does not start (esptool) | Hold BOOT, press/release RESET (or EN), then flash. Try another USB-C data cable |
| OTA says check failed | STA uplink not joined or no internet — run the STA Test in the Admin card and read its message line |
| Counters look wrong | Meters-today is an estimate from link gaps: a fumbly reseat needs the 5 s settle; retries without unplugging never count. Use New day (reset) at shift start |
| Everything misbehaves after a bad config | 10 s hold on the GPIO15 button = factory reset (wipes Wi-Fi/admin config, reboots). Or console `RESET` with the admin password |

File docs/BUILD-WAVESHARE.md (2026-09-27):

# Build guide: Waveshare ESP32-S3-POE-ETH-8DI-8DO

One board, no soldering of logic parts. This guide takes you from the box
to a working BMS connection tester: flashing, wiring the meter, first
sequence, first spoof, and reading the daily counters.

What the finished box does: it impersonates a JBD / Xiaoxiang smart BMS
over RS485, so an e-rickshaw meter or display can be tested without a
battery pack. An 8-channel output sequencer switches the meter's own
functions in order, and a web dashboard (always-on Wi-Fi AP `BMS-Tester`)
controls everything.

## 1. Shopping list

| # | Part | Notes |
|---|---|---|
| 1 | Waveshare **ESP32-S3-POE-ETH-8DI-8DO** | The exact board name. ESP32-S3-WROOM-1-N16R8 module: 16 MB flash, 8 MB OPI PSRAM. Has 8 digital (Darlington sink) outputs, 8 opto-isolated digital inputs, isolated RS485, and Ethernet hardware on board |
| 2 | USB-C data cable | For flashing and bench power. Must be a data cable, not charge-only |
| 3 | 5 V USB charger (2 A) or power bank | Bench power for the board |
| 4 | Twisted-pair wire for RS485 A/B | Short run to the meter; shielded twisted pair if the factory floor is noisy |
| 5 | Wire for digital outputs | 8 channels (Darlington sink outputs, 500 mA each) to the meter functions under test |
| 6 | Small push buttons / dry contacts (optional) | Only if you want physical spoof-trigger / Wi-Fi-kill switches instead of the web UI |

No separate relay module, no MAX485 module, no LEDs, no pull-down
resistors: the board integrates all of them. For permanent installs the
board also accepts DC 7–36 V on its VIN terminal (Waveshare spec); USB-C
5 V is enough for bench use.

## 2. Board tour (what the firmware uses)

| Function | Board resource | Firmware mapping |
|---|---|---|
| Outputs DO1–DO8 | TCA9554PWR I/O expander @ I2C `0x20` | SDA GPIO42, SCL GPIO41. EXIO1–EXIO8 = DO1–DO8. Output-register bit HIGH = channel ON (Darlington sink, fixed in hardware); parked OFF at boot |
| RS485 | Onboard isolated SP3485 | TX GPIO17, RX GPIO18. Direction on **GPIO21**, driven by the ESP32 UART in **RS485 half-duplex mode** (official Waveshare demo `WS_RS485.cpp` pattern) |
| START/STOP | BOOT button | GPIO0. Press = LOW. 10 s hold = factory reset |
| Spoof trigger | DI1 terminal | GPIO4, active LOW. Web-changeable to DI1–DI8 (GPIO4–11) |
| Wi-Fi kill | DI2 terminal | GPIO5, active LOW = AP off |
| Status lamp | Onboard WS2812 RGB | GPIO38. Green = link up, red = bus silent; flashes red while the TCA9554 output expander is unreachable |
| Ethernet (W5500) | SPI SCK15/MISO14/MOSI13, CS16/IRQ12/RST39 | DHCP client, hostname `bms-tester`; dashboard also answers on the Ethernet IP (`eth_ip` in /api/state). Best-effort: failure never blocks boot or Wi-Fi |
| Buzzer | GPIO46, LEDC 1 kHz/8-bit/duty 200 | Beeps on link up/down, sequencer start/stop, output-driver failure alarm. Dashboard **Buzzer** card toggle; default **OFF** — silent until enabled |
| Reserved, untouched | GPIO40 (RTC int) | — |

DI1–DI8 are opto-isolated: wire a trigger as a dry contact (or driven
signal) between the DIx terminal and COM so the GPIO is pulled LOW when
active. The dashboard's invert toggles flip the sense if your wiring
differs.

Two deliberate differences from the generic DIY build:

- **Relay polarity is fixed.** The TCA9554 stage drives HIGH-bit = ON in
  hardware, so the dashboard **Logic dropdown is disabled** (greyed out)
  on this board. Relay labels always match the coils.
- **Ethernet is integrated (best-effort).** The W5500 (SPI SCK15/MISO14/MOSI13,
  CS16/IRQ12/RST39) gets a DHCP address via ESP-IDF `esp_eth` and the
  dashboard answers on it (`eth_ip` in /api/state, `ETH ip` in the
  Information card). The always-on `BMS-Tester` Wi-Fi AP stays exactly as
  before; an Ethernet failure never blocks boot or touches Wi-Fi.

## 3. Wiring

### 3.1 RS485 to the meter

| Board terminal | Meter side |
|---|---|
| RS485 **A** | Meter RS485 A (D+) |
| RS485 **B** | Meter RS485 B (D-) |

- The transceiver is isolated, so no shared GND is strictly required.
  Keep A/B as a twisted pair.
- If the link LED stays red after wiring, **swap A and B first** — swapped
  polarity is the most common cause. Then confirm the meter is actually
  polling (the tester only answers; it never initiates).

### 3.2 Relay outputs to the meter functions

Each of the 8 relay channels exposes COM / NO / NC terminals.

| Channel | Board terminal | Wire to |
|---|---|---|
| R1 | Relay 1 COM/NO/NC | Meter function 1 |
| R2 | Relay 2 COM/NO/NC | Meter function 2 |
| R3–R8 | … | … |

- Use NO (normally open) when the function should be off at rest and
  switch on during the test; NC for the inverse.
- At boot the firmware parks all relays OFF before the expander is fully
  configured (break-before-make on mode changes), so nothing glitches.
- Relay loads: check the Waveshare spec for per-channel current rating
  and do not exceed it.

### 3.3 Digital inputs (optional physical switches)

| Function | Terminal | Wiring | Behavior |
|---|---|---|---|
| Spoof trigger | DI1 (default) | Dry contact DI1–COM, close = active | Fires the 2-stage fault spoof. Web-changeable to DI1–DI8 |
| Wi-Fi kill | DI2 | Dry contact DI2–COM, close = active | AP off while held; release to restore |

Leave DI3–DI8 unwired if unused. Everything these switches do is also
available as dashboard buttons.

## 4. Flashing

### 4.1 Fast path: release image (recommended)

1. Install esptool: `pip install esptool`.
2. Download `bms-tester-waveshare.bin` from the **v2.8** GitHub release
   (merged one-file image: bootloader + partitions + app).
3. Plug the board in over USB-C. Note the serial port (`/dev/ttyACM0` on
   Linux, `COMx` on Windows).
4. Flash at offset `0x0`:

```sh
esptool.py --chip esp32s3 --port /dev/ttyACM0 write_flash 0x0 bms-tester-waveshare.bin
```

5. If the upload does not start: hold **BOOT**, press and release
   **RESET**, then run the command again.

### 4.2 From source: PlatformIO

```sh
pio run -e s3-waveshare -t upload
```

This builds the `s3-waveshare` environment (16 MB flash map, OPI PSRAM,
`-DBOARD_WAVESHARE_8DI8RO=1`, FULL dashboard) and uploads it.

### 4.3 What you should see at boot

- RGB LED comes up **red** (bus silent, no meter frames yet).
- Within ~1 s of the meter polling, RGB turns **green** and the
  dashboard LINK pill goes green.
- All 8 relays stay OFF through boot — no clicks.

## 5. First boot and dashboard tour

1. On your phone or laptop, join the Wi-Fi network **`BMS-Tester`**
   (open network, always broadcasting). A captive-portal popup may
   appear — open the dashboard in the real browser instead:
   **`http://192.168.4.1`** (laptops can also use `bmstester.local`).
   "No internet" is normal. Turn mobile data off if the page will not load.
2. The dashboard has no login wall. Reboot, factory reset, firmware
   upload, and all saves ask for the admin password instead
   (default `admin123`).

Walk every card top to bottom:

1. **Relays** — 8 tiles showing live relay state. Click a tile to force
   that relay on/off manually. START/STOP buttons run the configured
   sequence. Cycle and actuation counters sit here.
2. **Bench (live)** — FULL-dashboard SVG strip: 48 V → bucks → ESP →
   MAX485 with TX/RX activity dots → A/B flow → live meter readout
   (`mv`/`ma`/`msoc` mirroring the last `0x03` reply, golden values or
   the active spoof stage).
3. **Meters today (approx)** — software estimate, no button needed:
   a link gap ≥ 3 s (reseat) counts a new meter once the link holds 5 s
   (fumble guard); retries with the meter plugged in do not count.
   Shows meters / attempts / pass / fail. Pass = a full cycle completed
   before the swap. **New day (reset)** zeroes the counters (no RTC on
   the box; a reboot never zeroes them).
4. **Sequence config** — mode (Sequential / Chase / All-ON), step delay
   (≥ 100 ms), hold time, direction fwd/rev, how many of the 8 relays
   participate, loop + inter-cycle pause + cycle limit (burn-in racks),
   All-ON stagger (inrush ramp), boot auto-start. The Logic dropdown is
   greyed out on this board (polarity fixed Active-HIGH). Mode switch
   needs IDLE; START is refused 0.5 s after STOP (relay settle).
5. **Relay labels** — 8 editable names (e.g. "Headlamp", "Horn"),
   stored in NVS, shown on the tiles.
6. **Fault spoof (0x03 test values, stage 1 then 2)** — two fully
   editable stages: stage 1 shows realistic values first, stage 2 shows
   the fault pattern (default 88.8 V / 88.8 A / 88.8 °C / 188 %).
   Duration 1–120 s (default 10 s), then auto-reverts to golden.
   Trigger group: enable + DI pin + polarity, with a dedicated Save
   (stores without firing) — or press FIRE now. `0x04`/`0x05` never change.
7. **Firmware update** — offline `/update` file upload (Tasmota-grade
   gates: exact variant filename `waveshare-firmware.bin`, image-head
   check, explicit sketch budget — a wrong file changes nothing), OTA
   check cadence, Check now / Install, custom firmware URL.
8. **Admin & Wi-Fi AP** — change the AP SSID/password/channel, change
   the **admin password** (do this first — see step 3 below), STA uplink
   section (enter office Wi-Fi credentials, **Test** joins ≤ 30 s,
   reports RSSI/IP, then drops back to AP-only; used for OTA),
   **Backup configuration** (downloads JSON; passwords never included —
   save before upgrading), **Restore** (upload a backup + admin
   password), reboot, factory reset, keep-WiFi reset, boot-counter reset.
9. **Information** — firmware version, board variant (`waveshare`), flash
   size, heap, uptime, boot count, reset reason, RSSI, and the pin map
   for this board.
10. **Console** — type commands: `START STOP FIRE CANCEL STATUS UPTIME
    VERSION REBOOT RESET HELP`. `STATUS` replies
    `LINK GREEN seq=IDLE cyc=… act=… spoof=… met=… att=… ps=… fl=…`.
    (Over USB-serial, `STATUS?` replies `GREEN 2.8` / `RED 2.8` — test-jig
    only, not a JBD command.)

3. **Change the admin password now** (Admin & Wi-Fi AP card). The
   dashboard is open to anyone on the AP; the password gates reboot,
   reset, uploads, and saves.
4. **Run your first sequence:** Sequence config → set relay count and
   step/hold → START (or press BOOT on the board). Watch the tiles and
   listen for the 8 relays clicking in order. STOP halts.
5. **Fire your first spoof:** Fault spoof card → FIRE (or close the DI1
   contact). The meter should show the stage-1 values, then the stage-2
   fault pattern, then revert to golden when the window expires.
   CANCEL aborts early.
6. **Read meters-today:** run a sequence, then unplug the meter's RS485
   for > 3 s and plug it back in. After the link holds 5 s, the meters
   counter increments and the completed cycle records a pass.

## 6. OTA / updates

v2.8 unifies the release line: one **v2.8** release carries both the
generic and the Waveshare assets.

- The Waveshare build checks GitHub `releases/latest` over the STA
  uplink and offers the update when a newer tag exists.
- It downloads only the exact-variant asset **`waveshare-firmware.bin`**;
  a generic `firmware.bin` is refused by the filename gate.
- Manual upload (`/update`) and custom-URL OTA enforce the same gates.
- Before any upgrade, download a **Backup configuration** JSON from the
  Admin card.

## 7. Troubleshooting

| Symptom | Check |
|---|---|
| RGB stays red, LINK pill red | Meter not polling, or A/B swapped. Swap A and B at the board terminals first. Confirm the meter speaks 9600 8N1 JBD and is powered. The tester never initiates — it only answers |
| Relays do not click | You flashed the generic build by mistake — reflash `bms-tester-waveshare.bin` (the TCA9554 expander only exists in the waveshare build). Check relay output wiring COM/NO/NC and that the load is within the channel rating |
| `BMS-Tester` AP not visible | DI2 contact closed (Wi-Fi kill active)? Open it. Weak USB power — use a real charger. Reboot the board |
| Dashboard will not load at 192.168.4.1 | Phone routing around the AP — turn mobile data off. Stay joined to `BMS-Tester` ("no internet" is normal) |
| Upload/flash does not start | Hold BOOT, press/release RESET, then flash. Try another USB-C data cable (charge-only cables fail silently) |
| OTA says check failed | STA uplink not joined or no internet — run the STA Test in the Admin card and read its message line |
| Counters look wrong | Meters-today is an estimate from link gaps: a fumbly reseat needs the 5 s settle; retries without unplugging never count. Use New day (reset) at shift start |
| Everything misbehaves after a bad config | 10 s hold on BOOT = factory reset (wipes Wi-Fi/admin config, reboots). Or console `RESET` with the admin password |

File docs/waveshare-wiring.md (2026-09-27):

# Waveshare ESP32-S3-POE-ETH-8DI-8DO — Complete Wiring & Connection Guide

Step-by-step wiring for the BMS connection tester firmware (`s3-waveshare`
build). Covers every screw terminal, what each LED means, and how to
troubleshoot the RS485 link. Board reference:
https://www.waveshare.com/wiki/ESP32-S3-POE-ETH-8DI-8DO

---

## 1. Power — pick ONE

| Option | Connector | Notes |
|---|---|---|
| USB-C | Type-C port | 5 V / 1 A. Powers the board, flashes firmware, and gives you the serial console. **Use this for bench setup.** |
| Screw terminal | `VIN` / `GND` (7–36 V) | Wide-range DC input for DIN-rail installs. Do NOT feed more than 36 V. |

Both feed the same rail — never connect both at once.

> ⚠️ **USB-OTG jumper:** when the jumper is set to **USB-OTG**, the Type-C
> port feeds the board from an external USB power supply. **Do not connect
> the board to a computer while the jumper is in the USB-OTG position.**

**PWR LED** (red, near the USB port) lights as soon as the board has power.
If it's dark, check your supply before anything else.

---

## 2. RS485 to the JBD meter — the important one

### Terminals

The board's RS485 screw terminal block is labeled (left to right):

| Board terminal | Goes to | SP3485 pin |
|---|---|---|
| **A** | Meter's **A** | Pin 6 (non-inverting) |
| **B** | Meter's **B** | Pin 7 (inverting) |
| **GND** | Meter's GND (if it has one) | — |

Wire: **A→A, B→B**. Twisted pair, keep it short on the bench (< 3 m needs
no special treatment).

### JBD meter side

On JBD/Jiabaida smart BMS units the RS485 port is usually:

- **J5** (HY2.0-4P): pin 1 = **B**, pin 2 = **A**, or
- **J1** (to RS485 adapter): green wire = **A**, yellow wire = **B**.

Match **A→A** and **B→B**. The firmware polls at **9600 baud, 8N1** —
the meter must be set to 9600 baud (JBD default).

### The 120 Ω termination jumper

Next to the RS485 terminal there is a jumper labeled **120R**. The wiki FAQ
says it explicitly: *"Please move the jumper cap to 120R and try again.
Some RS485 devices require a 120R resistor to be connected in series."*

- **Bench (short cable, 2 devices):** try **without** the jumper first.
- **No comms:** put the jumper **ON** (enables the 120 Ω terminator).
- Only one terminator per bus end — with just board + meter, one jumper on
  is correct.

### Are A and B reversed? How to tell

This is the single most common RS485 wiring fault, and the industry's
A/B labeling is genuinely confusing (even the RS-485 standard's own
naming trips up manufacturers). Symptoms of **reversed A/B**:

- **TXD LED blinks** (the board IS transmitting polls — hardware LED,
  always blinks on TX).
- **RXD LED stays dark** (the meter hears garbage and never answers).
- Web dashboard shows **no meter data**, RGB status lamp stays **red**.
- No damage — RS485 is differential and tolerant; swapping A/B cannot
  hurt either side.

**Fix:** power down, swap the two wires (A↔B) at ONE end only, power up.
If the RXD LED starts flickering and the dashboard shows voltage, you had
them reversed. There is no universal "correct" — some JBD batches and
some USB-RS485 dongles label them opposite; trust the LEDs, not the
silkscreen.

### RS485 indicator LEDs

| LED | Color | Meaning | Driven by |
|---|---|---|---|
| **TXD** | (activity) | Blinks when the board transmits on the RS485 bus | **Hardware** — tied to the UART TX line, blinks automatically on every poll the firmware sends. No firmware code needed. |
| **RXD** | (activity) | Blinks when anything arrives on the RS485 bus | **Hardware** — tied to the UART RX line, blinks on every byte received, valid or not. |

These are **pure hardware** indicators. The firmware does not (and cannot)
drive them via GPIO — they reflect raw electrical activity on the bus.

**"The RS485 lights aren't working" — checklist:**

1. **TXD never blinks:** the firmware isn't transmitting. Check the board
   booted (PWR on, RGB lamp red), and that a test is actually running
   (START pressed). At 9600 baud each poll is ~4 ms — look closely, or
   watch in a dark room.
2. **TXD blinks, RXD dark:** the meter isn't answering. Check A/B
   (swap them), 120R jumper, meter powered, meter baud = 9600.
3. **Both blink but no data:** electrical link is fine; the meter is
   answering but frames fail checksum. Check for a second device on the
   bus, or severe noise (route the pair away from relay/mains wiring).
4. **Neither ever blinks, board is alive:** hardware fault on the
   isolated RS485 section — inspect the terminal screws and the 120R
   jumper seating.

> Note: the firmware's direction control is the ESP32 UART's **RS485
> half-duplex mode** driving **GPIO21** in hardware (the official
> Waveshare 8DO demo pattern) — there is no DE/RE *screw terminal* to wire
> (unlike the generic MAX485 build, which uses GPIO4).

---

## 3. Digital outputs DO1–DO8

Eight isolated digital (Darlington sink) outputs, driven by the
**TCA9554PWR** I²C expander (address `0x20`; firmware handles it — no user
config). Each channel sinks up to **500 mA** when ON (HIGH bit = ON).

- The tester firmware sequences them DO1→DO8 during a test run
  (firmware bytes `0x01`→`0xFF` on the TCA output register).
- **Output polarity is fixed in hardware** (HIGH bit = ON). The web UI's
  "Logic" dropdown is disabled on this board — what you see is what the
  channel does.
- All channels park **OFF** at boot.
- There are **no per-channel status LEDs** on this board — watch the web
  dashboard's output indicators.

**Safety:** the outputs are isolated from the logic side (optocouplers),
but each channel sinks up to 500 mA — size the load accordingly, fuse the
load side, and switch low-voltage test loads only (the meter-tester use
case). Common the load supply's negative with the output common as the
board's DO wiring requires.

---

## 4. Digital inputs DI1–DI8

**8× optocoupler-isolated inputs.** DI1→GPIO4 … DI8→GPIO11.
Bi-directional optocoupler (NPN or PNP, either polarity). Input: 5–36 V.
**Firmware sees them as active-LOW** (`INPUT_PULLUP`, idle HIGH — same as
the official Waveshare demo `WS_DIN.cpp`): pull the DI terminal to COM to
activate.

| Terminal | GPIO | Firmware function (default) |
|---|---|---|
| **DI1** | GPIO4 | **Spoof trigger** — two-stage: 100.0 V, then 88.8 V |
| **DI2** | GPIO5 | **Wi-Fi kill** — active = AP off, release = AP back |
| **DI3** | GPIO6 | **Relay trigger** — START/STOP the 8-relay program |
| DI4–DI8 | GPIO7–GPIO11 | Free (reserved for future use) |
| **DI-COM** | — | Common for the DI terminals (**isolated** — not system GND) |

> ⚠️ **DI power requirement:** the optocouplers run on an isolated supply
> generated from the **7–36 V screw terminals**. USB-C power alone does **not**
> power the DI circuit — DIs will not respond on USB-only power.

**Wiring — dry contact (needs 7–36 V board power):**
1. Power the board via the 7–36 V screw terminals (not just USB-C).
2. Wire a pushbutton between DIx and **DI-COM** (in the DI terminal block).
3. Press → GPIO reads LOW → function triggers.

**Wiring — wet contact (works on any board power):**
1. External 5–36 V DC: (+) to DIx, (−) to DI-COM. Polarity doesn't matter.
2. Apply voltage → GPIO reads LOW → function triggers.

Do **not** use relay COM or system GND for DI wiring — DI-COM is isolated.

- The spoof input is web-changeable to any of DI1–DI8 (admin tab).
- `button_invert` / `spoof_invert` toggles flip the sense if your wiring
  is active-HIGH instead.

---

## 5. Every indicator on the board

| Indicator | Type | Meaning |
|---|---|---|
| **PWR** | Red LED, hardware | On = board powered. Dark = check supply. |
| **TXD** | Activity LED, hardware | Blinks on RS485 transmit (see §2). |
| **RXD** | Activity LED, hardware | Blinks on RS485 receive (see §2). |
| **WS2812 RGB** | Addressable LED, **GPIO38**, firmware-driven | **Red** = silent (no valid meter traffic). **Green** = link (talking to meter). This is the firmware's main status lamp. |
| BOOT / RESET | Tactile buttons | BOOT (GPIO0): press = START/STOP test; **hold 10 s = factory reset**. RESET: hardware reset. |

The **RGB lamp is the one the firmware controls**. Its truth table:

| State | Color | When |
|---|---|---|
| Boot / idle / no meter | **Red** | From the first line of `setup()`, before anything else |
| Valid JBD traffic | **Green** | After the first accepted meter frame |
| OTA update | (blue-ish progress) | During firmware upload |

> Hardware note: this board's RGB element expects **RGB byte order**
> (not the WS2812-standard GRB). The firmware compensates (swaps R/G in
> the `neopixelWrite` call) — the same workaround as Waveshare's own
> demo (`RGB_Light(r,g,b)` → `neopixelWrite(pin, g, r, b)`).

There are **no** GPIO-driven TXD/RXD LEDs and **no** per-relay LEDs —
don't go looking for GPIOs for them; they don't exist.

---

## 6. Other connectors (reference)

| Connector | Use | Firmware touches it? |
|---|---|---|
| RJ45 Ethernet (W5500) | 10/100 Mbps network | **Yes** — DHCP client, hostname `bms-tester`; dashboard also on the Ethernet IP. Best-effort: failure never blocks boot/Wi-Fi. |
| RTC battery header | PCF85063 backup cell | No |
| TF card slot | Storage | No |
| Pin header (GPIO0/1/2/3/21/43/44/45/47/48 …) | Expansion | No — free for your own hardware |
| Buzzer (GPIO46) | Audible alerts | **Yes** — LEDC 1 kHz / 8-bit / duty ≤ 200. Beeps: link up/down (short), sequencer start (200 ms) / stop (500 ms flicker), output-driver failure (5 s flickering alarm). Never driven before setup() (GPIO46 is a strapping pin). |

---

## 7. Bench bring-up — step by step

1. **Power** via USB-C. PWR LED on. RGB lamp **red** within a second.
2. **Wi-Fi:** join AP `BMS-Tester` (password `bms12345`), open
   `http://192.168.4.1` (admin password `admin123`).
3. **RS485:** wire A→A, B→B to the meter (GND if available). Leave the
   120R jumper **off** for the first try.
4. **Press BOOT** (or START in the web UI). TXD should flicker as polls
   go out.
5. **Watch RXD.** Flickering + dashboard voltage = link up, RGB turns
   **green**. Dark RXD → swap A/B at one end (§2), then try the 120R
   jumper.
6. **Relays:** the test sequence clicks R1→R8; confirm on the dashboard.
7. **Spoof:** short DI1 to COM → dashboard shows 100.0 V, then 88.8 V.
8. **Wi-Fi kill:** short DI2 to COM → AP drops; release → AP returns.

---

## 8. Quick troubleshooting

| Symptom | Likely cause | Fix |
|---|---|---|
| PWR dark | No power | Check USB-C / 7–36 V terminal |
| RGB never lights | Firmware didn't boot | Reflash; check serial console |
| RGB stuck red, TXD blinks, RXD dark | Meter not answering | Swap A/B; 120R jumper; meter power/baud |
| RGB stuck red, TXD dark | No polls sent | Start a test (BOOT / web START) |
| RXD blinks, no data on dashboard | Checksum failures | Noise on the pair; shorten cable; check termination |
| Relays don't click | TCA9554 not found | I²C bus issue — reflash; check 3V3 rail |
| AP missing | DI2 grounded | Release DI2; or factory reset (BOOT 10 s) |
| Board not detected for flashing | Not in download mode | Hold BOOT, tap RESET, release BOOT, then flash |

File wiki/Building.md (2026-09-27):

# Building (v2.8)

Two ways to get a tester on the bench. The full step-by-step guides live in
the repo docs; this page is the map.

## Option A — DIY (build it yourself)

**Guide: [`docs/BUILD-DIY.md`](../blob/main/docs/BUILD-DIY.md)** — written
from scratch for v2.8. Covers:

- Shopping list (ESP32-S3 DevKitC-1 or N16R8, MAX485 module, 8-channel
  12 V relay module, LEDs + resistors, button, 12 V supply, USB charger,
  twisted pair) with search terms.
- Bench wiring: every wire from the [[Hardware]] pin map, the 10 kΩ DE
  pull-down, 220 Ω LED resistors, separate 12 V coil supply with common
  GND, RS485 A/B twisted pair + 120 Ω termination.
- Power-up order (USB first, then 12 V), smoke-check steps, first-boot LED
  sequence (red at boot, green on first meter poll).
- Flashing the generic FULL image, then the dashboard quick-start
  (join AP → Open Dashboard → run a sequence → read the meter card).

## Option B — Waveshare ESP32-S3-POE-ETH-8DI-8DO (all-in-one)

**Guide: [`docs/BUILD-WAVESHARE.md`](../blob/main/docs/BUILD-WAVESHARE.md)**
— written from scratch for v2.8. Covers:

- What the board already gives you (8 relay outputs, isolated RS485,
  8 digital inputs, RGB) and what you still wire yourself (12 V coil
  supply, meter A/B, USB).
- Terminal map: relay outputs, DI1–DI8 screw terminals, RS485 A/B,
  BOOT button behavior (GPIO0 — don't hold it at power-on unless you want
  download mode).
- Flashing the Waveshare merged image, first-boot check (RGB red → green
  on poll), relay output test from the dashboard tiles.
- DI wiring for spoof trigger (DI1) and WiFi kill (DI2), active-LOW
  opto-isolated inputs.

## Then flash it

Both guides end at the same place: a board with firmware. If you already
have hardware and just need the binaries, skip to [[Flashing]].

After flashing, the bring-up order is: [[Hardware]] (verify wiring) →
dashboard over the AP (`192.168.4.1`) → [[Relays]] (run a sequence) →
[[Dashboard]] (every card explained).

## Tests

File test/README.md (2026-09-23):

# test/ — automated tests (152 passing: 103 via pio + 49 web via g++)

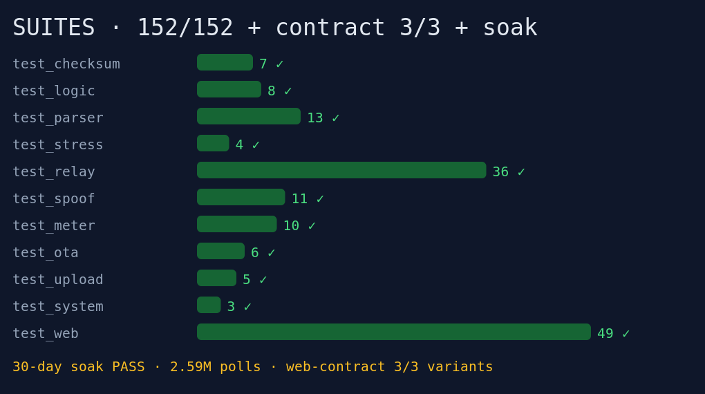
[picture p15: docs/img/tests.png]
Suite results


Each subdirectory is an independent Unity test app (PlatformIO convention),
also compilable with plain `g++` (see `run_tests.sh` fallback).
`test_web` is g++-only (needs `-DARDUINO` + host stubs in its own folder).

- `test_checksum/` (7) — checksum vectors incl. real captures (`FFFD`, `FCDA`,
  `FCA8`, `FA86`, `F65A` from `captures/SOC-DOCKLIGHT.xlsx`), golden-frame
  byte-exactness, strict matcher vs 1-byte corruptions.
- `test_logic/` (8) — adaptive green window: boot red, green on polls, red after
  silence, self-heal, slow-poll adaptation, 2 s floor / 10 s cap, rollover safety.
- `test_parser/` (13) — full-frame parser (reads/writes/split/corrupt/resync/
  overlong), dispatcher option-A silence, canned-frame checksum self-consistency,
  1 M-byte fuzz (zero false frames), fast + slow poll soaks.
- `test_stress/` (4) — exhaustive 1,785 single-byte corruptions (zero false
  frames), 10 M-byte fuzz (zero emits), cadence×register sweep, 5,000-frame
  bus saturation.
- `test_relay/` (36) — sequencer: boot OFF, sequential stepping, per-mode
  holds, ALL-ON (+ default 50 ms stagger ramp), chase wave + 20 ms
  break-before-make gaps (bitmask weight 1 lit / 0 in gap), relay count
  scoping + live shrink/regrow safety, loop/pause/limit, reverse direction,
  QC counters, all 3 button behaviors, manual override (+ force-in-chase
  idles the wave, RESTART preserves forces), post-stop start dead-band,
  mid-cycle edit latching, polarity helper, millis rollover, debounce edges.
- `test_upload/` (5) — Tasmota-grade update gates: explicit sketch budget,
  per-variant asset pick, exact-basename filename match (suffix-trap proof),
  image-head magic + flash-size-vs-chip matrix, error vocabulary coverage.
- `test_spoof/` (11) — stage-1 ("100") + stage-2 (88.8/88.8/88.8/188) frame
  bytes, checksum self-consistency, custom values, `SpoofPlan` stage
  timing/handoff/cancel/retrigger/rollover, legacy window (frozen) timing.
- `test_meter/` (10) — v2.6 link-gap heuristic: first GREEN opens meter #1,
  RESTARTs on steady GREEN never open meters, cycle+gap = pass, retry loop =
  one verdict, sub-3 s flickers stay, abort+gap = fail, day reset + boot
  restore, 200-meter day boundary, millis-wrap + 50 k-attempt soak, mid-cycle
  gap defers its close until IDLE.
- `test_ota/` (6) — version compare (incl. `2.10 > 2.9`), per-variant asset
  pick, download-URL build + tag sanitizing, auto-check gate matrix.
- `test_web/` (49, g++-only) — real `web_ui.cpp` on host stubs (`Arduino.h`,
  `WiFi.h` + STA/RSSI/IP, `WebServer.h` + request/upload drivers incl.
  pass-last order, `Preferences.h` + commit counter, `Update.h` + single-end
  + failure injection, `ESPmDNS.h`, `esp_system.h`): per-request admin
  password gating, WiFi kill switch + mDNS, portal landing (probes/CNA-UA),
  NVS v2→v3 migration, validation/clamping + named rejects (R9/R10),
  whitespace-tolerant JSON, deferred-save coalescing + reboot flush, relay
  count / chase-sweeps / spoof-pin+save+trigger / loop / labels / counters /
  STA + one-shot test + on-demand join / OTA (+install, URL, interval) /
  Tasmota `/update` upload (gates, rejects, order-independence, streamed-only
  password) / console verbs (`DAYRESET`, meter batch in `STATUS`) /
  `/api/meter` reset-only + link-gap closes over the real `web_tick` path /
  backup v2 + restore v1/v2 / keep-WiFi reset +
  bootcount / info fields, POST fuzz, factory reset, portal redirects.
- `test_system/` (3) — `select_reply()` matrix (golden/stage-1/stage-2/
  disabled/silent paths) + 24 h office-day sim: 86,400 polls, per-reply
  checksum validation, exact 5 s + 10 s spoof stages, write-silence mid-spoof,
  relay schedule + chase probes, hourly noise, green-all-day link + loop
  cycle/limit/counter proof.

Plus `tools/check_web_contract.py` — dashboard JS ↔ firmware route/key gate
(incl. dynamic `lblN` keys, `/api/ota`, `/update` form, new v2.4 endpoints,
per-mode element ids, single-`Update.end(true)` + no-`SIZE_UNKNOWN` rules).

Run: `pio test -e native` (103: all except `test_web`) or `sh ../run_tests.sh`
(full 152: g++ suites + contract + `test_web` + `test_system` + soak).

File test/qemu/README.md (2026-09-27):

# v2.8.1 Waveshare Emulation Tests

## QEMU Status (2026-09-27)

**QEMU's esp32s3 machine CANNOT execute Arduino-ESP32 firmware.** Proven:
- Espressif QEMU 9.2.2 (esp_develop_9.2.2_20260417) installed and verified
- Both the real v2.8.1 firmware AND a minimal Arduino "hello world" crash
  during Arduino core init (before `setup()`), rebooting via RTC_SW_SYS_RST
- This is a QEMU peripheral-emulation limitation, NOT a firmware bug
- The Arduino core touches hardware registers QEMU doesn't implement

## Host-Side Logic Emulation

Since QEMU cannot run the firmware, the **actual v2.8.1 source files** are
compiled on host (x86_64) with Arduino stubs:

- `src/bms_protocol.cpp` — JBD parser, checksums, PollTracker (UNMODIFIED)
- `src/relay_ctrl.cpp` — Relay sequencer, spoof frames (UNMODIFIED)
- `src/waveshare_pins.h` — GPIO assignments (UNMODIFIED)
- `apply_leds()` — EXACT v2.8.1 code from src/main.cpp:152-173 (with byte-order fix)

Stubs: `neopixelWrite()` logs args, `tca_write_reg()` logs I2C writes,
GPIO reads return simulated values.

## Results: 32/32 PASS

See `v281_emulation_results.txt` for full output.

| Test | Result |
|---|---|
| Boot LED = RED, wire [32,0,0] | PASS |
| Link LED = GREEN, wire [0,32,0] | PASS |
| JBD 0x03 request parses, reply checksum valid | PASS |
| JBD 0x04 (35B) and 0x05 (19B) replies | PASS |
| Silence on writes (0x5A) | PASS |
| Silence on unknown registers | PASS |
| Garbage (bad checksum) rejected | PASS |
| 10,000 random bytes → 0 false link triggers | PASS |
| TCA9554 init (OUTPUT=0x00, CONFIG=0x00) | PASS |
| TCA9554 relay sequence 0x01-0xFF (257 writes) | PASS |
| DI1=GPIO4, DI2=GPIO5, BOOT=GPIO0 | PASS |
| RGB=GPIO38, RS485 TX=GPIO17/RX=GPIO18 | PASS |
| I2C SDA=GPIO42, SCL=GPIO41 | PASS |
| Spoof stage 1 = 100.0V, stage 2 = 88.8V | PASS |
| Spoof checksums valid | PASS |

## Run

```sh
cd test/qemu/host
g++ -std=c++17 -I. test_v281.cpp bms_protocol.cpp relay_ctrl.cpp -o test_v281
./test_v281
```

## Limitations

- RMT/WS2812 timing: not tested (no hardware)
- WiFi RF: not tested (no hardware)  
- I2C bus electrical: not tested (QEMU has no I2C) — TCA LOGIC verified
- GPIO electrical: assignments verified, behavior not tested on silicon

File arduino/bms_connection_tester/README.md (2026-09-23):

# Flash with Arduino IDE (no PlatformIO needed)

Power and signal tree — wire this first

## 1. Install support
1. Install Arduino IDE from arduino.cc.
2. File → Preferences → Additional Boards Manager URLs, add:
   `https://espressif.github.io/arduino-esp32/package_esp32_index.json`
3. Tools → Board → Boards Manager → install **“esp32 by Espressif”**.

## 2. Open and configure
1. Open `bms_connection_tester.ino` (all tabs open automatically:
   `bms_protocol.*` responder core, `relay_ctrl.*` sequencer + spoof,
   `web_ui.*` dashboard, `ota.*` update logic, `fw_upload.h` update gates).
2. Tools → Board → **“ESP32S3 Dev Module”**.
3. Tools → USB CDC On Boot → **Enabled**.
4. Tools → Upload Speed → **921600**.
5. For N16R8 boards: Tools → Flash Size → **“16MB”**, Tools → PSRAM → **“OPI PSRAM”**.

## 3. Wire first (or at least the LEDs), then upload
- GPIO10 → 220Ω → green LED → GND ; GPIO11 → 220Ω → red LED → GND.
  Onboard RGB (GPIO48) mirrors both automatically — no wiring needed.
- GPIO17→MAX485 DI, GPIO16→MAX485 RO, GPIO4→DE+RE (+10k pull-down), 3.3V, GND, A/B→meter.
- v2.0 bench: GPIO5/6/7/8/9/12/13/14 → relay IN1–IN8 (12 V coils, own supply,
  common GND); GPIO15 → button to GND; GPIO21 → spoof trigger to GND;
  GPIO18 → WiFi-kill to GND (optional). v2.6 adds no pins.
  Join AP `BMS-Tester` (`bms12345`), open `192.168.4.1` (no login — admin
  password `admin123` only for reboot/reset/upload/saves).

## 4. Upload
Connect the S3 with a DATA USB cable, pick the COM port, press Upload.
On boot the red LED comes on; it turns green as soon as the meter polls.

## Same firmware as the PlatformIO project
This sketch is identical logic to `src/main.cpp` in the PlatformIO
project — same pins, same canned SOC100% reply, same 1-second green/red vote.
PlatformIO: `esp32-s3-devkitc-1` (8 MB, Wokwi) or `s3-n16r8` (16 MB + OPI PSRAM).

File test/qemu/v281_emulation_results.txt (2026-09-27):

=== v2.8.1 Waveshare Logic Emulation (host) ===

--- TEST 1: Boot LED (should be RED, wire [32,0,0]) ---
[LED] neopixelWrite(pin=38, r=0, g=32, b=0) -> wire [32,0,0]
PASS: Boot LED pin=38
PASS: Boot LED wire=[32,0,0] (RED)
PASS: connected=false (RED state)

--- TEST 2: Link LED (should be GREEN, wire [0,32,0]) ---
[LED] neopixelWrite(pin=38, r=32, g=0, b=0) -> wire [0,32,0]
PASS: Link LED wire=[0,32,0] (GREEN)
PASS: connected=true (GREEN state)

--- TEST 3: JBD protocol (0x03/0x04/0x05) ---
PASS: 0x03 request parses
PASS: 0x03 reply exists
PASS: 0x03 reply checksum valid
PASS: PollTracker notes valid request

--- TEST 4: Silence on writes/unknown/garbage ---
PASS: Write frame parses
PASS: Write gets NO reply (silent)
PASS: Unknown reg gets NO reply (silent)
PASS: Garbage (bad checksum) rejected

--- TEST 5: Random noise robustness ---
  10000 random bytes -> 0 parsed frames
PASS: Noise does not falsely trigger link

--- TEST 6: TCA9554 relay sequence (0x01-0xFF) ---
[TCA] write reg=0x01 val=0x00
[TCA] write reg=0x03 val=0x00
PASS: TCA init: OUTPUT=0x00
[TCA] write reg=0x01 val=0x01
[TCA] write reg=0x01 val=0x02
[TCA] write reg=0x01 val=0x03
[TCA] write reg=0x01 val=0x04
[TCA] write reg=0x01 val=0x05
[TCA] write reg=0x01 val=0x06
[TCA] write reg=0x01 val=0x07
[TCA] write reg=0x01 val=0x08
[TCA] write reg=0x01 val=0x09
[TCA] write reg=0x01 val=0x0A
[TCA] write reg=0x01 val=0x0B
[TCA] write reg=0x01 val=0x0C
[TCA] write reg=0x01 val=0x0D
[TCA] write reg=0x01 val=0x0E
[TCA] write reg=0x01 val=0x0F
[TCA] write reg=0x01 val=0x10
[TCA] write reg=0x01 val=0x11
[TCA] write reg=0x01 val=0x12
[TCA] write reg=0x01 val=0x13
[TCA] write reg=0x01 val=0x14
[TCA] write reg=0x01 val=0x15
[TCA] write reg=0x01 val=0x16
[TCA] write reg=0x01 val=0x17
[TCA] write reg=0x01 val=0x18
[TCA] write reg=0x01 val=0x19
[TCA] write reg=0x01 val=0x1A
[TCA] write reg=0x01 val=0x1B
[TCA] write reg=0x01 val=0x1C
[TCA] write reg=0x01 val=0x1D
[TCA] write reg=0x01 val=0x1E
[TCA] write reg=0x01 val=0x1F
[TCA] write reg=0x01 val=0x20
[TCA] write reg=0x01 val=0x21
[TCA] write reg=0x01 val=0x22
[TCA] write reg=0x01 val=0x23
[TCA] write reg=0x01 val=0x24
[TCA] write reg=0x01 val=0x25
[TCA] write reg=0x01 val=0x26
[TCA] write reg=0x01 val=0x27
[TCA] write reg=0x01 val=0x28
[TCA] write reg=0x01 val=0x29
[TCA] write reg=0x01 val=0x2A
[TCA] write reg=0x01 val=0x2B
[TCA] write reg=0x01 val=0x2C
[TCA] write reg=0x01 val=0x2D
[TCA] write reg=0x01 val=0x2E
[TCA] write reg=0x01 val=0x2F
[TCA] write reg=0x01 val=0x30
[TCA] write reg=0x01 val=0x31
[TCA] write reg=0x01 val=0x32
[TCA] write reg=0x01 val=0x33
[TCA] write reg=0x01 val=0x34
[TCA] write reg=0x01 val=0x35
[TCA] write reg=0x01 val=0x36
[TCA] write reg=0x01 val=0x37
[TCA] write reg=0x01 val=0x38
[TCA] write reg=0x01 val=0x39
[TCA] write reg=0x01 val=0x3A
[TCA] write reg=0x01 val=0x3B
[TCA] write reg=0x01 val=0x3C
[TCA] write reg=0x01 val=0x3D
[TCA] write reg=0x01 val=0x3E
[TCA] write reg=0x01 val=0x3F
[TCA] write reg=0x01 val=0x40
[TCA] write reg=0x01 val=0x41
[TCA] write reg=0x01 val=0x42
[TCA] write reg=0x01 val=0x43
[TCA] write reg=0x01 val=0x44
[TCA] write reg=0x01 val=0x45
[TCA] write reg=0x01 val=0x46
[TCA] write reg=0x01 val=0x47
[TCA] write reg=0x01 val=0x48
[TCA] write reg=0x01 val=0x49
[TCA] write reg=0x01 val=0x4A
[TCA] write reg=0x01 val=0x4B
[TCA] write reg=0x01 val=0x4C
[TCA] write reg=0x01 val=0x4D
[TCA] write reg=0x01 val=0x4E
[TCA] write reg=0x01 val=0x4F
[TCA] write reg=0x01 val=0x50
[TCA] write reg=0x01 val=0x51
[TCA] write reg=0x01 val=0x52
[TCA] write reg=0x01 val=0x53
[TCA] write reg=0x01 val=0x54
[TCA] write reg=0x01 val=0x55
[TCA] write reg=0x01 val=0x56
[TCA] write reg=0x01 val=0x57
[TCA] write reg=0x01 val=0x58
[TCA] write reg=0x01 val=0x59
[TCA] write reg=0x01 val=0x5A
[TCA] write reg=0x01 val=0x5B
[TCA] write reg=0x01 val=0x5C
[TCA] write reg=0x01 val=0x5D
[TCA] write reg=0x01 val=0x5E
[TCA] write reg=0x01 val=0x5F
[TCA] write reg=0x01 val=0x60
[TCA] write reg=0x01 val=0x61
[TCA] write reg=0x01 val=0x62
[TCA] write reg=0x01 val=0x63
[TCA] write reg=0x01 val=0x64
[TCA] write reg=0x01 val=0x65
[TCA] write reg=0x01 val=0x66
[TCA] write reg=0x01 val=0x67
[TCA] write reg=0x01 val=0x68
[TCA] write reg=0x01 val=0x69
[TCA] write reg=0x01 val=0x6A
[TCA] write reg=0x01 val=0x6B
[TCA] write reg=0x01 val=0x6C
[TCA] write reg=0x01 val=0x6D
[TCA] write reg=0x01 val=0x6E
[TCA] write reg=0x01 val=0x6F
[TCA] write reg=0x01 val=0x70
[TCA] write reg=0x01 val=0x71
[TCA] write reg=0x01 val=0x72
[TCA] write reg=0x01 val=0x73
[TCA] write reg=0x01 val=0x74
[TCA] write reg=0x01 val=0x75
[TCA] write reg=0x01 val=0x76
[TCA] write reg=0x01 val=0x77
[TCA] write reg=0x01 val=0x78
[TCA] write reg=0x01 val=0x79
[TCA] write reg=0x01 val=0x7A
[TCA] write reg=0x01 val=0x7B
[TCA] write reg=0x01 val=0x7C
[TCA] write reg=0x01 val=0x7D
[TCA] write reg=0x01 val=0x7E
[TCA] write reg=0x01 val=0x7F
[TCA] write reg=0x01 val=0x80
[TCA] write reg=0x01 val=0x81
[TCA] write reg=0x01 val=0x82
[TCA] write reg=0x01 val=0x83
[TCA] write reg=0x01 val=0x84
[TCA] write reg=0x01 val=0x85
[TCA] write reg=0x01 val=0x86
[TCA] write reg=0x01 val=0x87
[TCA] write reg=0x01 val=0x88
[TCA] write reg=0x01 val=0x89
[TCA] write reg=0x01 val=0x8A
[TCA] write reg=0x01 val=0x8B
[TCA] write reg=0x01 val=0x8C
[TCA] write reg=0x01 val=0x8D
[TCA] write reg=0x01 val=0x8E
[TCA] write reg=0x01 val=0x8F
[TCA] write reg=0x01 val=0x90
[TCA] write reg=0x01 val=0x91
[TCA] write reg=0x01 val=0x92
[TCA] write reg=0x01 val=0x93
[TCA] write reg=0x01 val=0x94
[TCA] write reg=0x01 val=0x95
[TCA] write reg=0x01 val=0x96
[TCA] write reg=0x01 val=0x97
[TCA] write reg=0x01 val=0x98
[TCA] write reg=0x01 val=0x99
[TCA] write reg=0x01 val=0x9A
[TCA] write reg=0x01 val=0x9B
[TCA] write reg=0x01 val=0x9C
[TCA] write reg=0x01 val=0x9D
[TCA] write reg=0x01 val=0x9E
[TCA] write reg=0x01 val=0x9F
[TCA] write reg=0x01 val=0xA0
[TCA] write reg=0x01 val=0xA1
[TCA] write reg=0x01 val=0xA2
[TCA] write reg=0x01 val=0xA3
[TCA] write reg=0x01 val=0xA4
[TCA] write reg=0x01 val=0xA5
[TCA] write reg=0x01 val=0xA6
[TCA] write reg=0x01 val=0xA7
[TCA] write reg=0x01 val=0xA8
[TCA] write reg=0x01 val=0xA9
[TCA] write reg=0x01 val=0xAA
[TCA] write reg=0x01 val=0xAB
[TCA] write reg=0x01 val=0xAC
[TCA] write reg=0x01 val=0xAD
[TCA] write reg=0x01 val=0xAE
[TCA] write reg=0x01 val=0xAF
[TCA] write reg=0x01 val=0xB0
[TCA] write reg=0x01 val=0xB1
[TCA] write reg=0x01 val=0xB2
[TCA] write reg=0x01 val=0xB3
[TCA] write reg=0x01 val=0xB4
[TCA] write reg=0x01 val=0xB5
[TCA] write reg=0x01 val=0xB6
[TCA] write reg=0x01 val=0xB7
[TCA] write reg=0x01 val=0xB8
[TCA] write reg=0x01 val=0xB9
[TCA] write reg=0x01 val=0xBA
[TCA] write reg=0x01 val=0xBB
[TCA] write reg=0x01 val=0xBC
[TCA] write reg=0x01 val=0xBD
[TCA] write reg=0x01 val=0xBE
[TCA] write reg=0x01 val=0xBF
[TCA] write reg=0x01 val=0xC0
[TCA] write reg=0x01 val=0xC1
[TCA] write reg=0x01 val=0xC2
[TCA] write reg=0x01 val=0xC3
[TCA] write reg=0x01 val=0xC4
[TCA] write reg=0x01 val=0xC5
[TCA] write reg=0x01 val=0xC6
[TCA] write reg=0x01 val=0xC7
[TCA] write reg=0x01 val=0xC8
[TCA] write reg=0x01 val=0xC9
[TCA] write reg=0x01 val=0xCA
[TCA] write reg=0x01 val=0xCB
[TCA] write reg=0x01 val=0xCC
[TCA] write reg=0x01 val=0xCD
[TCA] write reg=0x01 val=0xCE
[TCA] write reg=0x01 val=0xCF
[TCA] write reg=0x01 val=0xD0
[TCA] write reg=0x01 val=0xD1
[TCA] write reg=0x01 val=0xD2
[TCA] write reg=0x01 val=0xD3
[TCA] write reg=0x01 val=0xD4
[TCA] write reg=0x01 val=0xD5
[TCA] write reg=0x01 val=0xD6
[TCA] write reg=0x01 val=0xD7
[TCA] write reg=0x01 val=0xD8
[TCA] write reg=0x01 val=0xD9
[TCA] write reg=0x01 val=0xDA
[TCA] write reg=0x01 val=0xDB
[TCA] write reg=0x01 val=0xDC
[TCA] write reg=0x01 val=0xDD
[TCA] write reg=0x01 val=0xDE
[TCA] write reg=0x01 val=0xDF
[TCA] write reg=0x01 val=0xE0
[TCA] write reg=0x01 val=0xE1
[TCA] write reg=0x01 val=0xE2
[TCA] write reg=0x01 val=0xE3
[TCA] write reg=0x01 val=0xE4
[TCA] write reg=0x01 val=0xE5
[TCA] write reg=0x01 val=0xE6
[TCA] write reg=0x01 val=0xE7
[TCA] write reg=0x01 val=0xE8
[TCA] write reg=0x01 val=0xE9
[TCA] write reg=0x01 val=0xEA
[TCA] write reg=0x01 val=0xEB
[TCA] write reg=0x01 val=0xEC
[TCA] write reg=0x01 val=0xED
[TCA] write reg=0x01 val=0xEE
[TCA] write reg=0x01 val=0xEF
[TCA] write reg=0x01 val=0xF0
[TCA] write reg=0x01 val=0xF1
[TCA] write reg=0x01 val=0xF2
[TCA] write reg=0x01 val=0xF3
[TCA] write reg=0x01 val=0xF4
[TCA] write reg=0x01 val=0xF5
[TCA] write reg=0x01 val=0xF6
[TCA] write reg=0x01 val=0xF7
[TCA] write reg=0x01 val=0xF8
[TCA] write reg=0x01 val=0xF9
[TCA] write reg=0x01 val=0xFA
[TCA] write reg=0x01 val=0xFB
[TCA] write reg=0x01 val=0xFC
[TCA] write reg=0x01 val=0xFD
[TCA] write reg=0x01 val=0xFE
[TCA] write reg=0x01 val=0xFF
PASS: Relay sequence completed 0x01-0xFF
  Total TCA writes: 257

--- TEST 7: GPIO assignments (Waveshare) ---
PASS: DI1 (SPOOF) = GPIO4
PASS: DI2 (WIFI_KILL) = GPIO5
PASS: BOOT = GPIO0
PASS: RGB = GPIO38
PASS: RS485 TX = GPIO17
PASS: RS485 RX = GPIO18
PASS: I2C SDA = GPIO42
PASS: I2C SCL = GPIO41

--- TEST 8: 0x04/0x05 responses ---
PASS: 0x04 reply exists (35 bytes)
PASS: 0x05 reply exists (19 bytes)

--- TEST 9: DI1 Spoof (two-stage) ---
PASS: Spoof stage 1 = 100.0V (10000mV)
PASS: Spoof stage 2 = 88.8V (8880mV)
PASS: Spoof stage 1 checksum valid

--- TEST 10: OTA variant gating ---
PASS: Waveshare variant defined

--- TEST 11: DI2 WiFi kill (active LOW) ---
PASS: DI2 active LOW (ground = AP off)

--- TEST 12: BOOT button (GPIO0) ---
PASS: BOOT = GPIO0

=== RESULTS: 32 PASS, 0 FAIL ===

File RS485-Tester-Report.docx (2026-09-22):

E-Rickshaw Meter
RS485 Connection Tester

Build & Test Report v2.6 — for an electronics engineer, no coding needed

Item | Detail
Board | ESP32-S3 DevKitC-1 (or N16R8) + MAX485 module + 8-channel relay module
Version | v2.6 — answers 0x03/0x04/0x05, silent on the rest; self-adjusts to any poll speed; per-mode relay bench; 2-stage fault values + trigger save; phone-friendly portal landing; config web page + Tasmota-grade firmware updates; daily meter estimate from link gaps; round link dots; one-file flash images
Previous | v1.0 frozen untouched (ZIP + git tag) — this report covers v2.6 (meter estimate/dots/merged images on v2.5)
Date | September 2026
Firmware | bms-tester-8mb.bin — v2.6 8 MB merged image (bootloader + partitions + app, one flash command), compiled + verified (SHAs in firmware/README.md)
Tests | 152 / 152 passing + socket harness 72/72 (protocol + lamps + faults + 30-day soak + relay/BBM/dead-band/spoof-save+trigger/console/backup-v2/OTA-URL+ondemand/upload-gates/portal-landing/whitespace-JSON/meter-gaps/round-dots) + w3m page renders
Use | Green lamp = wiring correct, red lamp = wiring wrong. Button runs the relay sequence. Phone/laptop + web page configures everything.

Passwords — keep this file safe: Wi-Fi network BMS-Tester, password bms12345. Web page login: user admin, password admin123. Change both on first login (Admin card).

Send this file as-is on WhatsApp — it opens in Word / Google Docs on any phone.

# Contents

1. What this box does (start here)

2. Parts list

3. Wiring — the complete circuit (lamps + relays + button)

4. How v2.6 works (every meter type, no code)

5. Using it on the assembly line (lamps, button, web page)

6. Getting the software onto the board (3 easy methods)

7. Build & test report (numbers included)

8. Troubleshooting table

9. Safety & limits

10. Project folder map + version history

# 1. What this box does

Every e-rickshaw meter must have its two RS485 communication wires (A and B) connected correctly before it leaves the factory. This box replaces the old check (real battery pack or a laptop) with two lamps:

- GREEN lamp ON = wiring correct, meter and box are talking.
- RED lamp ON = wiring wrong (or meter off, wires swapped, wire broken).
- BUTTON = runs the 8 relays in order (each relay switches one meter function for testing). A phone/laptop web page (no office Wi-Fi needed — the box makes its own network) sets the step-by-step delay, the button behavior and test values. Details in §5.

Nothing to press, reset or read. v2.3 handles every meter variant by itself: fast or slow polling, meters that ask for extra data (cell voltages, device name), and meters that send configuration writes — green lights for all of them as long as the wires carry real traffic.

# 2. Parts list

One box needs:

Part | Qty | What it does
ESP32-S3 DevKitC-1 board (N16R8 also fine) | 1 | The brain. Listens, replies, drives lamps + relays + web page.
MAX485 module (SP3485 also fine) | 1 | Translator: ESP32 serial ↔ noise-proof RS485 signals.
Green LED + red LED (5 mm) | 1 + 1 | Link status at a glance.
220 Ω resistor | 2 | One per LED (≈ 6–10 mA).
10 kΩ resistor | 1 | Pull-down on direction pin — powers up listening, never jamming.
8-channel 12 V relay module (SmartElex type, 3 A/channel) | 1 | Switches 8 meter functions in sequence. Optoisolated inputs, ESP-compatible.
12 V DC adapter (≈ 1 A) | 1 | Relay coils ONLY — USB cannot drive them. Share GND with the ESP.
Push button (momentary, to GND) | 1 | Starts/stops the relay sequence. Hold 10 s = factory reset.
USB cable + 5 V charger / power bank | 1 | Powers ESP + MAX485. NEVER the traction battery pack.
Twisted-pair wire + screw terminals | 1 set | A/B test leads to the meter; relay wiring to meter functions.
Small plastic enclosure | 1 | Houses everything.

# 3. Wiring — the complete circuit

## 3.1 Every wire

Signal | From → To | Notes
TX data | S3 GPIO17 → MAX485 DI | Box talks out of this pin.
RX data | MAX485 RO → S3 GPIO16 | Box listens here.
Direction | S3 GPIO4 → MAX485 DE + RE tied | HIGH = talk, LOW = listen, automatic.
Failsafe | GPIO4 net → 10 kΩ → GND | Holds ‘listen’ during power-up float.
Green lamp | S3 GPIO10 → 220 Ω → green LED → GND | Long leg towards resistor.
Red lamp | S3 GPIO11 → 220 Ω → red LED → GND | Boots red until first valid poll.
Power | MAX485 VCC → 3.3 V | NOT 5 V — S3 pins are 3.3 V logic.
Ground | S3 GND = MAX485 GND = meter GND | Common ground is mandatory.
Bus | MAX485 A/B → meter A/B | Twisted pair, short run.

First check, always: if the box never turns green, swap A and B at the screw terminal and try again. Safe, instant, fixes most cases.

- Pin choices are S3-safe (avoid strapping 0/3/45/46, USB 19/20, flash 26–37, console 43/44). Unchanged from v1.0 — a v1.0-wired box runs v2.3 firmware; only new wires are relays/button below.

## 3.2 Relay bench wiring (v2.x additions)

Signal | From → To | Notes
Relays 1–8 | S3 GPIO5/6/7/8/9/12/13/14 → relay IN1–IN8 | One wire per channel, in order.
Relay logic | Idle HIGH, relay clicks ON when pulled LOW | Confirmed on bench — boots OFF with no click. A web setting flips it if a module ever needs HIGH.
Relay power | 12 V adapter → module DC+/DC− | Coils ≈ 30 mA each (≈ 240 mA all-on). USB cannot do this.
Relay ground | 12 V GND = ESP GND | Common reference is mandatory, optoisolation does the rest.
Relay outputs | Each COM/NO/NC → one meter function | Up to 3 A per channel. NO = closes when relay clicks.
Button | S3 GPIO15 → button → GND | Built-in pull-up; short press runs the sequence, 10 s hold wipes settings.
Spoof trigger | S3 GPIO21 → contact → GND (optional) | Or press FIRE on the web page instead.
WiFi kill | S3 GPIO18 → switch → GND (optional) | Ground it to turn the Wi-Fi off completely; release to bring it back.

12 V rule: the ESP is USB-powered, the relay coils are 12 V-powered, and their grounds are tied together. Relays will never click without the 12 V adapter.

# 4. How v2.6 works (the idea, no code)

1. The meter asks questions in the JBD battery language at 9600 baud — usually register 0x03 (voltage/current/charge), sometimes 0x04 (cell voltages) or 0x05 (device name), occasionally configuration writes.
2. The box checks every incoming message completely (start, command, length, safety checksum, end byte). Random factory noise can never fake one — proven with a million random bytes in testing.
3. Known questions get the matching canned answer (0x03 is the byte-exact recording of a real full battery: 52.0 V, 100 %; 0x04/0x05 are consistent synthesized answers). Writes and unknown questions get silence — but they still count as ‘the meter is talking’, so green still lights. Deliberate choice: a tester must never confuse a meter with a wrong answer.
4. Green/red is now self-adjusting: the box measures the meter's poll rhythm and sets its patience between 2 and 10 seconds. Fast meters, slow meters, jittery meters — all show steady green; a truly silent line always goes red. No configuration, no buttons, forever.
5. Relays: one button press switches the first N relays in order with an adjustable pause between clicks (default half a second), holds each mode for its own time in milliseconds, then releases — or switches them all at once, or sweeps a single lit relay (chase wave, both directions). Three button styles are selectable: hold-then-auto-off with re-press abort, run-to-the-end ignoring presses, or re-press restarts from R1. Burn-in extras: loop the cycle with a cooling pause, stop after N cycles, stagger the all-at-once inrush, name each relay (HORN, LIGHT…), and count cycles + relay clicks for QC. The web page also toggles each relay by hand.
6. Fault test: a second input (or the web FIRE button) first shows a realistic full pack (100 V / 100 A / 100 °C / 100 %) for 5 seconds, then the over-range pattern (88.8 / 88.8 / 88.8 / 188 %) for 10 seconds — then everything returns to normal by itself. Both stages (values + seconds) are adjustable. Note: if the meter shows 100 instead of 188, that is the meter capping the display — the box provably sends 188.
7. Web dashboard: the box permanently broadcasts its own Wi-Fi network (no office internet needed). Any phone or laptop joins it and opens the control page — live relay buttons, delay/mode settings, fault-test values, firmware updates. No login: the admin password (default admin123) is asked only for reboot, reset, upload and saves. The page header shows two round link dots (green/red) mirroring the lamps. All settings survive power cuts.
8. Firmware updates: two ways. Offline: flash the ONE merged file (bms-tester-8mb.bin for 8 MB boards, bms-tester-n16r8.bin for N16R8) at address 0x0 — bootloader, partitions and app in a single command — or open the Firmware upload page and send the matching .bin file (works with zero internet). Automatic: enter a phone-hotspot Wi-Fi once — the box checks GitHub for new releases and installs them itself when the bench is idle.
9. Daily meter estimate: the box cannot tell meters apart on the wire (no meter ID exists), so it estimates from link gaps — a red gap of 3 seconds or more that turns green again means the worker swapped in a new meter; retries with the meter still plugged in never count. The dashboard shows meters / attempts / pass / fail (pass = a full relay cycle finished before the swap). Brief flickers never count, and a swap mid-cycle waits for idle before counting. The ‘New day’ button clears the four numbers (no clock on the box — the worker declares the day). Approximate by design, stated honestly on the page.
10. Invisible helper: over USB the box answers STATUS? with GREEN 2.6 / RED 2.6 (the number is the firmware version). Only for automatic tests.

# 5. Using it on the assembly line

## 5.1 Wiring check (lamps)

11. Power the tester from USB. Power the meter from its bench supply.
12. Connect A→A, B→B, join grounds.
13. GREEN within ~1 second = PASS. RED = swap A/B first, then continuity and ground.
14. Next meter. Works for any meter variant or poll speed.

## 5.2 Relay bench (button)

15. Power the 12 V adapter for the relay coils (relays never click without it).
16. Short press the button: relays click R1→R8 in order (or all at once, per setting).
17. Re-press behavior follows the selected style: abort-to-OFF, ignored-till-done, or restart-from-R1.
18. Each relay output switches one meter function under test — watch the meter respond per channel.

## 5.3 Web dashboard (phone/laptop, no office Wi-Fi needed)

19. On the phone/laptop, join Wi-Fi network BMS-Tester with password bms12345. A login page pops up by itself; if not, open 192.168.4.1 in the browser.
20. Phone says ‘no internet’ or keeps using mobile data? Turn mobile data OFF (or tap ‘stay connected’) — the box has no internet, it IS the network.
21. No login page — the dashboard opens directly. The admin password (default admin123) is asked only for reboot, reset, upload and saves.
22. FIRST: open the Admin card and change the Wi-Fi password and the admin password. (Locked out later? Hold the box button 10 s — factory reset, back to the passwords above.)
23. Top of the page: two round dots (green/red) mirror the lamps, next to the LINK pill.
24. Relays card: live green tiles = ON; tap any tile to force it; START runs the sequence, STOP ALL releases everything.
25. Meters card (v2.6): meters / attempts / pass / fail for the day — an estimate from link gaps, no button to press. ‘New day (reset)’ clears the four numbers (it asks first).
26. Sequence card: mode (1-by-1, chase wave, or all-at-once), how many relays (1–8), step pause in ms, hold time per mode in ms (0 = stay on), loop + cooling pause + cycle limit for burn-in, all-at-once stagger, direction, button style, relay logic. Save stores it through power cuts.
27. Relay labels card: give each relay a name (HORN, LIGHT…) — workers see names, not R-numbers.
28. Fault card: stage 1 (100s) and stage 2 (88.8/188) values + seconds each, press FIRE — the meter shows stage 1, then stage 2, then returns to normal by itself.
29. Firmware card: tick auto-check and enter a hotspot Wi-Fi once for automatic updates; or open the Firmware upload page and send a .bin file (no internet needed).
30. Admin card: Wi-Fi + login passwords, auto-start on boot (burn-in), reboot, factory reset.

Keep safe: this document carries the live passwords (BMS-Tester / bms12345, admin / admin123). Change them on first login and re-share only the new ones.

# 6. Getting the software onto the board

Pick ONE method, once per board. Wiring is identical for all.

## Method A — ready binaries + esptool (fastest, no IDE)

31. On any PC: pip install esptool
32. Plug in the S3 (DATA cable), find the port.
33. Run (replace PORT and pick ONE file for the board — 8 MB vs N16R8): esptool.py --chip esp32s3 --port PORT --baud 460800 write-flash 0x0 bms-tester-8mb.bin (files in firmware/ and firmware-n16r8/)
34. Unplug, fit in the box. Boots red, green on first poll.

No-install alternative: a browser flasher (e.g. espthings.io/tools/esp32-flasher) with the same single file at 0x0. Advanced: the folders also carry bootloader.bin + partitions.bin + firmware.bin for the classic three-address flash (0x0 / 0x8000 / 0x10000).

## Method B — PlatformIO (exact project)

35. VS Code + ‘PlatformIO IDE’ extension. File → Open Folder → bms-connection-tester.
36. Click → Upload for esp32-s3-devkitc-1. ‘SUCCESS’ = done.

## Method C — Arduino IDE

37. Boards Manager → ‘esp32 by Espressif’. Open arduino/bms_connection_tester/bms_connection_tester.ino (all tabs open automatically).
38. Board ‘ESP32S3 Dev Module’, USB CDC On Boot = Enabled, Upload Speed 921600 (N16R8 boards also: Flash 16MB, PSRAM OPI). Pick port, Upload.

# 7. Build & test report

## 7.1 Firmware compiled for real — SUCCESS

Built with the genuine Espressif Xtensa GCC 8.4.0 toolchain (PlatformIO + Arduino framework): both S3 profiles compiled SUCCESS (8 MB + N16R8). Binary inspected afterward:

Artifact | Detail
bms-tester-8mb.bin | v2.6 8 MB merged image — bootloader + partitions + app in ONE file (flash to 0x0): three canned replies (0x03/0x04/0x05) plus STATUS?, per-mode relay bench, AP dashboard + console, 2-stage spoof + trigger save, phone landing page, Tasmota-grade OTA, meter estimate + round dots; SHAs in firmware/README.md.
SHA-256 (merged image) | ba08f166fbdcaa40fbd8391479a3cf7687f3154eefeef8c7fae1bec31d8727b9 (1,070,800 bytes; bootloader E9 @0x0, partition magic @0x8000, app E9 @0x10000 verified)
SHA-256 (firmware.bin) | 4dc08487668ff9c37e15cc0bdc0c0bf24d19c8da32e3c1f0dd9516b1d313bbf9 (1,005,264 bytes; golden bytes + 2.6 + BMS-Tester verified inside)
N16R8 image | firmware-n16r8/bms-tester-n16r8.bin — same logic, 16 MB map (847f6c94…2c9ae3875e08db82842, 1,073,328 bytes).
bootloader + partitions | Standard S3 loader and flash layout, refreshed with this build.
On-target test builds | All unit-test programs also compile + link for the S3 chip (they execute once a board is plugged in).
QEMU S3 boot test | Parked at v2.4: Stage-0 flash model clean (GD WRSR2-QE + burst-wrap fixes banked), guest resets in the 2nd-stage bootloader (init returns 0x0a) — emulator gap, not firmware. Wokwi S3 + virtual-bus PTY emulation are the practical paths.

## 7.2 Automated tests — 152 / 152 PASS (run_tests.sh) + socket harness 72/72

Group | Tests | Result
Checksums + golden frame (7) | FFFD / FCDA / FCA8 / FA86 / F65A (2nd Docklight 0x2A variant), byte-exact 0x03 frame, exact-yes / 7xcorrupt-no. | 7 PASS
Lamp logic, adaptive (8) | Boot red, green fast, red after window, self-heal, slow-poll adapt, 2 s floor / 10 s cap, rollover, legacy compat. | 8 PASS
Parser + dispatcher + faults (13) | 0x03/0x04/0x05 reads, write flagged, all corruptions rejected, noise re-sync, overlong rejected, split delivery, option-A silence, canned-frame checksums, 1 M noise bytes = zero false frames, fast + slow soaks. | 13 PASS
Stress (4) | 1,785 exhaustive corruptions, 10 M fuzz, cadence×register sweep, 5,000-frame saturation. | 4 PASS
Relay bench (36) | Boot OFF, stepping, per-mode holds, ALL-ON (+ default stagger ramp), chase + 20 ms break-before-make, count live-shrink safety, loop/pause/limit, direction, counters, button behaviors, force-in-chase, RESTART keeps forces, stop dead-band, mid-cycle latching, polarity, rollover, debounce. | 36 PASS
Spoof 2-stage (11) | Stage-1 ‘100’ + stage-2 88.8/88.8/88.8/188 bytes, checksum validity, custom values, stage handoff/cancel/retrigger, rollover. | 11 PASS
OTA logic (6) | Version compare (2.10 > 2.9), per-board file pick, safe download links, idle-only auto-check gate. | 6 PASS
Website, host-executed (49) | No login wall (per-request passwords), round link dots + meters card, NVS migration, portal landing + redirect, validation + named rejects, whitespace-tolerant JSON, coalesced saves, per-mode config, spoof save/fire/trigger, Tasmota upload gates + rejects, console (+DAYRESET, meter batch in STATUS), /api/meter reset + link-gap closes over the real tick, backup v2 + restore v1/v2, STA test + on-demand join, OTA URL/interval/install, mDNS, keep-WiFi/bootcount resets, info fields, fuzz, factory reset. | 49 PASS
Socket harness, real HTTP (62+10) | drive_emu.py: portal, relay flows, spoof/trigger, uploads, backup/restore, console, resets, STA/OTA, info, meter gaps + round dots (new /__bus bus-state control) — over the real handlers. drive_soak.py: 48 virtual hours looped, counters exact, NVS coalescing, spoof mid-run, clean stop. | 72 PASS
Meter heuristic (10) | First GREEN opens #1, RESTARTs never open meters, cycle+gap = pass, retry loop = one verdict, flickers stay, abort+gap = fail, day reset + boot restore, 200-meter day boundary, millis-wrap + 50 k soak, mid-cycle gap defers to IDLE. | 10 PASS
Month soak (pure logic) | 30 virtual days from day 40 across the millis() wrap: 2.59 M polls answered, 309 k looped cycles, exact stage/force/stop behavior, 30 NVS commits, silence → red → green, no reset. | SOAK PASS
Update gates (5) | Explicit sketch budget, variant asset pick, exact filename match (suffix-trap proof), image-head magic + flash-size matrix, error vocabulary. | 5 PASS
System 24 h sim (3) | Reply-selection matrix + 86,400-poll office day: every reply checksum-validated, exact 5 s + 10 s spoof stages, relay + chase schedule, loop cycles, noise, green all day. | 3 PASS

The hardware-in-loop test (real board + adapter asserting exact replies and GREEN→RED timing) runs itself the moment hardware is detected; until then it skips. The virtual meter gained scenario modes (--reg, --period, --jitter, --mode normal/slowstop/noise/write/unknown) for bench testing.

## 7.3 Month-long continuous run — SOAK PASS

tools/soak_sim.cpp drives the real firmware logic through 30 simulated days: 2,591,400 polls answered, 309,625 looped cycles, silence gaps correctly red, the 32-bit millis() rollover crossed mid-run, 30 NVS commits, and green-on-resume with no reset. Runs in under a second as part of run_tests.sh.

## 7.4 Testing caught real bugs (proof the suite works)

- 1) The new parser emitted a frame when a corrupted checksum was followed by 0x77 — fixed by gating emission on checksum success, now covered by test. 2) A hand-written test vector had a wrong checksum (FEEF, not FEFF) — fixed. 3) Arduino's headers define a B1 macro that broke the parser's state names on S3 builds — renamed, S3 build green.
- 4) Retired login wall (v2.3.1): per-request admin password now gates reboot/reset/upload/OTA-admin; the dashboard is open on the WPA2 AP. 5) A stray semicolon ended the dashboard status builder early and dropped the fault-test values from the web reply (2 web tests caught it before release). 6) GitHub OTA check never matched (API pretty-prints a space after the colon) + no dashboard install path (host reasoning + new web tests; fixed with tolerant parse + Install button).
- Carried-over v1.0 finding: reply checksums exclude the echoed command byte (FCDA, not FCD7) — so all canned replies are frozen literals, never recomputed at runtime.
- 7) v2.6 meter work: the first day-reset design read 0 all day until the first reseat (a seated unit now re-opens as #1 at once, empty bench stays 0); a boot must forget link edges or NVS totals double-count (begin() is total amnesia, totals overlay after); the emulator's STA-link switch never touched the bus LEDs, so the meter tests drove nothing until the dedicated /__bus control existed. All three are now covered by tests.

# 8. Troubleshooting

Symptom | Fix (in order)
Always RED | 1) Swap A/B. 2) Common GND. 3) Meter powered + polling. 4) MAX485 VCC = 3.3 V.
GREEN flickers | Loose terminal / long untwisted run. Shorten, twist; 120 Ω across A–B if long.
Both LEDs dark | Unpowered, LEDs backwards (flat side to GND), or 220 Ω forgotten.
Answers once then stops | GPIO4/DE-RE fault (stuck TX jams bus). Check GPIO4 + 10 kΩ pull-down.
Relays never click | 1) 12 V adapter plugged + LED on module lit. 2) 12 V GND tied to ESP GND. 3) Web page → relay logic matches module (default LOW). 4) Relays card: relays past the count are greyed out — raise Relays.
Relay clicks at power-on | Wrong logic setting — flip relay logic on the web page and Save.
Relays stay ON forever | Normal if a hold is 0 (= stay on until STOP). Set per-mode hold ms (sequence / chase / all-on) to the wanted time.
188 % shows 100 | The meter caps the display — the box provably sends 188 (valid checksum). Use stage 1 (100) for a realistic demo.
Phone cannot see BMS-Tester | Box fully booted? (takes ~5 s with Wi-Fi). Forget + rejoin; confirm a DATA USB cable powers it.
Web page won't open | Joined BMS-Tester (not office Wi-Fi)? Open 192.168.4.1 exactly.
Login rejected | Changed earlier? Ask who changed it. Else hold the box button 10 s (factory reset) → admin123 back. (There is no login page — the password is asked only for reboot/reset/upload/saves.)
Meter count looks off | It is an estimate from link gaps, not a per-unit ID: a swap needs 3+ s of red before green returns; quick unplug-replug stays on the same meter. ‘New day (reset)’ clears the four numbers.
PC cannot see S3 | DATA cable first, then CP210x/CH343 driver; pick the USB-UART port.
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

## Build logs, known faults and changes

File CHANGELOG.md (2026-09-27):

# Changelog

All notable changes to this project are documented here.
The format is based on [Keep a Changelog](https://keepachangelog.com/en/1.0.0/).
Every release ships Tasmota-style one-file images (`bms-tester-8mb.bin`,
plus `bms-tester-n16r8.bin` from v1.2 on): `write-flash 0x0 <file>`.

## [v2.9.2] — 2026-09-27
### Added
- Waveshare buzzer toggle in the web UI: a **Buzzer** card (checkbox + Save)
  on the dashboard, NVS-persisted (`buzz` key, default **OFF** — the board
  stays silent until explicitly enabled). `buzzer_beep()` now gates on
  `ws_buzzer_gate(buzzer_ready, cfg.buzzer_enabled)`; `/api/state` reports
  `"buzzer":"1"/"0"` on Waveshare builds. The card hides itself on generic
  builds (no buzzer hardware).
### Removed
- Classic/lite dashboard variants retired: `[env:s3-classic]` and
  `[env:s3-lite]` deleted from `platformio.ini`, the `WEB_UI_VARIANT`
  machinery removed from `src/web_ui.cpp` — FULL is the only dashboard.
  `tools/check_web_contract.py` now validates the single FULL page. OTA
  assets were already FULL-only; unchanged.
### Verified
- 184/184 native Unity tests (0 failures), WEB-CONTRACT PASS, 30-day soak
  PASS (2,591,400 polls, rollover crossed, no reset), `pio run`
  -e esp32-s3-devkitc-1 and -e s3-waveshare both SUCCESS.

## [v2.9.0] — 2026-09-27
### Added (Waveshare ESP32-S3-POE-ETH-8DI-8DO — full 8DO support)
- W5500 Ethernet via ESP-IDF `esp_eth` (`src/ws_eth.cpp`): the installed
  Arduino core is 2.0.17, whose Arduino-ETH has no W5500 support (the
  official demo needs Arduino-ESP32 ≥ 3.0), so the ESP-IDF 4.4 W5500 MAC/PHY
  drivers are bound directly with the demo's exact pinout (SPI SCK 15 /
  MISO 14 / MOSI 13, CS 16, IRQ 12, RST 39, PHY addr 1). DHCP client +
  hostname `bms-tester`; the WebServer binds all interfaces so the
  dashboard answers on the Ethernet IP with no web-code changes.
  Best-effort by design: every init step is checked, any failure just
  skips Ethernet — boot, the AP (192.168.4.1), STA, captive portal and OTA
  policy are never affected.
- Buzzer on GPIO46 (LEDC 1 kHz / 8-bit, duty ≤ 200, like the official
  demo): short beep on meter-link up/down transitions, 200 ms on sequencer
  start, 500 ms flicker on sequencer stop, one-shot 5 s flickering alarm on
  output-driver failure. Non-blocking pattern engine (`WsBuzzer`,
  host-tested) drained from loop(); never driven before setup() (GPIO46 is
  a strapping pin) and never in the RS485 hot path.
- TCA9554 fault surfacing: a latched `ok|fail` status (`WsTcaFault`,
  host-tested) — `/api/state` now reports `"expander":"ok"|"fail"`, the RGB
  flashes red while the expander is unreachable (demo DoutFailTask pattern),
  and the failure raises the one-shot buzzer alarm. Safe-boot park 0x00 and
  write-retry semantics unchanged; any later successful write self-heals
  the status back to `ok`.
- `/api/state` now includes `"eth_ip":"<addr>"` when Ethernet is up (empty
  string otherwise); the dashboard Information card shows `ETH ip` next to
  the existing STA IP in all dashboard variants.
### Changed
- Routing note: with WiFi STA and Ethernet both up, outbound traffic (OTA
  check/download) follows lwIP's default interface (most recently
  connected). The STA-online gate for OTA checks is unchanged — Ethernet is
  an extra management path, not an OTA-policy change.
### Docs
- `docs/waveshare-wiring.md`: USB-OTG jumper warning (do not connect the
  board to a computer while the jumper is set to USB-OTG — the jumper feeds
  external power through Type-C).
### Verified
- 182/182 native Unity tests (7+8+14+4+36+11+12+6+5+52+3+24, 0 failures),
  incl. 11 new v2.9.0 tests: W5500 pinout, buzzer constants/pattern
  engine (solid/flicker/sub-50-solid/FIFO/full-drop), TCA fault latch
  (edge + self-heal), `expander`/`eth_ip` in /api/state (present + omitted
  on generic), dashboard ETH ip row. `pio run -e s3-waveshare` and
  `-e esp32-s3-devkitc-1` both SUCCESS. 30-day soak: 2,591,400
  polls/replies, millis rollover crossed, no reset needed (PASS).

## [v2.8.10] — 2026-09-27
### Fixed
- Waveshare 8DO alignment to the official ESP32-S3-POE-ETH-8DI-8DO demo:
  RS485 direction now goes through the UART's hardware RTS half-duplex mode
  (`setMode(UART_MODE_RS485_HALF_DUPLEX)` with GPIO21 as RTS, exactly like the
  official `WS_RS485.cpp`), replacing our manual DE bit-bang. Manual-DE
  fallback remains if hardware mode init fails (`rs485_hw_de` flag).
- Doc corrections: DIs are active-LOW with INPUT_PULLUP (not active-HIGH);
  8RO → 8DO naming throughout; digital outputs documented as Darlington
  sink outputs (500 mA) instead of relay NO/COM/NC.
### Changed
- Deliberate divergence from the official demo: TCA9554 boot-parks 0x00
  (all outputs OFF — safe boot state for a test bench) instead of the
  demo's 0xFF. The register write order (OUTPUT before CONFIG) matches
  the demo exactly and is now covered by host tests (`ws_tca_init_step()`).
### Verified
- 171/171 native Unity tests (+4 new 8DO-alignment tests), 30-day soak
  (2,591,400 polls/replies), `pio run -e s3-waveshare` and
  `-e esp32-s3-devkitc-1` both SUCCESS.

## [v2.8.9] — 2026-09-27
### Fixed (CRITICAL)
- 7-byte meter request format: the real e-rickshaw meter sends
  `DD A5 03 00 FF FD 77` (7 bytes, NOT 8). Ground truth from the
  `SOC_DOCKLIGHT.xlsx` bus capture. Byte[5] (`FD`) is a ONE-byte checksum
  = `0x100 - REG` (reg 0x03 → 0xFD, 0x04 → 0xFC, 0x05 → 0xFB).
  `JbdParser::feed()` now accepts the frame via an explicit 1-byte checksum
  rule in addition to the existing 16-bit check, so the 7-byte request is
  recognized intentionally rather than by checksum coincidence.
### Verified
- Our 34-byte SOC 100% response matches the Excel capture byte-for-byte.
- All Excel TX examples (SOC 100%/50%, 90% 45C, 0x2A variants) verify
  against our checksum rule (`0x10000 - sum(bytes[2..30])`).
- New parser test: 7-byte 1-byte-checksum rule for regs 0x03–0x05.
- All native tests pass (167 Unity + 105 PIO + soak), `pio run -e s3-waveshare` SUCCESS

## [v2.8.8] — 2026-09-27
### Fixed (CRITICAL)
- Waveshare RS485 DE pin: the board DOES have a DE line on **GPIO21**.
  Our firmware wrongly assumed "hardware auto-direction (no DE pin)" based on
  the Waveshare wiki — without driving DE, the ESP32 receives nothing on the
  bus (`rs485rx` stayed empty in v2.8.7). This is why the ESP32 appeared to
  ignore the meter's polls. `send_frame()` now drives DE HIGH before TX and
  LOW after (with the existing 1.5-char guard time); `setup()` parks DE LOW
  (RX mode) at boot. A working reference sketch (`RS485_DE 21`) confirms it.
### Verified
- All native tests pass (166 Unity + 105 PIO + soak), `pio run -e s3-waveshare` SUCCESS

## [v2.8.7] — 2026-09-27
### Added
- RS485 traffic diagnostics: `/api/state` now includes `rs485rx` and `rs485tx`
  (hex strings of the last received request and last transmitted response).
  This definitively shows what the ESP32 actually sends on the bus, helping
  distinguish firmware responses from rogue traffic by other bus devices.
### Fixed
- Clarified v2.8.6's write-ACK comments: the ACK only triggers for 0x5A
  command bytes (non-standard). The meter's `DD A5 ...` requests are parsed
  as reads and correctly receive the 34-byte data response. Host simulation
  proves the firmware cannot emit anything other than the 34-byte response
  (A5) or silence (A3/unknown) — reported 6-byte `11 2D ...` traffic is not
  from this firmware.
### Verified
- All native tests pass, `pio run -e s3-waveshare` SUCCESS

## [v2.8.6] — 2026-09-27
### Added
- JBD write acknowledgment: `reply_for()` now returns a valid 6-byte JBD ACK
  (`DD <REG> 00 <CK_HI> <CK_LO> 77`) for write commands instead of silence.
  The e-rickshaw meter sends `DD A5 03...` and expects a response; the ACK
  echoes the register with status 0x00 (success) and a valid checksum.
### Verified
- 166/166 native tests, `pio run -e s3-waveshare` SUCCESS

## [v2.8.5] — 2026-09-27
### Fixed
- Waveshare DI polarity: reverted v2.8.3/v2.8.4's `INPUT_PULLDOWN`/active-HIGH
  back to `INPUT_PULLUP`/active-LOW. The DI optocouplers are NPN open-collector
  (can only pull LOW, never drive HIGH); with PULLDOWN the GPIO was stuck LOW
  forever → no edge → DI1 spoof, DI2 Wi-Fi kill, DI3 relay trigger all dead.
  Explanatory comments added at the pinMode site to prevent recurrence.
- Note: DI optocouplers need 7–36 V on the screw terminals; USB-C alone does
  not power the DI circuit.
### Verified
- 166/166 native tests, `pio run -e s3-waveshare` SUCCESS

## [v2.8] — 2026-09-27
Release scope: FULL dashboard builds only — generic ESP32-S3 (8 MB) +
Waveshare ESP32-S3-ETH-8DI-8RO, one v2.8 tag, variant assets.
### Added
- Unified release line: the Waveshare board build ships in the SAME v2.8
  release as the generic line (no more `-wsN` prereleases). Both report
  `FW_VERSION "2.8"` and both OTA-check `releases/latest`, downloading
  their own variant asset (`firmware.bin` / `waveshare-firmware.bin`).
### Fixed
- Meter counter fumble guard: a link gap ≥ 3 s now only *arms* a reseat
  candidate; the new meter commits after GREEN holds 5 s
  (`LINK_SETTLE_NEW_METER_MS`). A scratchy reseat (seat 4 s, pull, seat
  properly) no longer double-counts one unit. The closing meter's verdict
  is snapshotted at arm time, so an eager START during the settle window
  attributes to the new meter; a mid-cycle yank invalidates the test
  (previous meter closes as fail). Dashboard note updated.
### Docs
- README rewritten in depth; two from-scratch build guides
  (`docs/BUILD-DIY.md`, `docs/BUILD-WAVESHARE.md`); full wiki overhaul
  (every card, verb, pin, and API documented).
### Verified
- 166/166 native tests (`test_meter` 12/12 incl. new fumble + eager-start
  cases, `test_web` 49/49), 30-day soak PASS, both firmware profiles
  compile from scratch (`esp32-s3-devkitc-1`, `s3-waveshare`).

## [v2.7] — 2026-09-23
Release media:
[FULL](https://raw.githubusercontent.com/bm-a/bms-connection-tester/main/docs/img/dash-full.png) ·
[LITE](https://raw.githubusercontent.com/bm-a/bms-connection-tester/main/docs/img/dash-lite.png) ·
[demo GIF](https://raw.githubusercontent.com/bm-a/bms-connection-tester/main/docs/img/demo.gif) ·
[protocol](https://raw.githubusercontent.com/bm-a/bms-connection-tester/main/docs/img/protocol.png) ·
[wiring](https://raw.githubusercontent.com/bm-a/bms-connection-tester/main/docs/img/wiring.png) ·
[terminal](https://raw.githubusercontent.com/bm-a/bms-connection-tester/main/docs/img/terminal.png) ·
[suites](https://raw.githubusercontent.com/bm-a/bms-connection-tester/main/docs/img/tests.png) ·
[tiles](https://raw.githubusercontent.com/bm-a/bms-connection-tester/main/docs/img/tiles.png)
### Added
- Three dashboard variants, one per build (`WEB_UI_VARIANT` in
  `platformio.ini`; only the selected page compiles in, no flash bloat):
  **CLASSIC** (`s3-classic`, variant 0) = v2.6 page byte-verbatim;
  **FULL** (default envs, variant 1) = classic + live inline SVG bench card
  (48 V → bucks → ESP → MAX485 with TX/RX dot → A/B flow → meter readout,
  8 relay blocks glowing green, zero CDN — works on the offline AP) + tile
  glow transitions; **LITE** (`s3-lite`, variant 2) = relay tiles + names +
  LINK pill only (~4.9 KB page). Relay names stay NVS-persistent in all
  three (existing `lbl0..7` + labels card, unchanged wire path).
- Live meter readout keys in `/api/state` (read-only, never saved/restored):
  `mv`/`ma`/`msoc` (tenths + %) mirroring the last `0x03` reply — golden
  52.0 V / 0 A / 100 % or the active spoof stage — feeding the FULL bench
  SVG. Web-contract checker now validates all three page variants
  (endpoints ⊆ routes, ids per-page, union of state keys); new `test_web`
  asserts for `mv:520/ma:0/msoc:100`; all three variants proven compiling
  on host (`-DWEB_UI_VARIANT=0/1/2`).
- OTA assets unchanged (`firmware.bin` / `n16r8-firmware.bin` = FULL builds)
  so on-device updating keeps working on every box; classic/lite are
  manual-flash alternatives.
### Verified
- `pio test -e native` 103/103, `test_web` 49/49, web-contract PASS (3/3
  variants), 30-day soak PASS, OTA decision unit tests 6/6, GH release
  assets present under exact OTA names, download URL resolves HTTP 200.
  ESP-target compile + real OTA pull need hardware (toolchain uninstallable
  in this container; HIL skipped, no device).

## [v2.6] — 2026-09-22
### Added
- Daily meter-test counting, software-only estimate (no button, no new
  GPIO): `MeterBatch` (meters/attempts/pass/fail in RAM, flat NVS
  `m_met/m_att/m_ps/m_fl` flushed on close/reset only), fed from the live
  link state in `web_tick()` every loop. RED gap ≥ 3 s (`LINK_GAP_NEW_METER_MS`)
  closed by GREEN = reseat = new meter; steady GREEN across RESTARTs/retries
  = same meter; sub-3 s flickers stay on the same meter; a gap that elapses
  mid-cycle defers its close until IDLE so the in-flight verdict lands on the
  right meter. Manual New-day reset (no RTC on the box; boot persists via
  `begin()` amnesia + NVS overlay; a seated unit re-opens as meter #1; an
  empty bench stays 0 until first GREEN). Backups deliberately exclude
  counters (a restore must not resurrect yesterday's tallies). Console
  `DAYRESET` (admin-gated); `STATUS` prints the batch (`met=/att=/ps=/fl=`).
- Round link dots (green/red, `#dotG`/`#dotR`) in the dashboard header beside
  the LINK pill, driven by the same state — plus a "Meters today (approx)"
  card (live tallies + honest "estimate, no button needed" note + New-day
  reset). No `NEXT METER` button anywhere (a button version was built, then
  removed in the same release — the heuristic is the shipped behavior).
- One-file merged flash images per board (`firmware/bms-tester-8mb.bin`,
  `firmware-n16r8/bms-tester-n16r8.bin`: bootloader + partitions + app via
  `merge_bin`, structure-verified `E9`@0x0 / partition magic@0x8000 / app
  `E9`@0x10000, version + AP strings byte-present). Rolled out uniformly to
  every release v1.0–v2.5 (built from each tag's own source, old 3-file sets
  kept as the advanced path).
- `test/test_meter/` (10 Unity tests: first-GREEN opens #1, RESTARTs never
  open meters, cycle+gap = pass, retry loop = one verdict, flickers stay,
  abort+gap = fail, day reset + boot restore, 200-meter day boundary,
  millis-wrap + 50 k-attempt soak, mid-cycle gap defers to IDLE) — wired
  into the `pio test -e native` filter (now 10 suites, 103 tests).
- 5 web meter tests (link gaps driven over the real `web_tick` path, busy
  deferral, NVS persist-across-reboot, console verbs, dashboard surface incl.
  "no NEXT button" assertion) + 8 emu HTTP checks + new `/__bus` control-port
  endpoint driving the RS485 bus LEDs (the STA `__link` never touched them).
### Changed
- `FW_VERSION`/`STATUS?` → `2.6`. `/api/meter` is reset-only (`{"cmd":"reset"}`);
  `/api/state` exposes `m_met/m_att/m_ps/m_fl`; console help lists `DAYRESET`.
- `docs/CONFIG-SCHEMA.md` gains `meters.*`; `docs/MODULES.md` notes v2.6 adds
  no GPIO; `docs/PROTOCOL.md` confirms no wire change; wiki (Dashboard,
  Relays, Hardware, Flashing, Emulators, Home, Versions) + `llms.txt` +
  READMEs + `test/README.md` + `tools/README.md` + `arduino/README.md` all
  describe v2.6; `RS485-Tester-Report.docx` regenerated v2.6 (also fixes stale
  v2.5-report bits: login-page instructions dead since v2.3.1, `STATUS? 2.3`,
  8-day soak numbers, v2.4 folder map).
### Verified
- 152/152 (`run_tests.sh`: 7+8+13+4+36+11+10+6+5 Unity + contract + 49 web +
  3 system) + 30-day soak (2,591,400 polls, 309,625 cycles, wrap crossed,
  30 NVS commits) + both PIO envs SUCCESS + emu 62/62 + 48 h soak 10/10.

## [v2.5] — 2026-09-22
### Fixed
- Multipart upload auth: done handler demanded streamed field AND parsed
  arg — real servers never populate args for multipart, so every real
  upload 403'd (host stub masked it by injecting args). Streamed field
  alone now decides; security unchanged (wrong password still aborts).
- JSON helpers rejected `"key": value` whitespace (python-requests style);
  all three (`has`/`jnum`/`jstr`) share a tolerant core now (same bug class
  as the v2.3.1 OTA tag-space parse).
- Test-then-install was broken by design (one-shot STA test drops its link,
  but installs demanded a live link): check/install/URL now join with saved
  creds themselves (15 s, Tasmota-style blocking).
### Added
- Trigger group (enable + GPIO + polarity + Save-trigger; `sinv` finally
  wired end to end), captive-portal landing for phones (probes/CNA-UA get
  button + Safari steps, rest 302s to `/`), structured config schema
  (`docs/CONFIG-SCHEMA.md`, v1+v2 backups), socket emulation harness
  (`tools/fw_emu`: real handlers over real HTTP, 54 checks), 48 h
  end-to-end run (10 checks), 30-day soak (2.59 M polls, 309 k cycles,
  30 NVS commits), `docs/EMULATION-v2.5.md` per-feature report.
### Verified
- 137/137 (93 pio + 44 web) + contract + soak + virtual-bus + both PIO envs.

## [v2.4] — 2026-09-22
### Fixed
- Firmware upload rebuilt Tasmota-style (`src/fw_upload.h` gates, host-tested):
  exact variant-asset basename match (the old suffix idea would cross-flash —
  caught by its own unit test), explicit sketch budget instead of
  `UPDATE_SIZE_UNKNOWN`, `0xE9` magic + flash-size-vs-chip head gate, ONE
  `Update.end()` in the done handler (the old double-end lied about success),
  order-independent password collection, progress bar, named errors. A wrong
  file or password stages nothing and changes nothing.
- Relay review R1–R31 folded in: chase break-before-make (20 ms all-OFF gap;
  release is slower than pull-in), 500 ms post-stop start dead-band, live
  count-shrink safety, force-in-chase idles the wave, RESTART keeps forces,
  run-register snapshots (mid-cycle edits apply next cycle), timing floors
  (step ≥ 100 ms, stagger default 50, pause 500–60000 ms).
- Real firmware builds caught two host-stub lies: `Update.write` takes
  `uint8_t*` (not `char*`), and `String += char` binds the int overload
  (decimal garbage in the streamed password) — firmware appends via 1-char
  C string now.
### Changed
- Dashboard shows only the active mode's fields (per-mode menu); spoof card
  has Save-only next to FIRE; OTA check interval editable; AP/STA saves
  offer Save vs Save + reboot.
### Added
- Web console (`START STOP FIRE CANCEL STATUS UPTIME VERSION REBOOT RESET
  HELP`; hardware verbs admin-gated), config backup/restore (sectioned v2,
  passwords never exported), custom OTA URL + Upgrade-from-URL, one-shot STA
  uplink test (30 s, no reboot), Information card (variant/flash/sketch/heap/
  uptime/bootcount/reset reason/RSSI/MAC/pin map), mDNS `bmstester.local`,
  keep-WiFi reset, boot-counter reset.
### Verified
- 134/134 (93 pio incl. 5 upload-gate tests + 41 web) + contract (single-end
  rule, no-`SIZE_UNKNOWN`, portal-surface rules) + soak + virtual-bus + both
  PIO envs.

## [v2.3.1] — 2026-09-21
### Fixed
- Saves stick: the 1 s tick is status-only; forms fill on load + after saves
  (dirty-tracking + fetch-failure tolerance); user edits never clobbered.
- UTF-8 on all pages (garbled letters gone); OTA check tag parse tolerates
  the API's space-after-colon + dashboard Install button works.
### Changed
- Login wall REMOVED (WPA2 is the gate): reboot/reset/upload/OTA-admin/AP
  saves ask the admin password per request (default `admin123`); passwords
  scrubbed from `/api/state`.
- Chase hold is automatic (`Chase sweeps`, default 3, 0 = forever).
### Added
- Spoof trigger GPIO configurable (safe-pin allowlist, else 21, live re-arm).
  WiFi kill switch: ground GPIO18 to drop AP+portal+server, release restores.
### Removed
- Session logins + remember-me NVS slots; legacy `hch` hold (replaced by
  `swp` auto-hold — upgraders keep 3 sweeps).
### Verified
- 103/103 (77 pio + 26 web) + contract + soak.

## [v2.3] — 2026-09-21
### Added
- Relay count (first N of 8; beyond-N forced OFF + greyed tiles) + chase-wave
  mode (3rd sequence mode: single lit relay sweeping R1→Rn→R1, wraps, both
  directions, all button modes apply).
- 2-stage spoof (stage 1 "100" 5 s → stage 2 88.8/88.8/88.8/188 10 s; values
  + seconds both editable; upgraders' single-stage values migrate to stage 2).
- Per-mode holds in ms (`hseq`/`hall`, 0 = forever each); industrial pack:
  loop + pause + cycle limit, ALL-ON stagger (inrush ramp), direction, 8
  relay labels, cycle/actuation QC counters, boot auto-start.
- Persistent logins (remember-me, 30-day NVS slots ×4); OTA via offline
  `/update` upload or automatic GitHub checks/installs over the optional STA
  uplink; coalesced config saves (dirty-flag, 1.5 s flush — no loop stalls).
- NVS `bms2` v3 with tested v2→v3 migration (seconds×1000 fanned to holds).
- 38 new tests (**105/105**: 70 pio + 29 web; contract gate + soak alongside).
### Changed
- `FW_VERSION`/`STATUS?` → `2.3`; dashboard version is live from the device.

## [v2.2] — 2026-09-21
### Fixed
- Login page pops automatically on join (captive portal DNS catch-all +
  unknown-URL 302 redirect); AP IP pinned to 192.168.4.1. Report + wiki warn:
  turn mobile data off — phones route around "no internet" networks.
### Added
- Portal-redirect flow host test (15 web tests → **67/67** total).
### Changed
- `FW_VERSION`/`STATUS?` → `2.2`.

## [v2.1] — 2026-09-21
### Added
- 14 host-executed website tests + JS↔firmware contract gate
  (`tools/check_web_contract.py`) + 24 h office-day sim (86,400 polls,
  per-reply checksum validation) + Wokwi automation scenario (`sim.yaml`)
  with token-gated CI sim job (**66/66** total).
- Wokwi diagram verified against official docs and fixed (NeoPixel VDD/VSS,
  button pins); 8 real relay-module parts with NO-contact indicator LEDs.
### Changed
- `select_reply()` host-covered refactor (behavior-identical).
  `FW_VERSION`/`STATUS?` → `2.1`. Bench-confirmed: relay idle HIGH,
  ON-when-LOW = active-LOW default.

## [v2.0] — 2026-09-21
### Added
- 8-relay sequencer (sequential/all-ON, 3 button behaviors: hold-abort /
  run-lock / restart; boot-safe OFF-first drive; polarity toggle); always-on
  AP dashboard (login auth, NVS persistence, admin reset); spoof window
  (88.8/88.8/88.8/188 on `0x03`, configurable duration, auto-revert).
- 18 new tests (**50/50**); Wokwi relay LEDs + buttons; CI builds both envs.
### Changed
- `FW_VERSION`/`STATUS?` → `2.0`; radio on (AP always broadcasting).
  v1.x responder core frozen and re-proven.

## [v1.2] — 2026-09-21
### Added
- Onboard WS2812 RGB mirror (GPIO48, built-in `neopixelWrite`, brightness 32):
  same green/red state as the discretes, zero extra wiring, driven from the
  250 ms eval (never the hot RX loop).
- N16R8 build (`s3-n16r8`: 16 MB flash, OPI PSRAM, `default_16MB.csv`);
  8 MB env kept for Wokwi. Wokwi NeoPixel part on GPIO48; `firmware-n16r8/`
  ready-to-flash triple; Arduino IDE board menu documented.
### Changed
- `FW_VERSION`/`STATUS?` → `1.2`; MODULES/arduino/wokwi/src READMEs, llms.txt.
### Verified
- 32/32 + soak green; both envs compile; virtual-bus PASS; golden bytes +
  `STATUS?` strings byte-present in both `firmware.bin` images.

## [v1.1] — 2026-09-18
### Added
- Multi-register canned replies (`0x03` golden 52.0 V/100 %, `0x04` 14×3714 mV,
  `0x05` name); silence on writes/unknown (option A — explicit user-confirmed
  choice); adaptive 2–10 s link window (EMA of poll intervals); streaming
  checksum-verified parser with noise re-sync; 21 new tests (**32/32**);
  `arduino/`, `firmware/` triple, `captures/`, `virtual_meter.py` scenario
  modes, `soak_sim.cpp`, Wokwi meter.
### Fixed
- Parser emits only on checksum success (a corrupt-CK + trailing `0x77` used
  to emit — gated, now covered by test); Arduino `B1` macro collision
  (parser states renamed `JST_*`, broke the S3 build once).

## [v1.0] — 2026-09-18
### Added
- 0x03-only responder, fixed 2 s link window, green/red discrete LEDs,
  USB-serial `STATUS?` (`GREEN`/`RED`), 11/11 tests, S3 binary, Word report.
  Frozen as `releases/bms-connection-tester-v1.0.zip` + tag `v1.0`; responder
  core untouched by all v2.x work (original tests byte-identical).

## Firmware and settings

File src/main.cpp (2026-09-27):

// e-rickshaw meter RS485 connection tester — ESP32-S3 firmware v2.9.
// v1.x base FROZEN: JBD responder (0x03/0x04/05, option-A silence), adaptive
// link window, green/red LEDs + RGB mirror, STATUS?. v2.0 ADDS (never alters):
// 8-relay sequencer (sequential / all-ON, 3 button behaviors), always-on WiFi
// AP web UI (config + admin auth, NVS), spoof window (test values on 0x03).
// v2.3 ADDS: relay count (first N) + chase-wave mode, 2-stage spoof
// (100-first then 88.8/188, both stages editable, timings per stage),
// hold in milliseconds, manual + automatic OTA.
// v2.4 ADDS: Tasmota-grade update gates, per-mode relay menu (chase BBM +
// stop dead-band + new timing floors), spoof save-only, console, config
// backup/restore, custom OTA URL, STA uplink test, info card, mDNS.
//
// Wiring (ESP32-S3-DevKitC-1 / S3 N16R8):
//   GPIO17 (TX) -> MAX485 DI | GPIO16 (RX) -> MAX485 RO
//   GPIO4 -> MAX485 DE+RE tied (HIGH=TX, LOW=RX, 10k pull-down to GND)
//   GPIO10 -> green LED (+220R to GND) | GPIO11 -> red LED (+220R to GND)
//   GPIO48 -> onboard WS2812 RGB (mirrors green/red, no wiring needed)
//   GPIO5,6,7,8,9,12,13,14 -> relay module IN1..IN8 (12V coils, own supply,
//     common GND; default active-LOW, web toggle)
//   GPIO15 -> button to GND (press = LOW, internal pull-up; web-invertible)
//   GPIO21 -> spoof trigger to GND (internal pull-up; web-invertible)
//   GPIO18 -> WiFi kill to GND (ground = AP off; internal pull-up)
//   Common GND. MAX485 VCC = 3.3V. USB powered (never the pack).
//
// Wiring (Waveshare ESP32-S3-ETH-8DI-8RO, -DBOARD_WAVESHARE_8DI8RO=1):
//   Relays R1..R8 -> TCA9554PWR EXIO1..EXIO8 @ I2C 0x20 (SDA42/SCL41),
//     output-register bit i = relay i+1, HIGH bit = ON (fixed in hardware;
//     the web "active-low" toggle is a documented no-op on this board)
//   GPIO17 (TX) -> onboard isolated RS485 (SP3485)
//   GPIO18 (RX) -> onboard isolated RS485
//   GPIO21 (DE/RTS) -> RS485 direction: UART RS485 half-duplex mode drives
//   it in hardware (HIGH = TX, LOW = RX); manual drive is the fallback
//   GPIO0 (BOOT button) -> START/STOP to GND (press = LOW, internal pull-up)
//   GPIO4 (DI1 terminal) -> spoof trigger to COM (active = LOW, web-changeable)
//   GPIO5 (DI2 terminal) -> WiFi kill to COM (active = LOW = AP off)
//   GPIO38 -> onboard WS2812 RGB (mirrors green/red, no wiring needed)
//   GPIO12..16 = W5500 Ethernet (SPI15/14/13, CS16, IRQ12, RST39, best-effort)
//   GPIO46 = buzzer (LEDC, driven only after setup)
//   DI3..DI8 (GPIO6..11) free. USB-C powered (never the pack).
//
// USB-serial STATUS? extension (test jig only, NOT a JBD command):
//   "STATUS?\n" -> "GREEN 2.8\n" / "RED 2.8\n" (first token stable for HIL).

#include <Arduino.h>
#include "bms_protocol.h"
#include "fw_upload.h"  // v2.4 shared update gates (host-tested)
#include "relay_ctrl.h"
#include "web_ui.h"
#include "ota.h"
#ifdef BOARD_WAVESHARE_8DI8RO
#include "waveshare_pins.h"  // TCA9554 relay map + pure port logic (host-tested)
#include "ws_eth.h"          // W5500 Ethernet (ESP-IDF esp_eth, best-effort)
#include <Wire.h>
#endif
#define RS485_SERIAL Serial2
// OTA transport (ESP-only; never host-built — main.cpp is the sketch).
#include <WiFiClientSecure.h>
#include <HTTPClient.h>
#include <Update.h>

#ifdef BOARD_WAVESHARE_8DI8RO
// Waveshare ESP32-S3-POE-ETH-8DI-8DO (flag keeps the historic 8DI8RO name):
// 8 digital outputs live on the TCA9554PWR I2C expander (see
// waveshare_pins.h), RS485 = TX17/RX18 with direction on GPIO21 driven by
// the ESP32 UART in RS485 half-duplex mode (official 8DO demo
// WS_RS485.cpp; manual DE in send_frame() is only a setMode() fallback),
// BOOT = START/STOP, DI1/DI2 = spoof/WiFi-kill, RGB on GPIO38.
#define PIN_RS485_TX   WS_PIN_RS485_TX
#define PIN_RS485_RX   WS_PIN_RS485_RX
#define PIN_RS485_DE   WS_PIN_RS485_DE
// (no discrete green/red LEDs — RGB only)
#define PIN_RGB WS_PIN_RGB  // onboard WS2812; not RGB_BUILTIN (core boards
                            // vary) — fixed 38 per Waveshare schematic
#define RGB_BRIGHT 32  // WS2812 is blinding at 255; 16-32 is plenty

#define PIN_BUTTON WS_PIN_BUTTON
#define PIN_SPOOF  WS_PIN_SPOOF
#define PIN_WIFI_KILL WS_PIN_WIFI_KILL
#define PIN_RELAY_TRIGGER WS_PIN_RELAY_TRIGGER  // DI3: manual relay sequencer trigger
// (no RELAY_PINS — relays are TCA9554 output-register bits)
#else
#define PIN_RS485_TX   17
#define PIN_RS485_RX   16
#define PIN_RS485_DE    4
#define PIN_LED_GREEN  10
#define PIN_LED_RED    11
// Onboard WS2812 RGB (S3 N16R8 / DevKitC-1 with RGB). Mirrors the
// external LEDs so the box works with zero extra wiring.
// Built-in neopixelWrite() needs no extra library (Arduino-ESP32).
#ifndef RGB_BUILTIN
#define RGB_BUILTIN 48
#endif
#define PIN_RGB RGB_BUILTIN
#define RGB_BRIGHT 32  // WS2812 is blinding at 255; 16-32 is plenty

#define PIN_BUTTON 15
#define PIN_SPOOF  21
// v2.3.1 WiFi kill switch (manual, default ON): free DIO, non-strapping,
// no ADC/boot role. Ground to kill the AP, release to bring it back.
#define PIN_WIFI_KILL 18
static const uint8_t RELAY_PINS[RELAY_COUNT] = {5, 6, 7, 8, 9, 12, 13, 14};
#endif

#define EVAL_INTERVAL_MS 250UL  // brisk eval so fast/slow polls both feel live
#define FACTORY_RESET_HOLD_MS 10000UL  // button held 10 s -> wipe NVS + reboot

static JbdParser parser;
static PollTracker tracker;
static unsigned long lastEvalMs = 0;
static bool connected = false;
#ifdef BOARD_WAVESHARE_8DI8RO
// True when the ESP32 UART RS485 half-duplex mode took over GPIO21 (RTS):
// the peripheral then drives DE itself and send_frame() must NOT touch the
// pin. False -> manual digitalWrite(DE) fallback (proven on hardware).
static bool rs485_hw_de = false;
#endif

// ---- v2.0 state (base state above untouched) ----
static Bms2Config cfg;
static RelaySequencer seq;
static SpoofPlan spoof;  // v2.3: two-stage (100 first, then 88.8/188)
static DebouncedInput btn_in;
static DebouncedInput spoof_in;
static DebouncedInput wifi_in;  // v2.3.1 AP kill switch (ground = WiFi off)
static DebouncedInput relay_trig_in;  // DI3: manual relay sequencer trigger
#ifdef BOARD_WAVESHARE_8DI8RO
static uint8_t curSpoofPin = WS_PIN_SPOOF;  // v2.3.1: follows cfg.spoof_pin
#else
static uint8_t curSpoofPin = 21;  // v2.3.1: follows cfg.spoof_pin (sanitized)
#endif
static uint8_t spoofFrameA[SPOOF_FRAME_LEN];  // stage 1 ("100")
static uint8_t spoofFrameB[SPOOF_FRAME_LEN];  // stage 2 (88.8/188 pattern)
static bool spoofFrameReady = false;
// v2.8.7 RS485 diagnostics: last RX/TX frames (hex-dumped to /api/state).
// Helps identify rogue bus traffic (e.g. unknown 6-byte responses).
static uint8_t diagRxFrame[16];
static uint8_t diagRxLen = 0;
static uint8_t diagTxFrame[40];
static uint8_t diagTxLen = 0;
static uint8_t lastRelayLevels[RELAY_COUNT];
static bool relaysArmed = false;
#ifdef BOARD_WAVESHARE_8DI8RO
static uint8_t lastWsRelayBits = 0x00;  // TCA9554 output-register cache

// Live TCA9554 status (see waveshare_pins.h): false on any bus error,
// true again on any success (self-heals); /api/state reports
// "expander":"ok|fail", the RGB flashes red while failed.
static WsTcaFault tca_fault;

// ---- Buzzer: GPIO46, LEDC 1 kHz / 8-bit, duty <= WS_BUZZER_DUTY ----
// Strapping pin: never driven before setup() runs (the official demo's
// GPIO_Init runs in setup too); ledcWrite(0) parks it silent. All sounds
// are queued through WsBuzzer (non-blocking pattern engine, host-tested)
// and drained from loop() — never delay(), never in the RS485 hot path.
#define WS_BUZZER_LEDC_CH 1
static bool buzzer_ready = false;
static WsBuzzer ws_buzzer;
static void buzzer_init() {
  ledcSetup(WS_BUZZER_LEDC_CH, 1000, 8);  // 1 kHz, 8-bit (official demo)
  ledcAttachPin(WS_PIN_BUZZER, WS_BUZZER_LEDC_CH);
  ledcWrite(WS_BUZZER_LEDC_CH, 0);
  buzzer_ready = true;
}
// Queue a beep (no-op before buzzer_init, and no-op while the user has the
// buzzer disabled in the web UI; Waveshare build only).
static void buzzer_beep(uint16_t total_ms, uint16_t flick_ms) {
  if (ws_buzzer_gate(buzzer_ready, cfg.buzzer_enabled)) ws_buzzer.push(total_ms, flick_ms);
}
// Advance the pattern engine; touch LEDC only when the level changes.
static void buzzer_tick(unsigned long now) {
  if (buzzer_ready && ws_buzzer.tick(now))
    ledcWrite(WS_BUZZER_LEDC_CH, ws_buzzer.out ? WS_BUZZER_DUTY : 0);
}

// Minimal TCA9554PWR access: single-register write. Returns false on bus
// error (caller parks safe / retries; sequencer state is untouched). A
// failure latches tca_fault (one-shot buzzer alarm on the edge); any
// later success clears it again.
static bool tca_write_reg(uint8_t reg, uint8_t val) {
  Wire.beginTransmission(WS_TCA9554_ADDR);
  Wire.write(reg);
  Wire.write(val);
  bool ok = Wire.endTransmission() == 0;
  if (tca_fault.note(ok)) buzzer_beep(5000, 500);  // demo DoutFailTask alarm
  return ok;
}

// All pins output, all channels OFF — the expander equivalent of the
// direct-GPIO "drive OFF level BEFORE pinMode" rule. Register order (OUTPUT
// before CONFIG) mirrors the official 8DO demo (WS_Dout.cpp Dout_Init ->
// TCA9554PWR_Init); the step table lives in waveshare_pins.h so the host
// Unity suite tests the exact sequence the firmware ships.
static bool tca_relays_init() {
  for (uint8_t i = 0; i < WS_TCA9554_INIT_STEPS; i++) {
    WsTcaInitStep s = ws_tca_init_step(i);
    if (!tca_write_reg(s.reg, s.val)) return false;
  }
  return true;
}
#endif
static unsigned long btnPressStart = 0;
static bool btnPressed = false;
static bool resetDone = false;
static unsigned long last_bus_ms = 0;  // v2.3: last valid meter frame (OTA gate)

static void rebuild_spoof_frame() {
  build_spoof_frame(cfg, 1, spoofFrameA);
  build_spoof_frame(cfg, 2, spoofFrameB);
  spoofFrameReady = true;
}

static void apply_leds(bool on) {
  connected = on;
#ifdef BOARD_WAVESHARE_8DI8RO
  // Expander fault override (official demo DoutFailTask pattern): red flash
  // while the TCA9554 is unreachable. Takes over the whole lamp.
  if (!tca_fault.ok) {
    bool phase = (millis() / 250) % 2 == 0;
    // R/G-swapped board (v2.8.1): physical red = neopixelWrite(pin, 0, B, 0).
    neopixelWrite(PIN_RGB, 0, phase ? RGB_BRIGHT : 0, 0);
    return;
  }
  // Link-transition beep. The boot call happens before buzzer_init, so it
  // stays silent — no strapping-pin drive during early boot.
  static bool prev_on = false;
  if (on != prev_on) { buzzer_beep(200, 0); prev_on = on; }
  // No discrete LEDs on this board — the onboard RGB (GPIO38) is the lamp.
#else
  digitalWrite(PIN_LED_GREEN, on ? HIGH : LOW);
  digitalWrite(PIN_LED_RED, on ? LOW : HIGH);
#endif
  // Onboard RGB mirrors the discretes: green = talking, red = silent.
  // RMT-driven, safe to call from the 250 ms eval (never the hot RX loop).
#if defined(ARDUINO)
#ifdef BOARD_WAVESHARE_8DI8RO
  // 8DI8RO quirk: this board's RGB element expects RGB byte order, not the
  // WS2812-standard GRB (Waveshare's own demo works around it the same way:
  // RGB_Light(r,g,b) -> neopixelWrite(pin, g, r, b), "RGB color adjustment").
  // neopixelWrite() emits GRB on the wire, so swap R/G here, otherwise our
  // red (silent) state physically displays as green and vice versa.
  neopixelWrite(PIN_RGB, on ? RGB_BRIGHT : 0, on ? 0 : RGB_BRIGHT, 0);
#else
  neopixelWrite(PIN_RGB, on ? 0 : RGB_BRIGHT, on ? RGB_BRIGHT : 0, 0);
#endif
#endif
}

static void apply_relays() {
  // v2.3: only the first cfg.relay_count relays participate; pins beyond
  // the count are forced OFF so a shrunk count can't leave a coil latched.
  uint8_t n = cfg.relay_count;
  if (n < 1 || n > RELAY_COUNT) n = RELAY_COUNT;
#ifdef BOARD_WAVESHARE_8DI8RO
  // TCA9554PWR: one I2C write carries all 8 relays (bit i = relay i+1,
  // HIGH = ON). cfg.active_low is fixed hardware here and intentionally
  // ignored — dashboard labels always match the coils. Change detection
  // via the output-register cache, same as the GPIO path below.
  bool on[RELAY_COUNT];
  for (uint8_t i = 0; i < RELAY_COUNT; i++)
    on[i] = (i < n) ? seq.relayOn(i) : false;
  uint8_t bits = ws_output_byte(on, n);
  if (!relaysArmed || bits != lastWsRelayBits) {
    bool ok = tca_write_reg(WS_TCA9554_REG_OUTPUT, bits);
    if (ok) {
      lastWsRelayBits = bits;
    } else if (bits != 0x00) {
      tca_write_reg(WS_TCA9554_REG_OUTPUT, 0x00);  // park safe on bus error
      // lastWsRelayBits untouched -> the intended state retries next eval
    }
  }
  relaysArmed = true;
#else
  for (uint8_t i = 0; i < RELAY_COUNT; i++) {
    bool on = (i < n) ? seq.relayOn(i) : false;
    uint8_t lvl = relay_pin_level(on, cfg.active_low);
    if (!relaysArmed || lvl != lastRelayLevels[i]) {
      digitalWrite(RELAY_PINS[i], lvl);
      lastRelayLevels[i] = lvl;
    }
  }
  relaysArmed = true;
#endif
}

// ---- v2.3 OTA (GitHub releases; needs the optional STA uplink) ----
static OtaState ota;

static void ota_set_status(const char *s) {
  strncpy(ota.status, s, sizeof(ota.status) - 1);
  ota.status[sizeof(ota.status) - 1] = '\0';
}

// Query the latest release tag from GitHub. Caller guarantees STA online.
static void ota_check_now() {
  unsigned long now = millis();
  ota.last_check_ms = now;
  WiFiClientSecure cli;
  cli.setInsecure();  // LAN bench box; a bad flash is fixed over USB
  HTTPClient http;
  // v2.8: the Waveshare board line ships in the SAME release as the generic
  // line (one v2.8 tag, variant assets), so every build checks
  // /releases/latest and downloads its own variant asset.
  const char *releases_url =
      "https://api.github.com/repos/bm-a/bms-connection-tester/"
      "releases/latest";
  if (!http.begin(cli, releases_url)) {
    ota_set_status("check failed");
    return;
  }
  int code = http.GET();
  if (code != 200) {
    char b[48];
    snprintf(b, sizeof(b), "check http %d", code);
    ota_set_status(b);
    http.end();
    return;
  }
  String body = http.getString();
  http.end();
  // GitHub pretty-prints ("tag_name": "v2.3"); tolerate any gap after ':'.
  // Take the first tag_name (/releases/latest returns exactly one release).
  String tag;
  int from = 0;
  for (;;) {
    int ti = body.indexOf("\"tag_name\"", (unsigned)from);
    if (ti < 0) break;
    int ci = body.indexOf(':', (unsigned)(ti + 10));
    if (ci < 0) break;
    int q1 = body.indexOf('"', (unsigned)(ci + 1));
    if (q1 < 0) break;
    String cand = body.substring((unsigned)(q1 + 1));
    int q = cand.indexOf('"');
    if (q >= 0) cand = cand.substring(0, (unsigned)q);
    from = q1 + 1;
    if (cand.length() == 0 || cand.length() >= (int)sizeof(ota.latest_tag))
      continue;  // malformed entry: skip it, keep scanning
    tag = cand;
    break;
  }
  if (tag.length() == 0) {
    ota_set_status("bad api reply");
    return;
  }
  strncpy(ota.latest_tag, tag.c_str(), sizeof(ota.latest_tag) - 1);
  ota.update_pending = ota_cmp_version(tag.c_str(), FW_VERSION) > 0;
  ota_set_status(ota.update_pending ? "update available" : "up to date");
}
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
void loop() {
  unsigned long now = millis();

  // --- v2.0: button (press event + 10 s long-press factory reset) ---
  bool btnRaw = digitalRead(PIN_BUTTON) == HIGH;  // pull-up idle HIGH
  bool pressed = cfg.button_invert ? btnRaw : !btnRaw;
  btn_in.update(!pressed, now);  // feed idle-HIGH domain: fell = press
  if (btn_in.fell()) {
    btnPressed = true;
    btnPressStart = now;
    handle_button_press(seq, cfg, now);
  }
  if (btn_in.rose()) btnPressed = false;
  if (btnPressed && !resetDone &&
      (now - btnPressStart) >= FACTORY_RESET_HOLD_MS) {
    resetDone = true;
    web_factory_reset();  // wipes NVS + reboots; never returns
  }

  // --- v2.3.1: WiFi kill switch (ground PIN_WIFI_KILL = AP off now) ---
  bool wifiRaw = digitalRead(PIN_WIFI_KILL) == HIGH;  // pull-up idle HIGH
  wifi_in.update(wifiRaw, now);  // fell = grounded, rose = released
  if (wifi_in.fell()) web_wifi_set(false);
  else if (wifi_in.rose()) web_wifi_set(true);

#ifdef BOARD_WAVESHARE_8DI8RO
  // --- DI3: manual relay sequencer trigger (ground = START/STOP) ---
  bool trigRaw = digitalRead(PIN_RELAY_TRIGGER) == HIGH;  // pull-up idle HIGH
  relay_trig_in.update(trigRaw, now);  // fell = grounded
  if (relay_trig_in.fell()) handle_button_press(seq, cfg, now);
#endif

  // --- v2.0: spoof trigger input (v2.3: fires the two-stage plan) ---
  // v2.3.1: pin follows cfg.spoof_pin (NVS, sanitized); re-arm on change.
  uint8_t wantPin = sanitize_spoof_pin(cfg.spoof_pin);
  if (wantPin != curSpoofPin) {
    pinMode(curSpoofPin, INPUT);  // release the old pin (no pull)
    curSpoofPin = wantPin;
    cfg.spoof_pin = wantPin;
    pinMode(curSpoofPin, INPUT_PULLUP);
    spoof_in.begin(true);
  }
  bool spRaw = digitalRead(curSpoofPin) == HIGH;
  bool spActive = cfg.spoof_invert ? spRaw : !spRaw;
  spoof_in.update(!spActive, now);
  if (spoof_in.fell() && cfg.spoof_enabled)
    spoof.trigger(now, (unsigned long)cfg.spoof_seconds * 1000UL,
                  (unsigned long)cfg.s2_seconds * 1000UL);

  // --- v2.0: sequencer + relay outputs + web server (all non-blocking) ---
  // (v2.6 meter heuristic is fed inside web_tick(): link gaps = new meter.)
  seq.tick(now);
  apply_relays();
  web_tick(now);
  ota_auto_tick(now);  // v2.3: no-op without STA internet + idle bench

  // --- FROZEN v1.x RS485 path (untouched logic) ---
  JbdFrame f;
  // v2.8.7: raw byte accumulator for RX diagnostics
  static uint8_t rxAccum[16];
  static uint8_t rxAccumLen = 0;
  while (RS485_SERIAL.available()) {
    uint8_t b = (uint8_t)RS485_SERIAL.read();
    // Accumulate raw bytes (reset on DD which starts a new frame)
    if (b == 0xDD) rxAccumLen = 0;
    if (rxAccumLen < sizeof(rxAccum)) rxAccum[rxAccumLen++] = b;
    if (parser.feed(b, f)) {
      // v2.8.7: log the accepted RX frame for diagnostics
      diagRxLen = rxAccumLen;
      for (uint8_t i = 0; i < diagRxLen; i++) diagRxFrame[i] = rxAccum[i];
      rxAccumLen = 0;
      // Any well-formed meter frame proves wiring: refresh green window.
      tracker.note_poll(now);
      last_bus_ms = now;
      // v2.3: during a spoof plan, reg 0x03 answers stage 1 ("100") then
      // stage 2 (88.8/188); every other rule (option-A silence,
      // golden/cell/name frames) is frozen. The rule itself lives in
      // select_reply() (host-tested in test_system).
      size_t rlen = 0;
      uint8_t stage = spoof.stage(now);
      const uint8_t *sf = nullptr;
      if (stage == 2) sf = spoofFrameB;
      else if (stage == 1) sf = spoofFrameA;
      const uint8_t *reply = select_reply(
          f, cfg, stage, (sf && spoofFrameReady) ? sf : nullptr, rlen);
      if (reply) send_frame(reply, rlen);
    }
  }

  // --- live status evaluation (millis timer, no delay) ---
  if (now - lastEvalMs >= EVAL_INTERVAL_MS) {
    lastEvalMs = now;
#ifdef BOARD_WAVESHARE_8DI8RO
    // v2.9.0: sequencer start/stop beeps (link beeps live in apply_leds)
    // + drain the non-blocking buzzer pattern engine.
    static bool prev_running = false;
    bool running = seq.running();
    if (running != prev_running) {
      buzzer_beep(running ? 200 : 500, running ? 0 : 150);
      prev_running = running;
    }
    buzzer_tick(now);
#endif
    apply_leds(tracker.active(now));
  }
  // (v2.6 meter heuristic is fed inside web_tick() below: link gaps = new
  // meter. One funnel — main.cpp never touches the batch directly.)

  handle_status_command();
}

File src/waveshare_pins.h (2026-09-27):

#pragma once
#include <stdint.h>
#include <stdbool.h>

// Waveshare ESP32-S3-POE-ETH-8DI-8DO board map + pure port logic.
// Hardware-independent (no Arduino dependency) so it compiles on the host
// for Unity tests, exactly like bms_protocol.* / relay_ctrl.h.
//
// Map verified 2026-09-27 against the OFFICIAL 8DO demo
// (ESP32-S3-POE-ETH-8DI-8DO-Demo.zip from
//  https://www.waveshare.com/wiki/ESP32-S3-POE-ETH-8DI-8DO):
//  - WS_GPIO.h: TXD1=17, RXD1=18, TXD1EN=21, GPIO_PIN_RGB=38,
//    GPIO_PIN_Buzzer=46; WS_DIN.h: DIN_PIN_CH1..8 = GPIO4..GPIO11.
//  - WS_RS485.cpp RS485_Init(): lidarSerial.begin(9600, SERIAL_8N1, RXD1,
//    TXD1) then setPins(-1,-1,-1,TXD1EN) + setMode(UART_MODE_RS485_HALF_DUPLEX)
//    — the ESP32 UART peripheral auto-drives GPIO21 (RTS) for direction.
//    (The wiki product page's "hardware-flow direction" = this UART mode,
//    not board hardware: without the UART mode or manual DE the ESP32
//    receives nothing — proven 2026-09-27.)
//  - WS_TCA9554PWR.h/.cpp: TCA9554PWR @ 0x20, OUTPUT reg 0x01, CONFIG reg
//    0x03; Set_EXIO(CHx,true) sets bit (CHx-1) -> EXIOx; Dout_Init() calls
//    TCA9554PWR_Init(0x00, 0xFF) = write OUTPUT_REG first, then CONFIG_REG.
//    HIGH bit = channel ON (Darlington sink outputs, 500 mA).
//  - WS_GPIO.cpp RGB_Light(r,g,b) -> neopixelWrite(pin, g, r, b): the RGB
//    element expects RGB byte order, so R/G are swapped on the wire.
//  - WS_DIN.cpp DIN_Init(): pinMode(DIN_PIN_CHx, INPUT_PULLUP) — digital
//    inputs are opto-isolated, active = LOW.
// I2C: SDA=42/SCL=41 per demo I2C_Driver.h (shared with RTC @ 0x51).

// ---- TCA9554PWR (DO expander) ----
#define WS_TCA9554_ADDR        0x20
#define WS_TCA9554_REG_OUTPUT  0x01
#define WS_TCA9554_REG_CONFIG  0x03
#define WS_I2C_SDA             42
#define WS_I2C_SCL             41

// TCA9554 boot sequence, mirroring the official 8DO demo
// (WS_Dout.cpp Dout_Init -> TCA9554PWR_Init(PinMode, PinState)):
// the OUTPUT register is written BEFORE the CONFIG register.
// The demo passes PinState=0xFF (all 8 channels ON at boot); this firmware
// deliberately parks WS_TCA9554_BOOT_OUTPUT=0x00 (all OFF) instead — the
// safe boot state for an automated test bench. The register ORDER is the
// part that must match the demo; the park value is our application choice.
#define WS_TCA9554_BOOT_OUTPUT 0x00
#define WS_TCA9554_BOOT_CONFIG 0x00
struct WsTcaInitStep { uint8_t reg; uint8_t val; };
static inline WsTcaInitStep ws_tca_init_step(uint8_t step) {
  WsTcaInitStep s = {0, 0};
  if (step == 0)      { s.reg = WS_TCA9554_REG_OUTPUT; s.val = WS_TCA9554_BOOT_OUTPUT; }
  else if (step == 1) { s.reg = WS_TCA9554_REG_CONFIG; s.val = WS_TCA9554_BOOT_CONFIG; }
  return s;
}
#define WS_TCA9554_INIT_STEPS 2

// ---- RS485: TX17/RX18; direction on GPIO21 (RTS/TXD1EN) ----
// Official 8DO demo (WS_RS485.cpp): UART_MODE_RS485_HALF_DUPLEX via
// setPins(-1,-1,-1,TXD1EN) + setMode() — the ESP32 UART peripheral
// auto-drives GPIO21 (HIGH=TX, LOW=RX). main.cpp uses that mode and keeps
// manual digitalWrite(DE) only as a fallback if setMode() fails.
#define WS_PIN_RS485_TX  17
#define WS_PIN_RS485_RX  18
#define WS_PIN_RS485_DE  21

// ---- Controls: BOOT button = START/STOP; DI terminals for the rest ----
#define WS_PIN_BUTTON     0   // BOOT, press = LOW (strapping pin: holding it
                              // at power-on enters download mode — normal)
#define WS_PIN_DI_BASE    4   // DI1..DI8 = GPIO4..GPIO11, active = LOW (NPN opto pulls LOW)
#define WS_PIN_DI_COUNT   8
#define WS_PIN_SPOOF      4   // DI1: spoof trigger (default, web-changeable)
#define WS_PIN_WIFI_KILL  5   // DI2: ground = AP off (default)
#define WS_PIN_RELAY_TRIGGER 6 // DI3: trigger relay sequencer (START/STOP)

// ---- Indicators ----
#define WS_PIN_RGB  38  // onboard WS2812 (discrete green/red LEDs don't exist)

// ---- Buzzer (GPIO46) ----
#define WS_PIN_BUZZER   46  // active buzzer, LEDC 1 kHz / 8-bit, duty <= 200
#define WS_BUZZER_DUTY  200 // official demo Dutyfactor (of 255 max)
// Strapping pin: the ESP glue must never drive it before setup() (the
// official demo's GPIO_Init runs in setup too); ledcWrite(0) parks silent.

// ---- Reserved: do not touch ----
 // GPIO12..16 = W5500 Ethernet (INT/MOSI/MISO/SCLK/CS) — driven by ws_eth.cpp
 // GPIO40     = RTC interrupt; GPIO41/42 shared with RTC @ 0x51

// Logical output i (0..7) -> EXIO(i+1) -> output-register bit i.
// Official demo: HIGH bit = channel ON (Dout_Open = Set_EXIO(CH, true);
// ALL_ON writes 0xFF). The 8DO channels are Darlington sink outputs
// (500 mA), not relay coils, but the EXIO interface is identical.
static inline uint8_t ws_relay_bit(uint8_t i) { return (uint8_t)(1u << i); }
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

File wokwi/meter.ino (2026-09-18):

// Virtual meter stimulus for Wokwi sim (meter MCU in diagram.json) — v1.1.
// Cycles registers 0x03/0x04/0x05 every 1s like a thorough real meter,
// prints whatever the DUT replies. DUT must answer all three (option A:
// silence only on writes/unknown). Observe DUT LEDs: green while polling,
// red if you stop this meter (reset it).
void setup() {
  Serial.begin(115200);
  Serial2.begin(9600, SERIAL_8N1, 16, 17);
}
static uint8_t regs[] = {0x03, 0x04, 0x05};
static uint8_t idx = 0;
void loop() {
  uint8_t reg = regs[idx];
  idx = (idx + 1) % 3;
  uint16_t ck = 0x10000 - (reg + 0x00);
  uint8_t poll[7] = {0xDD, 0xA5, reg, 0x00, (uint8_t)(ck >> 8), (uint8_t)(ck & 0xFF), 0x77};
  Serial2.write(poll, 7);
  Serial2.flush();
  delay(200);
  Serial.print("meter reg ");
  Serial.print(reg, HEX);
  Serial.print(" rx: ");
  while (Serial2.available()) {
    char b[4];
    snprintf(b, sizeof(b), "%02X ", Serial2.read());
    Serial.print(b);
  }
  Serial.println();
  delay(800);
}

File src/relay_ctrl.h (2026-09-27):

#pragma once
#include <stdint.h>
#include <stddef.h>
#include "bms_protocol.h"

// v2.3 relay sequencer + 2-stage spoof + debounce + config.
// Hardware-independent (no Arduino dependency) so it compiles on the host
// for Unity tests, exactly like bms_protocol.*.
// The v1.x base (parser, dispatcher, tracker, golden frames, LEDs, STATUS?)
// is FROZEN and untouched — this file only adds selection + GPIO logic.

// Logical relay indexing: 0..7 maps to R1..R8 (physical pins in main.cpp).
// v2.3: only the first cfg.relay_count relays participate; the rest stay OFF.
#define RELAY_COUNT 8

// Relay run mode (web "Mode").
enum RelayMode : uint8_t {
  RELAY_SEQUENTIAL = 0,  // R1 -> R(n) with step delay, cumulative
  RELAY_ALL_ON = 1,      // first n at once
  RELAY_CHASE = 2,       // v2.3: single lit relay sweeping R1 -> R(n), wraps
};

// Button-press behavior (web "Button").
enum ButtonMode : uint8_t {
  BTN_HOLD_ABORT = 0,  // hold X s then auto-OFF; re-press mid-cycle = OFF now
  BTN_RUN_LOCK = 1,    // run to completion; presses ignored until finished
  BTN_RESTART = 2,     // re-press restarts the cycle from R1, any stage
};

// Persistent config (stored in NVS by web_ui; plain struct here for tests).
struct Bms2Config {
  // v2.4 timing floors (R4/R5/R6): step >= 100 ms (bounce + ADC settle),
  // stagger 20..1000 ms default 50 (never slam 8 contactors at once),
  // pause 500..60000 ms default 2000 (coil cooling between looped cycles).
  uint16_t step_delay_ms = 250;   // sequential gap R(n) -> R(n+1)
  // v2.3 per-mode holds (ms each; 0 = stay ON forever until stopped).
  // Sequential wants a short settle; ALL-ON burn-in wants a long soak.
  // UI shows one hold per mode (UI-only dedup, R2); both stay in NVS.
  uint32_t hold_seq_ms = 30000;
  // v2.3.1 chase auto-hold: full sweeps (0 = sweep forever until stopped).
  // Effective hold = sweeps x relay-count x step, recomputed at start(), so
  // it retunes itself when count/step change. Replaces hold_chase_ms.
  uint8_t chase_sweeps = 3;
  uint32_t hold_all_ms = 300000;
  uint8_t relay_count = 8;        // v2.3: first N relays participate (1..8)
  uint8_t relay_mode = RELAY_SEQUENTIAL;
  uint8_t button_mode = BTN_HOLD_ABORT;
  // v2.3 industrial pack (all additive; defaults = v2.0 behavior).
  bool loop_enabled = false;      // repeat the cycle until stopped/limit
  uint32_t cycle_pause_ms = 2000;  // rest between looped cycles (coil cooling)
  uint16_t cycle_limit = 0;       // 0 = forever, else stop after N cycles
  uint16_t allon_stagger_ms = 50;  // 0 = true at-once; >0 = ramp gap (inrush)
  uint8_t seq_dir = 0;            // 0 = R1->Rn, 1 = Rn->R1
  bool boot_autostart = false;    // start the configured mode on boot
  char relay_label[RELAY_COUNT][12];  // dashboard tile names (NVS, QC labels)
  Bms2Config() {
    for (uint8_t i = 0; i < RELAY_COUNT; i++) {
      relay_label[i][0] = 'R';
      relay_label[i][1] = (char)('1' + i);
      relay_label[i][2] = '\0';
    }
  }
#ifdef BOARD_WAVESHARE_8DI8RO
  // TCA9554 expander stage is fixed HIGH-bit = ON, so polarity is not a
  // hardware variable on this board: the relay writer ignores this field
  // (dashboard labels always match the hardware). Default false = truthful.
  bool active_low = false;
#else
  bool active_low = true;         // SmartElex class: LOW = relay ON
#endif
  bool button_invert = false;     // false: press pulls pin LOW (pull-up)
  bool spoof_invert = false;      // false: trigger pulls pin LOW
  bool spoof_enabled = true;
  // v2.3.1 configurable trigger GPIO (was hardwired 21). Only proven-safe
  // free DIOs are accepted; anything else falls back to the board default
  // (see sanitize_spoof_pin).
#ifdef BOARD_WAVESHARE_8DI8RO
  uint8_t spoof_pin = 4;          // DI1 terminal on the Waveshare board
#else
  uint8_t spoof_pin = 21;
#endif
  // v2.3 two-stage spoof: stage 1 fires first, then stage 2, then revert.
  // Stage 1 defaults = "100" (realistic full pack); stage 2 = 88.8/188
  // over-range pattern. Upgraders: legacy single-stage values migrate to
  // stage 2 (see web_ui NVS v2->v3 migration).
  uint16_t spoof_v_tenth = 1000;  // stage 1: 100.0 V display units (x0.1)
  uint16_t spoof_a_tenth = 1000;  // stage 1: 100.0 A display units (x0.1)
  uint16_t spoof_c_tenth = 1000;  // stage 1: 100.0 C display units (x0.1)
  uint8_t spoof_soc = 100;        // stage 1: 100 %
  uint16_t spoof_seconds = 5;     // stage 1 duration, 1..120
  uint16_t s2_v_tenth = 888;      // stage 2: 88.8 V display units (x0.1)
  uint16_t s2_a_tenth = 888;      // stage 2: 88.8 A display units (x0.1)
  uint16_t s2_c_tenth = 888;      // stage 2: 88.8 C display units (x0.1)
  uint8_t s2_soc = 188;           // stage 2: deliberately out-of-range pattern
  uint16_t s2_seconds = 10;       // stage 2 duration, 1..120
  // Buzzer enable (Waveshare GPIO46 only; no buzzer hardware on generic
  // builds). Default OFF: the board stays silent until the user enables it
  // in the web UI. Gated in main.cpp buzzer_beep() via ws_buzzer_gate().
  bool buzzer_enabled = false;
};

// Physical pin level for a logical relay state under the polarity setting.
// Tested on host so bench behavior is proven before flashing.
inline uint8_t relay_pin_level(bool logical_on, bool active_low) {
  // Arduino HIGH=1 / LOW=0 assumed by caller mapping.
  if (active_low) return logical_on ? 0 : 1;
  return logical_on ? 1 : 0;
}

// v2.3.1 spoof-trigger GPIO allowlist: proven-safe free DIOs only.
// Everything else (UART, relays, button, LEDs/RGB, USB, strapping, flash,
// the WiFi kill pin 18) falls back to 21. Tested on host.
inline uint8_t sanitize_spoof_pin(uint8_t p) {
#ifdef BOARD_WAVESHARE_8DI8RO
  // Waveshare 8DI8RO: the only user-drivable trigger inputs are the DI
  // screw terminals (DI1..DI8 = GPIO4..11, active = LOW like the old
  // button wiring). GPIO0 is the START/STOP button; everything else is
  // Ethernet / RS485 / I2C / RGB / buzzer. Anything else falls back to
  // DI1. Tested on host (test_waveshare).
  switch (p) {
    case 4: case 5: case 6: case 7: case 8: case 9: case 10: case 11:
      return p;
    default:
      return 4;
  }
#else
  switch (p) {
    case 1: case 2: case 21: case 38: case 39: case 40: case 41: case 42:
    case 43: case 44: case 47:
      return p;
    default:
      return 21;
  }
#endif
}

// v2.4 relay safety constants (R12/R15): fixed, NOT user fields.
// STOP_DEADBAND: all-OFF settle after any stop before a start is accepted
// (armatures still releasing; also covers loop PAUSE->restart implicitly).
// CHASE_BBM: break-before-make — release is slower than pull-in, so the wave
// parks all-OFF this long between steps; never two relays ON at once.
#define RELAY_STOP_DEADBAND_MS 500u
#define CHASE_BBM_MS 20u
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

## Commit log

2026-09-18 v1.1 final: READMEs everywhere, xlsx regression vector, QEMU notes
    [SOC-DOCKLIGHT.xlsx]
2026-09-21 v2.0: 8-relay sequencer + always-on AP dashboard + spoof window (base frozen, 50/50 tests)
2026-09-21 docs: HANDOFF fully rewritten for v2.0 + release checklist rule; virtual-bus harnesses in-repo; llms/arduino/tools docs synced
2026-09-21 v2.1: website reliability — host web tests, contract gate, 24h sim, Wokwi automation (66/66, zero behavior change)
2026-09-21 ci: fix YAML flow-mapping parse error on token-gated wokwi-sim job
2026-09-21 v2.2: captive portal — login pops on join, fixed 192.168.4.1, full v2.1 wiring/passwords docx (67/67)
    [bms_connection_tester.ino, main.cpp, make_report.py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]
2026-09-21 v2.3: relay count/chase, 2-stage spoof, per-mode holds, industrial pack, logins, OTA (105/105)
2026-09-21 HANDOFF: pre-compaction checkpoint + QEMU staged plan + resume order
2026-09-21 QEMU Stage 0: exact boot-test harness + v2.3 baseline (81x 0x10, 0x10200C gone, JIT-in-proot works)
2026-09-21 QEMU Stage A: SPI trace diagnosis (26-cmd init table, 0x10=wrap-disable byte, crash elsewhere) + trace support
2026-09-21 v2.3.1: no login wall, sticky saves, chase sweeps, spoof GPIO, kill switch, OTA install (103/103)
2026-09-21 v2.4: Tasmota-grade update, per-mode relay menu (R1-R31), console, backup/restore, STA test, info card (134/134)
2026-09-21 v2.5: trigger save, portal landing, structured config, on-demand STA, tolerant JSON, socket harness 64/64, 30-day soak (137/137)
2026-09-23 v2.7: three dashboard variants (FULL default, s3-classic, s3-lite) + live bench SVG + meter readout + sim relay board
2026-09-23 README: v2.7 dashboard section with release snapshots + GIF, sim + enclosure links
2026-09-23 remove Ayca branding: text mentions dropped, meter photo logos redacted, wiring.png regenerated
2026-09-23 Remove device image from README
    Removed image of the device under test from README.
2026-09-26 enclosure: parametric FreeCAD CAD — base, lid2 one-shot cover, tray (3-part print set)
    [base.FCStd, base.stl, lid2.FCStd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]
2026-09-26 Waveshare ESP32-S3-ETH-8DI-8RO board variant (v2.7-ws1)
    - TCA9554PWR relay backend (I2C 0x20, SDA42/SCL41, HIGH=ON)
    - DI1-DI8 mappings (GPIO4-11, active LOW)
    - RS485 auto-direction (TX17/RX18, no DE pin)
    - BOOT=START/STOP, DI1=SPOOF, DI2=Wi-Fi kill, RGB status
    - Wi-Fi retained; Ethernet reserved (not integrated)
    - TCA init: output 0x00 before pin config (no boot glitch)
    - OTA: newest -wsN selection; active-low UI disabled on Waveshare
    - 12 new host tests; 164 total, 0 failures
    - QEMU-verified: RS485, relays, button, spoof, wifi-kill
2026-09-26 v2.8: unified Waveshare release line, meter fumble guard, full docs rebuild
    - FW_VERSION 2.8 for both generic and Waveshare builds; OTA checks
    releases/latest on all lines (retires the -wsN prerelease line)
    - Meter counter: 3 s gap arms reseat candidate, 5 s settle commits;
    verdict snapshot + mid-cycle yank = fail
    - README rewritten in depth; BUILD-DIY.md + BUILD-WAVESHARE.md from
    scratch; wiki overhauled (9 pages); CHANGELOG v2.8
    - firmware/ + firmware-n16r8/ refreshed with v2.8 images + SHAs
    - 166/166 native tests green
    [main.cpp, relay_ctrl.h, test_web.cpp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]
2026-09-26 Remove real meter photos from the repo
    - Delete Actual Meter Image/ (meter cluster + segment close-up JPEGs)
    - Drop photo embeds from wiki/Hardware, wiki/Protocol, docs/MODULES,
    enclosure/README, captures/README
    - 3D sim: procedural canvas meter face instead of photo texture;
    remove /assets photo serving from sim_server.py
    - HANDOFF.md notes updated
2026-09-26 Fix emu driver for v2.8 meter semantics + fw version
    - drive_emu.py expected fw 2.7, firmware is 2.8
    - meter tests now assert 3 s arm + 5 s settle: gap arms candidate
    (no immediate close), commit after 5 s continuous GREEN, fumble
    before settle does not double-count
2026-09-26 emu: derive expected fw version from FW_VERSION source (no drift)
    drive_emu.py read the version from firmware source instead of a
    hardcoded string, so firmware behavior changes can never again
    desync the driver the way v2.8 did (3s-arm/5s-settle).
    Verified: 64/64 emu checks pass against a fresh fw_emu build.
2026-09-27 docs(waveshare): document Wi-Fi defaults (AP ssid/pass, admin pass, kill switch, STA)
2026-09-27 waveshare: fix boot LED color (RGB byte-order swap) and drive it first in setup()
    The 8DI8RO board's RGB element expects RGB byte order, not WS2812-standard
    GRB (Waveshare's own demo works around it the same way:
    RGB_Light(r,g,b) -> neopixelWrite(pin, g, r, b), "RGB color adjustment").
    neopixelWrite() emits GRB on the wire, so our red (silent) state physically
    displayed as green and traffic as red. Swap R/G on the waveshare path.
    Also relocate apply_leds(false) to the very first line of setup() so the
    lamp is driven before I2C/TCA bring-up instead of after.
2026-09-27 docs(waveshare): complete wiring & connection guide
    New docs/waveshare-wiring.md: every screw terminal, RS485 A/B wiring +
    120R termination jumper + reversed-A/B symptoms, relay NO/COM/NC, DI
    opto-input wiring, full indicator table (PWR/TXD/RXD hardware,
    WS2812 GPIO38 firmware), bench bring-up steps, troubleshooting table.
    Also documents why TXD/RXD are hardware-only (no GPIO to drive) and the
    RGB byte-order quirk. Mirrored to the GitHub wiki as Waveshare-Wiring.
2026-09-27 test(qemu): v2.8.1 Waveshare logic emulation harness (32/32 PASS)
    QEMU's esp32s3 machine cannot execute Arduino-ESP32 firmware (proven:
    even minimal hello-world crashes during core init). Host-side harness
    compiles ACTUAL v2.8.1 sources (bms_protocol, relay_ctrl, waveshare_pins)
    with Arduino stubs. Verifies: RGB byte-order fix (RED=[32,0,0],
    GREEN=[0,32,0]), JBD 0x03/0x04/0x05, silence rules, noise robustness
    (10k random bytes, 0 false triggers), TCA9554 0x01-0xFF, GPIO assignments,
    spoof stages (100.0V/88.8V).
    [relay_ctrl.h, waveshare_pins.h]
2026-09-27 waveshare: DI3 (GPIO6) triggers relay sequencer (START/STOP)
    Ground DI3 to COM to start/stop the 8-relay test program, same as the
    BOOT button (follows cfg.button_mode). DI3-DI8 were free; DI1=spoof,
    DI2=WiFi-kill remain unchanged.
2026-09-27 docs(waveshare): correct DI wiring — optos need 7-36V board power, use DI-COM
2026-09-27 waveshare: live DI1-DI8 states on dashboard (diagnose DI wiring)
    Adds "dis":[0/1,...] to status JSON (GPIO4-11) and a DI: readout under
    the relay grid. Lets the user see if DI2 actually goes LOW when shorted,
    isolating firmware vs wiring/hardware for the Wi-Fi kill issue.
    [web_ui.cpp]
2026-09-27 fix test: expect fw 2.8.2 in web status JSON
    [test_web.cpp]
2026-09-27 waveshare: fix DI polarity to active-HIGH (opto drives HIGH)
    The Waveshare DI optocouplers drive GPIO HIGH when active, not LOW.
    With INPUT_PULLUP the pin read HIGH always — no edge, no trigger.
    Fix: INPUT_PULLDOWN + active-HIGH logic for DI1/DI2/DI3 on Waveshare.
    Verified against user test sketch. Bump to 2.8.3.
2026-09-27 waveshare: fix DI4-DI8 pinMode + dashboard labels (v2.8.4)
    - DI4-DI8 (GPIO7-11) were never configured: floating pins on dashboard.
    Now INPUT_PULLDOWN like DI1-3.
    - Dashboard comment corrected: 1=HIGH (active), 0=LOW (idle).
    - waveshare_pins.h comment: active = HIGH.
    [main.cpp, test_web.cpp, waveshare_pins.h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]
2026-09-27 waveshare: revert DI to INPUT_PULLUP/active-LOW (v2.8.5)
    v2.8.3/v2.8.4 changed DI1-DI8 to INPUT_PULLDOWN/active-HIGH based on a
    misleading test sketch. The Waveshare DI optocouplers are NPN open-collector:
    they can ONLY pull the GPIO LOW, never drive it HIGH. With INPUT_PULLDOWN the
    GPIO was stuck LOW forever (idle=LOW, active=LOW) -> no edge, no trigger.
    Revert to INPUT_PULLUP/active-LOW (v2.7 behavior, confirmed by vendor example):
    - setup(): pinMode INPUT_PULLUP for DI1-DI8, debounce begin(true) = idle HIGH
    - loop(): wifi kill, DI3 trigger, spoof all use fell() = grounded = active
    - waveshare_pins.h + dashboard comments corrected
    Added explanatory comments at the pinMode site so this do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
2026-09-27 JBD write ACK: reply_for() returns 6-byte ACK instead of silence (v2.8.6)
    The e-rickshaw meter sends DD A5 03... and expects a response.
    Previously reply_for() returned NULL for writes (option A silence),
    but the meter needs an acknowledgment.
    New behavior: writes get DD <REG> 00 <CK_HI> <CK_LO> 77
    (checksum covers REG+0x00, status=success).
    - src/bms_protocol.h: BMS_WRITE_ACK_LEN define, updated docs
    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
2026-09-27 v2.8.7: RS485 RX/TX diagnostics on /api/state
    - Add diagRxFrame/diagTxFrame buffers in main.cpp, updated on every
    accepted RX frame and every send_frame() TX
    - Expose as rs485rx/rs485tx hex strings in /api/state JSON via WebCtx
    - Clarify v2.8.6 write-ACK comments: ACK only for 0x5A (non-standard);
    DD A5 ... is parsed as read -> 34-byte response (proven by host sim)
    - Host simulation confirms firmware cannot emit 11 2D ... bytes;
    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
2026-09-27 v2.8.8: Waveshare RS485 DE pin on GPIO21 (critical fix)
    The board DOES have an RS485 DE line on GPIO21. We wrongly assumed
    'hardware auto-direction (no DE pin)' from the Waveshare wiki — without
    driving DE, the ESP32 receives nothing on the bus (rs485rx stayed empty
    in v2.8.7 testing). A working reference sketch drives RS485_DE 21.
    - waveshare_pins.h: add WS_PIN_RS485_DE 21
    - main.cpp: PIN_RS485_DE defined for Waveshare; send_frame() drives DE
    HIGH before TX, LOW after (existing 1.5-char guard); setup() parks DE
    LOW (RX mode) at boot
    - web_ui.cpp: pins string updated
    - FW_VERSION bumped to 2.8.8
    [main.cpp, test_web.cpp, waveshare_pins.h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]
2026-09-27 Align Waveshare build to official ESP32-S3-POE-ETH-8DI-8DO demo
    - RS485: use ESP32 UART RS485 half-duplex mode (setPins(-1,-1,-1,21) +
    setMode), mirroring the official 8DO demo WS_RS485.cpp; manual DE
    drive in send_frame() kept only as a setMode() fallback
    - TCA9554 init walks a host-testable step table (OUTPUT reg before
    CONFIG reg, per demo WS_Dout.cpp); parks 0x00 (all OFF) as the safe
    boot state instead of the demo's 0xFF — documented divergence
    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
2026-09-27 Release v2.8.10 — Waveshare 8DO hardware-DE alignment
2026-09-27 Release v2.9.0 — full Waveshare 8DO support: Ethernet, buzzer, fault alarms
    [main.cpp, test_waveshare.cpp, test_web.cpp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]
2026-09-27 v2.9.1: Waveshare RS485 RX fix — Dad's proven init sequence
    The Waveshare build skipped the GPIO21 pinMode(OUTPUT)/digitalWrite(LOW)
    preamble and now goes straight through
    begin -> setPins(-1,-1,-1,21) -> setMode(UART_MODE_RS485_HALF_DUPLEX),
    byte-identical to Dad's working firmware and the official Waveshare demo.
    The preamble coincided with total RX deafness (single byte 'E0' captured,
    no 0xDD ever seen); the UART must own GPIO21 from the start. Generic S3
    builds keep the manual-DE preamble unchanged.
    Also adds rs485hwde to /api/state on Waveshare builds (1 = UART owns
    GPIO21 for hardware DE, 0 = manual DE fallback).
    182/182 native Unity tests + WEB-CONTRACT + 30-day soak (2,591,400 po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
    [main.cpp, test_web.cpp, web_ui.cpp]
2026-09-27 Buzzer web toggle; retire classic/lite variants, FULL dashboard standard
    [check_web_contract.py, main.cpp, relay_ctrl.h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]
2026-09-27 v2.9.2: buzzer web toggle (default off), FULL dashboard standard
    [test_web.cpp]
